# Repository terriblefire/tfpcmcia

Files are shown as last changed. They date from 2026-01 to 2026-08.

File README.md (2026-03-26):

# tfpcmcia

TerribleFire PCMCIA — a custom PCMCIA expansion card for the Amiga 1200 and Amiga 600, providing 4 MB fast RAM, an SD card interface, and 7 programmable RGB LEDs.

---

## Hardware

| Component | Part | Interface |
|---|---|---|
| Microcontroller | WCH CH32V307 (RISC-V, 144 MHz) | — |
| SPI RAM | APS6404L-3SQR, 4 MB | SPI1 @ 72 MHz |
| SD card | Standard microSD | SPI3 @ 36 MHz |
| LEDs | 7× APA102C RGB | GPIO (bit-banged) |

The card plugs into the Amiga's PCMCIA slot. The CH32V307 bridges the PCMCIA bus to an SPI RAM chip and SD card. The Amiga CPU accesses them entirely through memory-mapped reads and writes — the MCU handles all bus timing under interrupt.

---

## Memory Map

From the Amiga's perspective:

| Amiga address | Content | Notes |
|---|---|---|
| `$600000–$61FFFF` | Boot ROM (128 KB) | At power-on only; switches to SPIRAM after boot |
| `$620000–$9FFFFF` | SPIRAM (≈4 MB) | Fast RAM, available after driver init |
| `$A00000–$A001FF` | Attribute memory | PCMCIA CIS tuples (REG=1 accesses) |
| `$A20200–$A2023B` | I/O registers | Control, SPI, LED framebuffer |

The first 128 KB of SPIRAM overlaps the boot ROM window. After driver initialisation, `BOARD_CTRL` bit 0 is set, which switches that window from ROM to SPIRAM and makes the full 4 MB available as expansion memory.

---

## I/O Registers

All registers sit in PCMCIA I/O space. The Amiga's Gayle chip maps card I/O to `$A20000`; register byte offsets are relative to the card's I/O base (`0x220000`). The 68000 bus is 16 bits wide; each register occupies the upper byte of a 16-bit word (big-endian convention).

| Address | Offset | R/W | Name | Description |
|---|---|-----|---|---|
| `$A20200` | `0x200` | R/W | `SPI_DATA` | Write a byte to clock it out to the SD card; read to get the last byte clocked in |
| `$A20202` | `0x202` | W | `SPI_CS` | SD card chip select — `$00` = assert (active LOW), `$FF` = deassert |
| `$A20204` | `0x204` | R | `SPI_STATUS` | Bit 0: SD card detect (`1` = card present) |
| `$A20206` | `0x206` | R/W | `BOARD_CTRL` | Bit 0: `0` = boot ROM mapped, `1` = SPIRAM mapped; also controls LED mode |
| `$A20208` | `0x208` | R | `BOARD_ID` | Board identifier, always reads `$01` |
| `$A20220–$A2023B` | `0x220–0x23B` | W | `LED_FB` | LED framebuffer — 7 pixels × 4 bytes; see LED section |

---

## Boot Sequence

1. **CIS parsing** — Kickstart's `card.resource` reads the Card Information Structure from attribute memory (`$A00000`) and locates the `CISTPL_AMIGAXIP` (Execute-In-Place) tuple with the `AUTORUN` flag.

2. **XIP entry** — Kickstart calls `InitResident()` on the RomTag at `$600000`.

3. **Boot ROM init** — The ROM code:
   - Parses the embedded `tfpcmcia.device` (standard Amiga HUNK executable) from the ROM image
   - Allocates chip RAM, copies hunks, applies `HUNK_RELOC32` relocations
   - Calls `CacheClearU()` to flush CPU caches
   - Scans the loaded code for a RomTag and calls `InitResident()` on it

4. **Device init** — `tfpcmcia.device`:
   - Registers itself with Exec
   - Initialises the SD card via SPI (supports SDv1, SDv2, SDHC)
   - Creates an I/O task for asynchronous SD operations
   - Probes SPIRAM and, if present, adds a 1 MB block to the system free memory list (`AddMemList`, `MEMF_PUBLIC | MEMF_FAST`)
   - Scans the SD card for an RDB (Rigid Disk Block)

5. **RDB mounting** — Reads the partition table, loads filesystem handlers from LSEG blocks, creates DOS nodes via `MakeDosNode` / `AddBootNode`.

6. **DOS boot** — Calls `InitResident("dos.library")`. AmigaDOS picks the highest-priority bootable partition and continues the boot.

7. **ROM→SPIRAM switch** — After setup, the boot code copies a small trampoline onto the stack, flushes caches, jumps to the trampoline, then writes `BOARD_CTRL` bit 0 to switch the `$600000` window from ROM to SPIRAM. The full 4 MB is now available as fast RAM.

### A600 notes

On the A600 with Kickstart 3.0, the Gayle PCMCIA disable bit must be toggled in the DIAG handler to enable XIP boot. This is handled automatically by the boot ROM.

---

## SPIRAM

The 4 MB SPI RAM (APS6404L) is cached inside the CH32V307's 32 KB SRAM using a direct-mapped write-back cache:

- **512 cache lines × 64 bytes** = 32 KB cache
- **Address decomposition:** tag (7 bits) | line index (9 bits) | byte offset (6 bits)
- On a cache miss, any dirty line is evicted (written back via SPI burst) before the new line is fetched
- SPI transfers use 16-bit burst mode for maximum throughput (~9 MB/s)

From the Amiga driver's perspective, SPIRAM is transparent: ordinary memory reads and writes go through the cache without any special handling.

---

## LED System

Seven APA102C RGB LEDs are driven from two GPIO lines (clock + data) using a bit-banged serial protocol. The active LED mode is determined by `BOARD_CTRL` bit 0.

### KITT mode (bit 0 = 0, default)

Before the driver loads — and any time `BOARD_CTRL` bit 0 is clear — the firmware runs an autonomous scanner animation: a red spot bounces back and forth across all 7 LEDs with a short brightness tail, updating once per millisecond.

### Framebuffer mode (bit 0 = 1)

Once the driver sets `BOARD_CTRL` bit 0, the firmware switches to host-controlled mode. The Amiga driver paints arbitrary colours by writing to the `LED_FB` registers at `$A20220`.

#### LED framebuffer format

7 pixels, 4 bytes each (28 bytes total, `$A20220–$A2023B`). Each pixel occupies two consecutive 16-bit I/O writes:

| Write | Address offset | Upper byte [15:8] | Lower byte [7:0] |
|---|---|---|---|
| 1st | `0x220 + pixel×4` | Red | Green |
| 2nd | `0x222 + pixel×4` | Blue | Unused |

Pixel 0 is at `$A20220`, pixel 1 at `$A20224`, …, pixel 6 at `$A20238`.

---

## PCMCIA Interface (firmware)

The CH32V307 services every PCMCIA bus cycle under interrupt (`WCH-Interrupt-fast`). The interrupt handler runs entirely from RAM (`.ramtext` section) and is flattened / always-inlined to avoid register corruption in the fast-interrupt ABI.

Cycle types handled:

| Cycle | Action |
|---|---|
| Attribute memory read | Returns CIS tuple bytes (see below) |
| Common memory read, addr < 128 KB | Returns boot ROM byte pair |
| Common memory read, addr ≥ 128 KB | Returns SPIRAM data (cached) |
| Common memory write | Writes to SPIRAM (cached) |
| I/O read | Returns register value |
| I/O write | Updates register or LED framebuffer |

The Gayle chip swaps D0–D7 with D8–D15 relative to the 68000. Every value written to the data bus goes through `BUS16()` to compensate.

### CIS tuples (attribute memory)

| Tuple | Content |
|---|---|
| `CISTPL_DEVICE` (0x01) | SRAM, 250 ns, 4 MB |
| `CISTPL_VERS_1` (0x15) | Manufacturer: "TerribleFire", Product: "PCMCIA SD+RAM", Version: "1.0" |
| `CISTPL_FUNCID` (0x21) | Memory card |
| `CISTPL_AMIGAXIP` (0x91) | Execute-in-place, AUTORUN flag set |
| `CISTPL_END` (0xFF) | — |

---

## Amiga Driver (`tfpcmcia.device`)

Standard Amiga block device. Supports:

- `TD_READ64` / `TD_WRITE64` / `TD_SEEK64`
- `HD_SCSICMD`
- `NSCMD_DEVICEQUERY` / `NSCMD_TD_READ64` / `NSCMD_TD_WRITE64`

SD card geometry presented to the OS: 512-byte blocks, 16 heads, 32 sectors/track.

---

## Building

### Firmware

Open the project in MounRiver Studio (or use the provided Makefile under `firmware/`) and build for CH32V307. Flash with WCH-ISP (macOS binary included in `wchisp-macos-x64/`).

### Driver / boot ROM

```sh
cd driver
make
```

Produces `tfpcmcia.rom` — the 128 KB image that the firmware exposes as the boot ROM.

### MAME testing

The board is emulated as the `tfpcmcia` PCMCIA device:

```sh
mame a1200 -pcmcia tfpcmcia -hard2 sdcard.hdf -debug
```

To capture the driver's serial debug output:

```sh
mame a1200 -pcmcia tfpcmcia -hard2 sdcard.hdf \
  -rs232 null_modem -bitb socket.127.0.0.1:1234
# in another terminal:
nc -l 1234
```

Copy a freshly built ROM into MAME's ROM path:

```sh
cp driver/tfpcmcia.rom /path/to/mame/roms/tfpcmcia/
```

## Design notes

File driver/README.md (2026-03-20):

# TerribleFire PCMCIA Driver

Amiga device driver and boot ROM for the TerribleFire PCMCIA board — a custom PCMCIA card for the Amiga 1200 featuring a CH32V307 MCU, SD card slot, and 4MB SPIRAM.

## Overview

The board plugs into the A1200's PCMCIA slot and provides:

- **4MB SPIRAM** mapped into the PCMCIA common memory space ($600000–$9FFFFF), usable as fast RAM
- **SPI SD card interface** exposed through I/O space registers
- **128KB boot ROM** that loads and initializes the device driver at cold boot, then switches to SPIRAM mode

The CH32V307 MCU on the board handles SPI bus arbitration and SD card communication. The Amiga CPU communicates with it through memory-mapped registers in the PCMCIA I/O space.

## Memory Map

### Common Memory ($600000–$9FFFFF)

At power-on, the first 128KB ($600000–$61FFFF) contains the boot ROM. After the driver initializes, `BOARD_CTRL` bit 0 switches this region to SPIRAM, giving the full 4MB to the system.

### I/O Space Registers ($A20000+)

All registers are at even byte addresses (68000 bus convention):

| Address | Name | R/W | Description |
|---|---|-----|---|
| `$A20200`  | `SPI_DATA` | R/W | SPI data register — write a byte to clock it out, read to get the byte clocked in |
| `$A20202`  | `SPI_CS` | W | SPI chip select — `$00` = assert (active), `$FF` = deassert |
| `$A20204`  | `SPI_STATUS` | R | Status register — bit 0: SD card detect (1 = card present) |
| `$A20206`  | `BOARD_CTRL` | W | Board control — bit 0: SPIRAM mode (1 = SPIRAM, 0 = boot ROM) |
| `$A20208`  | `BOARD_ID` | R | Board identification — reads `$01` |

## Boot Sequence

1. **CIS parsing** — Kickstart's `card.resource` reads the Card Information Structure from attribute memory and finds the `CISTPL_AMIGAXIP` (Execute-In-Place) tuple
2. **XIP entry** — Kickstart calls `InitResident()` on the RomTag at `$600000`
3. **Boot ROM init** — The ROM code:
   - Parses the embedded `tfpcmcia.device` (Amiga hunk executable) from ROM
   - Allocates RAM, copies hunks, applies HUNK_RELOC32 relocations
   - Flushes the CPU caches (`CacheClearU`)
   - Scans for a RomTag in the loaded code and calls `InitResident()` on it
4. **Device init** — `tfpcmcia.device` registers itself, initializes the SD card via SPI, creates an I/O task, then scans the SD card for an RDB (Rigid Disk Block)
5. **RDB mounting** — Reads partition table, loads any filesystem handlers from LSEG blocks, creates DOS nodes via `MakeDosNode`/`AddBootNode`
6. **DOS boot** — Calls `InitResident("dos.library")` to start AmigaDOS, which picks the highest-priority bootable partition

After initialization, the boot ROM copies a small trampoline to the stack, flushes caches, jumps to it, and writes `BOARD_CTRL` to switch from ROM to SPIRAM mode. The 4MB SPIRAM is then available as expansion memory.

## MAME Testing

The board is emulated in MAME as the `tfpcmcia` PCMCIA device. To test with the A1200 emulation:

```sh
mame a1200 -pcmcia tfpcmcia -hard2 sdcard.hdf -debug
```

The MAME emulation (`tfpcmcia.cpp`) implements the full register set, SPI SD card interface, boot ROM, and SPIRAM switching. The boot ROM binary is loaded from the MAME ROM path.

To see the driver's serial debug output (`kprintf`), add a null modem on the RS-232 port and listen with netcat:

```sh
mame a1200 -pcmcia tfpcmcia -hard2 sdcard.hdf -debug \
  -rs232 null_modem -bitb socket.127.0.0.1:1234
```

In another terminal:

```sh
nc -l 1234
```

To build a new ROM and update MAME's copy:

```sh
cd driver
make
cp tfpcmcia.rom ../path/to/mame/roms/tfpcmcia/
```

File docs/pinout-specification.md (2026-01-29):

# TFPCMCIA Pin Specification
**CH32V303VCT6 PCMCIA Card - Complete Pin Assignment**

Date: 2026-01-29
Hardware Version: 1.0
Total GPIO Pins: 80 (5 ports × 16 pins)
Pins Used: 65 (81% utilization)
Pins Available: 15 (19% expansion capacity)

---

## GPIOA - SPI, Audio, Debug, Status (13/16 used)

| Pin | Signal | Direction | Function | Configuration | Notes |
|-----|---|---|---|---|---|
| PA0 | STATUS_LED | Output | Status indicator LED | Push-pull, 50MHz | Optional, active HIGH |
| PA1 | SPIRAM_CS | Output | SPI RAM chip select | Push-pull, 50MHz | Manual GPIO, active LOW |
| PA2 | **READY** | **Output** | **PCMCIA READY signal** | **Push-pull, 50MHz** | **Active HIGH when ready** |
| PA3 | - | - | **AVAILABLE** | - | - |
| PA4 | DAC_OUT1/BVD2 | Output | Audio to Amiga | Analog | 12-bit DAC, connects to PCMCIA BVD2 |
| PA5 | SPI1_SCK | Output | SPI RAM clock | Alternate function | 72 MHz max |
| PA6 | SPI1_MISO | Input | SPI RAM data in | Alternate function | Floating |
| PA7 | SPI1_MOSI | Output | SPI RAM data out | Alternate function | 72 MHz max |
| PA8 | BOOTLOADER | Input | Programming mode detect | Pull-down | Active HIGH enters programming |
| PA9 | - | - | **AVAILABLE** | - | - |
| PA10 | USART1_RX | Input | Debug UART receive | Alternate function | **RESERVED** |
| PA11 | USART1_TX | Output | Debug UART transmit | Alternate function | **RESERVED** |
| PA12 | - | - | **AVAILABLE** | - | - |
| PA13 | SWDIO | I/O | SWD debug data | Alternate function | **RESERVED** |
| PA14 | SWCLK | Input | SWD debug clock | Alternate function | **RESERVED** |
| PA15 | SD_CD | Input | SD card detect | Pull-up | Active LOW when card inserted |

**Interface Summary:**
- **SPI1 (SPI RAM):** PA1 (CS), PA5 (SCK), PA6 (MISO), PA7 (MOSI) @ 72 MHz max
- **Audio:** PA4 (DAC → BVD2)
- **Debug:** PA10-PA11 (UART), PA13-PA14 (SWD)
- **Status:** PA0 (LED), PA2 (READY), PA8 (Boot mode), PA15 (SD detect)
- **Available:** PA3, PA9, PA12

---

## GPIOB - Address, Control Signals (16/16 used) ⚠️ **FULLY ALLOCATED**

| Pin | Signal | Direction | Function | Configuration | Notes |
|-----|---|---|---|---|---|
| PB0 | A16 | Input | Address bit 16 | Floating | |
| PB1 | A17 | Input | Address bit 17 | Floating | |
| PB2 | A18 | Input | Address bit 18 | Floating | |
| PB3 | A19 | Input | Address bit 19 | Floating | |
| PB4 | A20 | Input | Address bit 20 | Floating | |
| PB5 | A21 | Input | Address bit 21 | Floating | 22-bit total (4MB) |
| PB6 | CE1/UDS | Input | Upper Data Strobe | Pull-up | **EXTI6 interrupt**, active LOW |
| PB7 | OE | Input | Memory Output Enable | Pull-up | Memory read cycle, active LOW |
| PB8 | WE | Input | Memory Write Enable | Pull-up | Memory write cycle, active LOW |
| PB9 | CE2/LDS | Input | Lower Data Strobe | Pull-up | **EXTI9 interrupt**, active LOW |
| PB10 | REG | Input | Attribute memory select | Pull-up | 0=Common, 1=Attribute |
| PB11 | IOR | Input | I/O Read strobe | Pull-up | I/O read cycle, active LOW |
| PB12 | IOW | Input | I/O Write strobe | Pull-up | I/O write cycle, active LOW |
| PB13 | RESET | Input | Card reset | Pull-up | Active LOW |
| PB14 | WAIT | Output | Wait state control | Push-pull, 50MHz | LOW=insert waits, HIGH=no wait |
| PB15 | IOIS16 | Output | 16-bit I/O indicator | Push-pull, 50MHz | Optional use |

**Interface Summary:**
- **Address High:** PB0-PB5 (A16-A21)
- **Memory Control:** PB6 (UDS), PB7 (OE), PB8 (WE), PB9 (LDS), PB10 (REG)
- **I/O Control:** PB11 (IOR), PB12 (IOW)
- **System Control:** PB13 (RESET), PB14 (WAIT), PB15 (IOIS16)
- **Interrupts:** EXTI6 (PB6/UDS), EXTI9 (PB9/LDS) → both trigger PCMCIA_Handler

**Control Signal Groups:**
1. **Memory Access:** OE (read) OR WE (write)
2. **I/O Access:** IOR (read) OR IOW (write)
3. **Byte/Word Select:** UDS+LDS (word), UDS only (upper byte), LDS only (lower byte)

---

## GPIOC - SD Card SPI (4/16 used)

| Pin | Signal | Direction | Function | Configuration | Notes |
|-----|---|---|---|---|---|
| PC0 | - | - | **AVAILABLE** | - | - |
| PC1 | - | - | **AVAILABLE** | - | - |
| PC2 | - | - | **AVAILABLE** | - | - |
| PC3 | - | - | **AVAILABLE** | - | - |
| PC4 | - | - | **AVAILABLE** | - | - |
| PC5 | - | - | **AVAILABLE** | - | - |
| PC6 | - | - | **AVAILABLE** | - | - |
| PC7 | - | - | **AVAILABLE** | - | - |
| PC8 | - | - | **AVAILABLE** | - | - |
| PC9 | SD_CS | Output | SD card chip select | Push-pull, 50MHz | Manual GPIO, active LOW |
| PC10 | SPI3_SCK | Output | SD card SPI clock | Alternate function | 36 MHz max |
| PC11 | SPI3_MISO | Input | SD card SPI data in | Alternate function | Floating |
| PC12 | SPI3_MOSI | Output | SD card SPI data out | Alternate function | 36 MHz max |
| PC13 | - | - | **AVAILABLE** | - | - |
| PC14 | - | - | **AVAILABLE** | - | - |
| PC15 | - | - | **AVAILABLE** | - | - |

**Interface Summary:**
- **SPI3 (SD Card):** PC9 (CS), PC10 (SCK), PC11 (MISO), PC12 (MOSI) @ 36 MHz max
- **Available:** PC0-PC8, PC13-PC15 (12 pins for future expansion)

---

## GPIOD - Data Bus (16/16 used) ⚠️ **FULLY ALLOCATED**

| Pin | Signal | Direction | Function | Configuration | Notes |
|-----|---|---|---|---|---|
| PD0 | D0 | I/O | Data bit 0 | Bidirectional | Start as input floating |
| PD1 | D1 | I/O | Data bit 1 | Bidirectional | Switch to output on read |
| PD2 | D2 | I/O | Data bit 2 | Bidirectional | |
| PD3 | D3 | I/O | Data bit 3 | Bidirectional | |
| PD4 | D4 | I/O | Data bit 4 | Bidirectional | |
| PD5 | D5 | I/O | Data bit 5 | Bidirectional | |
| PD6 | D6 | I/O | Data bit 6 | Bidirectional | |
| PD7 | D7 | I/O | Data bit 7 | Bidirectional | |
| PD8 | D8 | I/O | Data bit 8 | Bidirectional | |
| PD9 | D9 | I/O | Data bit 9 | Bidirectional | |
| PD10 | D10 | I/O | Data bit 10 | Bidirectional | |
| PD11 | D11 | I/O | Data bit 11 | Bidirectional | |
| PD12 | D12 | I/O | Data bit 12 | Bidirectional | |
| PD13 | D13 | I/O | Data bit 13 | Bidirectional | |
| PD14 | D14 | I/O | Data bit 14 | Bidirectional | |
| PD15 | D15 | I/O | Data bit 15 | Bidirectional | |

**Interface Summary:**
- **Data Bus:** Full 16-bit on single port for atomic operations
- **Access:** Read via `GPIOD->INDR`, write via `GPIOD->OUTDR`
- **Mode Control:** `CFGLR` (D0-D7), `CFGHR` (D8-D15)
- **Configuration Values:**
  - Input: `0x44444444` (floating input)
  - Output: `0x33333333` (push-pull, 50MHz)

---

## GPIOE - Address Bus Low (16/16 used) ⚠️ **FULLY ALLOCATED**

| Pin | Signal | Direction | Function | Configuration | Notes |
|-----|---|---|---|---|---|
| PE0 | A0 | Input | Address bit 0 | Floating | |
| PE1 | A1 | Input | Address bit 1 | Floating | |
| PE2 | A2 | Input | Address bit 2 | Floating | |
| PE3 | A3 | Input | Address bit 3 | Floating | |
| PE4 | A4 | Input | Address bit 4 | Floating | |
| PE5 | A5 | Input | Address bit 5 | Floating | |
| PE6 | A6 | Input | Address bit 6 | Floating | |
| PE7 | A7 | Input | Address bit 7 | Floating | |
| PE8 | A8 | Input | Address bit 8 | Floating | |
| PE9 | A9 | Input | Address bit 9 | Floating | |
| PE10 | A10 | Input | Address bit 10 | Floating | |
| PE11 | A11 | Input | Address bit 11 | Floating | |
| PE12 | A12 | Input | Address bit 12 | Floating | |
| PE13 | A13 | Input | Address bit 13 | Floating | |
| PE14 | A14 | Input | Address bit 14 | Floating | |
| PE15 | A15 | Input | Address bit 15 | Floating | |

**Interface Summary:**
- **Address Low:** PE0-PE15 (A0-A15)
- **Combined with GPIOB[0-5]:** 22-bit address (A0-A21) = 4MB address space
- **Address Read:** `addr = GPIOE->INDR | ((GPIOB->INDR & 0x3F) << 16)`

---

## Pin Usage Statistics

| Port | Total Pins | Used | Available | Utilization |
|---|---|---|---|---|
| GPIOA | 16 | 13 | 3 | 81% |
| GPIOB | 16 | 16 | 0 | **100%** ✓ |
| GPIOC | 16 | 4 | 12 | 25% |
| GPIOD | 16 | 16 | 0 | **100%** ✓ |
| GPIOE | 16 | 16 | 0 | **100%** ✓ |
| **Total** | **80** | **65** | **15** | **81%** |

---

## Functional Pin Grouping

### Address Bus (22 bits)
- **A0-A15:** GPIOE[0-15] (lower 16 bits)
- **A16-A21:** GPIOB[0-5] (upper 6 bits)
- **Address Space:** 0x000000 - 0x3FFFFF (4 MB)

### Data Bus (16 bits)
- **D0-D15:** GPIOD[0-15] (full 16-bit data)
- **Advantage:** Single port = atomic 16-bit read/write

### Memory Control Signals
- **CE1/UDS:** GPIOB[6] - Upper Data Strobe, EXTI6 interrupt
- **CE2/LDS:** GPIOB[9] - Lower Data Strobe, EXTI9 interrupt
- **OE:** GPIOB[7] - Memory read cycle
- **WE:** GPIOB[8] - Memory write cycle
- **REG:** GPIOB[10] - Attribute memory select

### I/O Control Signals
- **IOR:** GPIOB[11] - I/O read cycle
- **IOW:** GPIOB[12] - I/O write cycle
- **IOIS16:** GPIOB[15] - 16-bit I/O indicator

### System Control
- **RESET:** GPIOB[13] - Card reset input
- **WAIT:** GPIOB[14] - Wait state output (cycle extension)
- **READY:** GPIOA[2] - Card ready output (operational status)

### SPI1 Interface (SPI RAM @ 72 MHz)
- **CS:** GPIOA[1] (manual control)
- **SCK:** GPIOA[5]
- **MISO:** GPIOA[6]
- **MOSI:** GPIOA[7]
- **Bus:** APB2 (144 MHz ÷ 2 = 72 MHz max)

### SPI3 Interface (SD Card @ 36 MHz)
- **CS:** GPIOC[9] (manual control)
- **SCK:** GPIOC[10]
- **MISO:** GPIOC[11]
- **MOSI:** GPIOC[12]
- **Bus:** APB1 (72 MHz ÷ 2 = 36 MHz max)

### Audio Interface
- **DAC_OUT1:** GPIOA[4] - 12-bit DAC output to PCMCIA BVD2 pin

### Debug/Programming
- **UART:** GPIOA[10] (RX), GPIOA[11] (TX)
- **SWD:** GPIOA[13] (SWDIO), GPIOA[14] (SWCLK)
- **Bootloader:** GPIOA[8] - Programming mode detect

### Status Indicators
- **Status LED:** GPIOA[0] - General status indicator
- **SD Detect:** GPIOA[15] - SD card presence (LOW = inserted)
- **READY:** GPIOA[2] - Card operational status (HIGH = ready)

---

## Available Pins for Future Expansion

### GPIOA (3 pins)
- PA3
- PA9
- PA12

### GPIOC (12 pins)
- PC0, PC1, PC2, PC3, PC4, PC5, PC6, PC7, PC8
- PC13, PC14, PC15

**Total Available:** 15 pins

**Potential Future Uses:**
- Additional I/O ports
- Hardware flow control signals
- Additional status LEDs
- External interrupt inputs
- PWM outputs
- Additional SPI/I2C interfaces

---

## Pin Configuration Register Values

### Quick Reference

**Input Floating (Address/Data read):**
```c
0x44444444  // Each nibble = 0x4 (floating input)
```

**Output Push-Pull 50MHz:**
```c
0x33333333  // Each nibble = 0x3 (push-pull, 50MHz)
```

**Input Pull-Up (Control signals):**
```c
GPIO_Mode_IPU  // Use HAL functions for non-contiguous pins
```

**Analog (DAC):**
```c
GPIO_Mode_AIN  // Analog mode
```

**Alternate Function Push-Pull:**
```c
GPIO_Mode_AF_PP  // For SPI SCK/MOSI pins
```

---

## PCMCIA Connector Mapping

### Key PCMCIA Pins

| PCMCIA Pin | Signal | CH32 Pin | Direction | Notes |
|---|---|---|---|---|
| 16 | READY | PA2 | Output | Active HIGH when ready |
| 36 | CD1 | - | - | Hard-wired to GND on PCB |
| 43 | OE | PB7 | Input | Memory read enable |
| 44 | WE | PB8 | Input | Memory write enable |
| 59 | WAIT | PB14 | Output | Active LOW inserts waits |
| 60 | IOIS16 | PB15 | Output | 16-bit I/O indicator |
| 61 | REG | PB10 | Input | Attribute memory select |
| 62 | BVD2 | PA4 | Output | Audio output via DAC |
| 63 | CD2 | - | - | Hard-wired to GND on PCB |
| 7,39 | CE1/UDS | PB6 | Input | Upper data strobe |
| 24,56 | CE2/LDS | PB9 | Input | Lower data strobe |
| Various | A0-A21 | PE0-15, PB0-5 | Input | 22-bit address bus |
| Various | D0-D15 | PD0-15 | I/O | 16-bit data bus |

---

## Interrupt Configuration

### EXTI Lines

| EXTI Line | GPIO Pin | Signal | Trigger | Priority | Handler |
|---|---|---|---|---|---|
| EXTI6 | PB6 | CE1/UDS | Falling edge | 0 (highest) | PCMCIA_Handler |
| EXTI9 | PB9 | CE2/LDS | Falling edge | 0 (highest) | PCMCIA_Handler |

**Notes:**
- Both interrupts share IRQ handler: `EXTI9_6_IRQn`
- Use WCH fast interrupt mode: `SetVTFIRQ()`
- Handler clears both flags: `EXTI->INTFR = EXTI_Line6 | EXTI_Line9`
- Either UDS or LDS falling triggers the handler

---

## Timing Critical Paths

### Bus Cycle Timing (Target: <120ns)

1. **Interrupt Latency:** ~55ns (WCH-Interrupt-fast mode)
2. **Address Read:** ~14ns (2 GPIO port reads)
3. **Memory Decode:** ~20ns (if/else logic)
4. **Data Output:** ~21ns (GPIO mode switch + write)
5. **Total:** ~110ns ✓ (10ns margin)

### Critical Registers

**Direct access for speed (no HAL):**
- `GPIOE->INDR` - Address low (A0-A15)
- `GPIOB->INDR` - Address high (A16-A21) + control signals
- `GPIOD->INDR` - Data bus read
- `GPIOD->OUTDR` - Data bus write
- `GPIOD->CFGLR/CFGHR` - Data bus direction
- `EXTI->INTFR` - Interrupt flag clear

---

## Design Notes

### Address Space (Card Perspective)
```
0x000000 - 0x03FFFF: ROM (256KB, Flash-based)
0x040000 - 0x1FFFFF: SPI RAM (1.75MB, optional)
0x1F0000 - 0x1F00FF: I/O Ports (256 bytes)
0x200000 - 0x3FFFFF: Unmapped
Attribute Memory: 512 bytes (REG=1)
```

### Amiga Memory Map
```
$600000 - $63FFFF: ROM
$640000 - $7FFFFF: SPI RAM
$9F0000 - $9F00FF: I/O Ports
$A00000 - $A001FF: Attribute Memory
```

### Signal Polarity Reference

**Active LOW:**
- All PCMCIA control inputs (OE, WE, IOR, IOW, UDS, LDS, RESET)
- Chip selects (SPIRAM_CS, SD_CS)
- SD card detect (SD_CD)
- WAIT output

**Active HIGH:**
- READY output
- Status LED
- Data bus (when driven)
- IOIS16 (when asserted)

---

## Revision History

| Version | Date | Changes |
|---|---|---|
| 1.0 | 2026-01-29 | Initial pinout specification |
|  |  | - Added IOR/IOW on PB11/PB12 |
|  |  | - Added READY on PA2 |
|  |  | - Added SD_CD on PA15 |

---

**End of Pin Specification**

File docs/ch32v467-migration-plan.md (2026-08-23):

# CH32V307VCT6 + APS6404L → CH32V467VET6 Migration Plan

Date: 2026-08-15 (revised 2026-08-22)
Source: `docs/CH32V407DS0.PDF` (CH32V407/V467 Datasheet V1.2)
Status: schematic and board connectivity complete — see §10.

Goal: replace the CH32V307VCT6 **and** the external APS6404L SPI RAM with a single
CH32V467VET6 (8 MB on-chip PSRAM), keeping all existing tfpcmcia functionality,
with **every Amiga-facing pin on a 5 V-tolerant (FT) pad**.

---

## 1. What the silicon actually forces

### 1.1 Part selection

Only one variant is viable:

| Model | Pins | GPIO | PSRAM | Verdict |
|---|---|---|---|---|
| CH32V467**VET6** | LQFP100 14×14 0.5 mm | 76 | **8 MB** | ✅ the only option |
| CH32V467WEU6 | QFN68 8×8 | 54 | 8 MB | ❌ need ~63 GPIO |
| CH32V467RET6 | LQFP64 7×7 | 48 | 4 MB only | ❌ |

The LQFP100 land pattern is **identical to the current CH32V307VCT6** — the footprint
does not change, only the netlist and routing.

Other deltas vs. the V307: 200 MHz core (vs 144), 200 KB SRAM (vs 32/64 KB),
992 KB flash, and PSRAM linearly memory-mapped at **`0x8000_0000`–`0x8080_0000`**.

### 1.2 Package pinout deltas (V307VCT6 → V467VET6)

The differences are confined to pins 38–55 plus 73/74:

| Pin | CH32V307VCT6 | CH32V467VET6 |
|-----|---|---|
| 38 | PE7 | PE8 |
| 39 | PE8 | PE9 |
| 40 | PE9 | **VDDK** |
| 41 | PE10 | VSS |
| 42–45 | PE11–PE14 | **MDIRN / MDIRP / MDITN / MDITP** (Ethernet PHY) |
| 46 | PE15 | VDD |
| 47 | PB10 | VSS |
| 48 | PB11 | **VDD18** (PSRAM 1.8 V rail — `PE7` on the V407) |
| 49 | VSS | PB10 |
| 50 | VDD | PB11 |
| 51 | PB12 | **PD8** |
| 52–55 | PB13–PB15, PD8 | PB12–PB15 |
| 73 | NC | **PE10** |
| 74 | VSS | **PE11** |

⚠️ **Pins 73/74 are easy to miss.** The current board ties pad 74 to GND (it is
`VSS_2` in the STM32F103VET6 library part). On the V467 that pad is **PE11** — a
GPIO. Leaving it strapped to ground would short an output. Pad 73 goes from NC to
PE10.

**Consequence: `PE7`, `PE13`, `PE14`, `PE15` do not exist on any CH32V407/V467 package.**
Port E is only `PE0–PE6` + `PE8–PE12` = 12 pins.

> The current design puts A0–A15 on PE0–PE15 for an atomic single-port address read.
> **That is no longer possible** — and it can't be recovered by moving things around,
> because Port D (the only remaining contiguous 16-bit port) holds the data bus.
> Address reassembly in the ISR is unavoidable. See §5.

We are not using Ethernet, so pins 42–45 are left NC (no magnetics, no RJ45).

### 1.3 5 V tolerance map (CH32V467VET6)

Datasheet Table 2-1, `I/O structure` column: `FT` = 5 V tolerant, `HS` = 100 MHz
capable. Absolute max input on non-FT pins is `VDD + 0.3 V`.

**5 V tolerant (53 pins):**

| Port | FT pins | Count |
|---|---|---|
| A | PA8, PA9, PA10, PA13, PA14, PA15 | 6 |
| B | PB2, PB3, PB4, PB5, PB8–PB15 | 12 |
| C | PC6–PC12 | 7 |
| D | PD0–PD15 | **16** |
| E | PE0–PE6, PE8–PE12 | 12 |

**NOT 5 V tolerant (23 pins):** PA0–PA7, PA11, PA12 (USB1), PB0, PB1,
**PB6, PB7 (USBHS2 D−/D+)**, PC0–PC5, PC13–PC15.

This kills four placements in the current design outright:

- `CE1` on **PB6** and `OE` on **PB7** — these are the USB HS2 PHY pads on this part.
- `A16`/`A17` on **PB0/PB1**.
- `READY` on **PA2**.

---

## 2. Pin budget

Amiga-facing signals: **49**
- A0–A21 (22 in), D0–D15 (16 bidir), CE1/CE2/OE/WE/IORD/IOWR/REG/RESET (8 in),
  WAIT/READY/IOCS16 (3 out).

All 49 land on FT pads. The BVD2 audio output was the one exception; the audio stage
has since been removed from the design, so there is no longer any non-FT Amiga-facing
signal at all (see §6.4).

Available FT pins: **53**, less PD0–PD15 for the data bus = 37, less PE12 (BOOT0,
needs a pull-down and must stay low at power-up) = 36, less PA13/PA14 (SWD) = **34**.

**34 available vs 33 needed. One spare.** It fits — but only because dropping the
SPI RAM frees SPI1 (PA5/PA6/PA7, non-FT) for the SD card, which in turn releases
PC10/PC11/PC12 (FT) for the bus. That swap is what makes the whole thing close.

Everything that isn't Amiga-facing fits comfortably on the 23 non-FT pins:
SD SPI1, SD_CS, SD_CD, LED clk/data, 2 status LEDs, debug UART — 11 of 23 used.

---

## 3. Option A — pure re-map, no external glue *(recommended)*

All 33 5 V signals on FT pads. No added parts. Removes the APS6404L from the BOM.
See §7 for the full map and §7.1 for how the layout was derived.

**Pros:** no BOM additions, SWD retained, A0 retained, identical footprint, every
control-signal bitmask in `pcmcia.h` survives unchanged.
**Cons:** 1 spare FT pin (PB2); address reassembly costs ~12 instructions in the
ISR instead of 5, and the ISR needs a third GPIO read.

## 4. Option B — Option A plus slack

Two independent levers, either or both:

- **Drop A0.** It is already masked off in every firmware path
  (`RomMask = 0x1FFFE`, `SpiRamMask = 0x3FFFFE`); byte selection comes from
  UDS/LDS. Frees 1 FT pin.
- **Give up SWD** (PA13/PA14) and program via the WCH USB bootloader plus the debug
  UART. Frees 2 FT pins. ⚠️ **The USB breakout (JP1) has since been removed**, so this
  lever now costs a board change to expose PA11/PA12 again — it is no longer free.

Taking both gives **3–4 spare FT pins**, which is the difference between "fits" and
"fits with room for a future signal". Recommended if you want any expansion capacity.

## 5. Option C — external address buffers *(considered, not recommended)*

Buffering A0–A21 through 2× 74LVC16244 (5 V-input tolerant at VCC = 3.3 V) would
let address bits land on non-FT pins and free up FT pads.

**But it buys nothing structurally.** The atomic 16-bit address read cannot be
restored at any price — Port D is the data bus and Port E is truncated to 12 pins,
so no port can hold A0–A15 regardless of what the buffers allow. You would pay two
extra ICs, board area on a PCMCIA card, and ~4 ns of propagation delay for pin
freedom you don't actually need once the SD card moves to SPI1.

Skip it.

---

## 6. Orthogonal decisions (independent of pin mapping)

### 6.1 8 MB PSRAM vs a 4 MB window

The Amiga PCMCIA common-memory window (`$600000`–`$9FFFFF`) is 4 MB, and the card
only receives A0–A21. **You cannot linearly expose more than 4 MB**, so the extra
4 MB needs a decision:

- **6.1a** Map 4 MB linearly (drop-in behaviour), use the other 4 MB as an SD read
  cache / RAM disk. *Recommended* — simple, and AmigaOS gets a normal contiguous
  `AddMemList` block.
- **6.1b** Bank-switch the upper 4 MB via a `BOARD_CTRL` bit. Gives 8 MB of storage
  but banked RAM is useless as system fast RAM.

**The real win here is not capacity, it's latency** — see 6.2.

### 6.2 Firmware: delete the SPI RAM cache entirely

PSRAM is linearly memory-mapped at `0x8000_0000`, so `SPIRAM_Read16()` collapses to
a single load:

```c
*(volatile uint16_t *)(0x80000000u + (addr & 0x3FFFFEu))
```

That deletes `spiram.c` / `spiram.h`, including the 32 KB direct-mapped write-back
cache. Today a cache miss costs a 64-byte SPI burst at 72 MHz ≈ **7 µs**, doubled to
~14 µs if the evicted line is dirty — the Amiga sits in `/WAIT` for all of it.
PSRAM `tRC` is **60 ns**.

This dwarfs everything else. The ~30 ns of extra address reassembly (~12 instructions
at 200 MHz vs 5 at 144 MHz) is noise by comparison, and `/WAIT` is asserted at the top
of the handler anyway, so the cycle extends rather than failing.

### 6.3 ⚠️ PSRAM lot-code caveat — verify before ordering

Datasheet note under Table 3-42:

> Only for CH32V467 chips **with the fifth last digit of the lot number not 0**, PSRAM
> can support clocks exceeding 200 MHz, support variable and instruction access, and
> **support byte writing**.

**Byte writing matters directly**: `PCMCIA_Handler` does `SPIRAM_Write8()` on UDS-only
and LDS-only cycles. On an older lot you would need a read-modify-write (2 PSRAM
cycles, ~120 ns) instead of a single store. Confirm the lot code with the supplier, or
budget for the RMW path.

### 6.4 Audio output — removed

*Superseded.* The original design drove PCMCIA pin 62 (BVD2) from DAC1_OUT on PA4
through an MCP6001 buffer. DAC1_OUT is PA4 and DAC2_OUT is PA5; both are non-FT with
no remap, so this was the one Amiga-facing signal that could not sit on a 5 V-tolerant
pad, and it needed AC-coupling or a series clamp resistor.

**The audio stage was deleted** (IC4 + C13/C14 + R4/R5/R6). With it gone, PA4 is free
and **every Amiga-facing pin is now on an FT pad** — no coupling caps, no clamp
resistors, no compromise. PCMCIA pin 62 is left entirely unconnected.

If audio is ever wanted back, it returns as this same problem: DAC1 on PA4 (PA5 is
SPI1_SCK and belongs to the SD card), AC-coupled into the mixer.

### 6.5 Power

- **New:** VDD18 (pin 48) — 0.1 µF ∥ 2.2 µF. This is the PSRAM rail, generated
  internally from VDD by LDO_1.8V.
- **Changed:** main VDD bulk must rise from ≥4.7 µF to **≥10 µF**, and total VDD
  capacitance must be ≥ (VDDK + VDD18 capacitance).
- VDDK (pin 40) unchanged: 0.1 µF ∥ 2.2 µF.
- 8 MB of PSRAM plus a 200 MHz core is a meaningful current increase over the
  V307 + APS6404L. **Measure Icc against the PCMCIA slot budget** on both A600 and
  A1200 before committing.

### 6.6 BOOT0

BOOT0 is PE12 on this part but still lands on **pin 94**, same as the V307 — the
existing pull-down carries over unchanged. Do not use PE12 as a bus pin: an Amiga
address line driving it high at power-up would drop the card into the bootloader.

---

## 7. Recommended full pin map (Option A)

| Pin | Signal | FT | Note |
|-----|---|----|---|
| PD0–PD15 | D0–D15 | ✅ | unchanged from current design |
| PE0–PE6 | A0–A6 | ✅ | |
| PE8–PE11 | A8–A11 | ✅ | PE7 does not exist → A7 hole, filled from PB3 |
| PE12 | *BOOT0* | ✅ | pull-down, reserved |
| PB3 | A7 | ✅ | |
| PB4, PB5 | A20, A21 | ✅ | |
| PB8–PB15 | A12–A19 | ✅ | |
| PB2 | *spare* | ✅ | only free FT pin |
| PC6 | CE1 | ✅ | EXTI6 |
| PC7 | OE | ✅ | |
| PC8 | WE | ✅ | |
| PC9 | CE2 | ✅ | EXTI9 |
| PC10 | REG | ✅ | |
| PC11 | IORD | ✅ | |
| PC12 | IOWR | ✅ | |
| PA15 | RESET | ✅ | EXTI15 → `EXTI15_10`, same vector as today |
| PA8 | WAIT | ✅ | output |
| PA9 | READY | ✅ | output |
| PA10 | IOCS16 | ✅ | output |
| PA5/PA6/PA7 | SD_CLK / SD_MISO / SD_MOSI (SPI1) | ❌ | 3.3 V SD card |
| PC4 | SD_CS | ❌ | |
| PC5 | SD_CD | ❌ | moved from PA15 |
| PC0/PC1 | LED_CLK / LED_DO (APA102) | ❌ | as today |
| PB0/PB1 | LED1 / LED2 status | ❌ | |
| PB6/PB7 | debug UART (USART1 remap) | ❌ | *never* connect to the Amiga bus |
| PA13/PA14 | SWDIO / SWCLK | ✅ | retained — with USB gone, the only way in |
| PA4, PA11, PA12 | *spare* | ❌ | freed by removing the audio stage and USB |
| 42–45 | MDIRN/MDIRP/MDITN/MDITP | — | NC, Ethernet unused |

**Spare:** PB2 (FT — the only one), PA0–PA4, PA11, PA12, PC2, PC3, PC13–PC15 (non-FT).

**Programming access:** SWD on PA13/PA14 and the debug UART on PB6/PB7, both brought
out on the 6-way DEBUG header. The USB breakout jumper was removed, so the WCH USB
bootloader is no longer reachable — SWD and UART are the only routes in.

### 7.1 Why this layout — three GPIO reads and three extracts is the floor

Three GPIO reads are unavoidable. 22 address pins + 7 hot control signals = 29
inputs, but the two largest FT ports hold only 12 (PB) + 11 (PE) = 23 pins. So
control needs its own port — and PC6–PC12 is exactly 7 FT pins, a perfect fit.
That leaves **PE (11) + PB (12) = 23 pins for 22 address bits**: there is no choice
about which ports carry the address, and no arrangement gets back to two reads.

Both address ports have gaps — PE breaks at PE7 (1-bit hole), PB breaks at PB6/PB7
(2-bit hole). One shift+mask per port would leave holes in the assembled address.
PE is fully consumed, so PB's 2-bit hole cannot be filled from anywhere else:
**PB needs two extracts, PE needs one. Three is the minimum.**

The optimisation is choosing PB's first shift so that a single extract both fills
PE's hole *and* covers the 8-bit run: at `<< 4`, PB3 lands on A7 and PB8 lands on
A12.

### 7.2 ISR address reassembly

```c
/*  PE0–PE6  -> A0–A6     (in place)
 *  PE8–PE11 -> A8–A11    (in place; PE7 absent -> A7 hole)
 *  PB3      -> A7        (fills the hole, same shift as the run below)
 *  PB8–PB15 -> A12–A19
 *  PB4,PB5  -> A20,A21                                                */
#define ADDR_E_MASK   0x00000F7Fu  /* PE bits 0-6, 8-11                */
#define ADDR_B1_MASK  0x000FF080u  /* after <<4  : A7, A12-A19         */
#define ADDR_B2_MASK  0x00300000u  /* after <<16 : A20, A21 (bare lui) */

uint32_t e = GPIOE->INDR;
uint32_t b = GPIOB->INDR;
uint32_t addr = (e & ADDR_E_MASK)
              | ((b <<  4) & ADDR_B1_MASK)
              | ((b << 16) & ADDR_B2_MASK);
```

~12 instructions vs 5 today: ≈60 ns at 200 MHz against ≈35 ns at 144 MHz. The third
APB read is likely a larger share of that +25 ns than the shifts are.

### 7.3 Control masks are unchanged

Ordering the control signals on PC as above keeps every bitmask in `pcmcia.h`
byte-for-byte identical to the current design:

| Pin | Signal | Mask | Current pin |
|-----|---|---|---|
| PC6 | CE1 | `0x0040` | PB6 |
| PC7 | OE | `0x0080` | PB7 |
| PC8 | WE | `0x0100` | PB8 |
| PC9 | CE2 | `0x0200` | PB9 |
| PC10 | REG | `0x0400` | PB10 |
| PC11 | IORD | `0x0800` | PB11 |
| PC12 | IOWR | `0x1000` | PB12 |

`STROBE_MASK`, `MEM_MASK`, `IO_MASK`, `ACCESS_MASK`, `OE_MASK`, `WE_MASK`,
`REG_MASK`, `IOR_MASK`, `IOW_MASK` all keep their values. CE1/CE2 still land on
EXTI6/EXTI9 → the same `EXTI9_5` vector and the same `SetVTFIRQ()` registration.

The ISR diff reduces to: `GPIOB->INDR` → `GPIOC->INDR` for control, the new address
block, and `WAIT` moving from `GPIOB` to `GPIOA` bit 8.

`RESET_MASK` disappears — RESET is only serviced by its own EXTI handler and was
never read in the hot path.

---

## 8. Firmware work items

1. Rewrite `gpio.h` pin definitions and `gpio.c` port configuration.
2. `pcmcia.c`: new address reassembly (§7.2); control reads move from `GPIOB->INDR`
   to `GPIOC->INDR` — **mask values are unchanged** (§7.3); `WAIT` assert/deassert
   moves from `GPIOB` bit 14 to `GPIOA` bit 8.
3. EXTI: retarget lines 6 and 9 from Port B to Port C in AFIO (vector stays
   `EXTI9_5`); RESET from PB13 → PA15, i.e. EXTI13 → EXTI15, vector stays
   `EXTI15_10` — update the `EXTI->INTFR = EXTI_Line13` clear in
   `PCMCIA_ResetHandler`.
4. Delete `spiram.c` / `spiram.h`; replace with direct `0x8000_0000` accesses.
5. SD card: SPI3 (PC10–PC12) → SPI1 (PA5–PA7), CS PC9 → PC4, CD PA15 → PC5.
   See §8.1.
6. Clock tree: 144 MHz → 200 MHz; re-check flash wait states and the `DELAY_100NS` /
   `DELAY_140NS` nop counts, which are hand-tuned for 144 MHz and **will be wrong**.
7. PSRAM init: enable LDO_1.8V, configure the PSRAM controller, size/probe 8 MB.
8. Switch the SDK from `ch32v30x` to the V4xx peripheral library.
9. **LED count 7 → 8.** An eighth APA102 (LED10) was added to the chain. Update
   `led_fb[7]` and the `REG_LED_FB_BASE + 28u` window in `pcmcia.c`, and
   `KITT_NUM_LEDS` in `led.c`. The I/O framebuffer window grows to
   `$A20220–$A2023F`; the README register table needs the same change.

### 8.0 Port status (2026-08-23, rev 2 — official V4x7 SDK)

Ported to the **official WCH CH32V4x7 SDK** (`openwch/ch32v407_ch32v467`,
`EVT/EXAM/SRC`), replacing the earlier V307-SDK build: the V4x7 clock tree
(SYSPLL sources, HPRE divider, 20 MHz HSI) is materially different from the
V307 and the reference manual (`docs/CH32V407RM.PDF`, fetched from WCH) plus
the SDK's PSRAM example made the real init requirements clear. Builds clean in
the `terriblefire78/mrs` Docker image. Key facts and choices:

- **PSRAM needs explicit init** — it is NOT usable out of reset. `PSRAM_Init()`
  enables the HB clock, programs timing (TRC=0x0C = 60 ns at 200 MHz) and sets
  the 200M read/write latencies. Read latency is **fixed** (variable-latency
  read is a good-lot-only feature per DS Table 3-42); switch to
  `Read_Variable` on confirmed lots.
- **PSRAM is clocked by SYSCLK** (pre-HPRE). Custom clock config
  `SYSCLK_200MHz_HCLK_200MHz_HSI`: HSI 20 MHz × PLL 10 = 200 MHz, HPRE÷1 —
  **core AND PSRAM both at their any-lot 200 MHz maxima**. The ISR runs 39%
  faster than the proven 144 MHz V307 timing; nop delays rescaled (14/20).
- **Vector table verified**: EXTI9_5_IRQn=39, EXTI15_10_IRQn=56 — identical to
  the V307, so the EXTI binding carries over unchanged.
- **SD on SPI1 at 12.5 MHz** (PCLK2 200/16; SD spec allows 25).
- `PSRAM_Write8` is a 16-bit read-modify-write — safe on every lot (§6.3).
- RVV CSR helpers in `core_riscv.c` are compiled out (GCC 8.2 assembler
  lacks V-extension CSRs; the firmware does not use RVV).
- Linker: RAM origin 0x20000000+1 K (SDK reservation), 135 K — valid under
  both flash/RAM option-byte configs (RM Table 32-4).
- `main.c` prints a **PSRAM probe** result at boot, banner first.

Build: `docker run --rm --platform linux/amd64 -v $PWD:/host terriblefire78/mrs make -C /host/firmware`

### 8.1 SD card interface

Default-mapped **SPI1 (PA5/PA6/PA7)** is both the fastest option and the only one
available:

- SPI2 is on PB12–PB15, SPI3 on PA15/PB3–PB5 (remap PC10–PC12), and SPI1's own
  remap is PB3/PB4/PB5 — every one of those pins is taken by the Amiga bus.
- SPI1 sits on APB2. On this part **both APB buses max out at FHCLK** (Table 3-2:
  `FPCLK1`/`FPCLK2` max = `FHCLK`), unlike the V307 where APB1 was capped at
  HCLK/2. With PCLK2 = 200 MHz, SPI1 ÷4 gives **50 MHz** — exactly the SD
  high-speed ceiling, up from 36 MHz today.

**SDIO is not possible.** `SDIO_CMD` is fixed to **PD2** in all three mappings
(SDIO_RM=0, SDIOEN&ETHMACEN, SDIO_RM=1) — that is data bus D2 — and `SDIO_CK` is
fixed to PC12. There is no escape remap.

**The SPI clock is not the bottleneck.** `driver/spi.c:210` transfers a sector as
512 individual `SpiByte()` calls, each one a PCMCIA I/O cycle plus ISR entry on the
Amiga side. 36 → 50 MHz saves ~60 ns on a byte that costs the better part of a
microsecond. The real opportunity the PSRAM opens up is a **block-transfer path**:
the MCU reads a whole sector into PSRAM itself and the Amiga reads it back as
memory, instead of 512 register round-trips. Worth doing as a follow-up once the
port is functional — it does not need to block the hardware decision.

## 9. To verify before committing to a layout

- [x] Schematic rewired to the §7 map and board contactrefs synced — verified by
      `eagle/check_pinmap.py` (81/81) and a full net↔signal annotation cross-check.
- [x] VDDK, VDD18 and VDD decoupling placed (§6.5).
- [ ] Spot-check pins 38–55 and the FT column against the PDF pages directly — this
      plan's pin numbers were extracted from the PDF text layer.
- [ ] PSRAM lot code (§6.3): prefer fifth-last digit ≠ 0 (byte writes,
      variable-latency reads, >200 MHz). Optional — the firmware is lot-safe as
      built (RMW byte writes, fixed read latency).
- [x] Current draw vs the PCMCIA slot budget (1.0 A @ 5 V): CH32V467 worst case
      61 mA (DS Table 3-6 + V467 note: 39.1 mA all-peripherals @200 MHz + 22 mA
      PSRAM), ≈ current-neutral vs the V307+APS6404L it replaces. Whole-card
      realistic worst ≈ 300 mA (SD write burst + LEDs); host-commanded all-white
      LED ceiling ≈ 700 mA — all inside budget, and all dominated by loads that
      existed on the proven previous revision.
- [ ] Confirm the CH32V4xx peripheral library / toolchain support in the existing
      Docker build.
- [ ] Re-route the board (~40 signals were invalidated by the pin permutation).

## 10. Status

| Area | State |
|---|---|
| Eagle library part `CH32V467VET6` | done — reuses `QFP50P1600X1600X160-100N` |
| Schematic pin map | done — 81/81 against §7 |
| Board contactrefs | done — 95 nets ↔ 95 signals, no mismatches |
| SPI RAM (IC3) removed | done |
| Audio stage (IC4) removed | done — see §6.4 |
| USB breakout (JP1) removed | done — SWD + UART are the only programming path |
| VDDK / VDD18 / VDD decoupling | done |
| Board routing | done — verified all 81 IC1 pads have copper |
| Firmware port (§8) | done — official V4x7 SDK, 200 MHz core+PSRAM, PSRAM init implemented (§8.0) |
| 8th APA102 (LED10) added | done — `PCMCIA_NUM_LEDS 8`, I/O window now `$A20220–$A2023F` (README table still to update) |

`eagle/check_pinmap.py` re-runs the pin-map check against the live schematic at any
time; it exits non-zero on any deviation.

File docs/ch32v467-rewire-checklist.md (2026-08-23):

# CH32V467VET6 rewiring checklist

Generated from `eagle/tfpcmcia.net` against the target map in
`ch32v467-migration-plan.md` §7.

> **The part swap kept every net on its original pad.** Because the CH32V467VET6
> has a different pinout in the 38–55 and 73/74 ranges, the existing wiring is now
> attached to the wrong functions — including supply pins driven by bus signals.
> Nothing here should be routed or fabricated until this list is worked through.

## Summary

- 43 pins already correct
- **41 pins need rewiring**
- 7 pins currently wired that must be disconnected

## Pins to disconnect

| Pad | Pin | Currently | Action |
|-----|-----|---|---|
| 24 | `PA1` | `RAM_SNSS` | NC (spare) |
| 25 | `PA2` | `READY` | NC (spare) |
| 37 | `PB2-BOOT1` | `A18` | NC (spare (only free 5V-tolerant pin)) |
| 42 | `MDIRN` | `A11` | NC (Ethernet unused) |
| 43 | `MDIRP` | `A12` | NC (Ethernet unused) |
| 44 | `MDITN` | `A13` | NC (Ethernet unused) |
| 45 | `MDITP` | `A14` | NC (Ethernet unused) |

## Pins to rewire

| Pad | Pin | Currently | Target net |
|-----|-----|---|---|
| 27 | `VSS_2` | *(unconnected)* | **`GND`** |
| 28 | `VDD_2` | *(unconnected)* | **`VCC33`** |
| 30 | `PA5` | `RAM_CLK` | **`SD_CLK`** |
| 31 | `PA6` | `RAM_MISO` | **`SD_MISO`** |
| 32 | `PA7` | `RAM_MOSI` | **`SD_MOSI`** |
| 33 | `PC4` | *(unconnected)* | **`SD_SNSS`** |
| 34 | `PC5` | *(unconnected)* | **`SD_CD`** |
| 35 | `PB0` | `A16` | **`LED1`** |
| 36 | `PB1` | `A17` | **`LED2`** |
| 38 | `PE8` | `A7` | **`A8`** |
| 39 | `PE9` | `A8` | **`A9`** |
| 40 | `VDDK` | `A9` | **`VDDK`** |
| 41 | `VSS_3` | `A10` | **`GND`** |
| 46 | `VDD_MAIN` | `A15` | **`VCC33`** |
| 47 | `VSS_4` | `!REG` | **`GND`** |
| 48 | `VDD18` | `IORD` | **`VDD18`** |
| 49 | `PB10` | `GND` | **`A14`** |
| 50 | `PB11` | `VCC33` | **`A15`** |
| 51 | `PD8` | `IOWR` | **`D8`** |
| 52 | `PB12` | `RESET` | **`A16`** |
| 53 | `PB13` | `!WAIT` | **`A17`** |
| 54 | `PB14` | `WP/!IOCS16` | **`A18`** |
| 55 | `PB15` | `D8` | **`A19`** |
| 63 | `PC6` | *(unconnected)* | **`CE1`** |
| 64 | `PC7` | `LED2` | **`OE`** |
| 65 | `PC8` | `LED1` | **`!WE`** |
| 66 | `PC9` | `SD_SNSS` | **`CE2`** |
| 67 | `PA8` | *(unconnected)* | **`!WAIT`** |
| 68 | `PA9` | `USART_TX` | **`READY`** |
| 69 | `PA10` | `USART_RX` | **`WP/!IOCS16`** |
| 73 | `PE10` | *(unconnected)* | **`A10`** |
| 74 | `PE11` | `GND` | **`A11`** |
| 77 | `PA15` | `SD_CD` | **`RESET`** |
| 78 | `PC10` | `SD_CLK` | **`!REG`** |
| 79 | `PC11` | `SD_MISO` | **`IORD`** |
| 80 | `PC12` | `SD_MOSI` | **`IOWR`** |
| 89 | `PB3` | `A19` | **`A7`** |
| 92 | `PB6` | `CE1` | **`USART_TX`** |
| 93 | `PB7` | `OE` | **`USART_RX`** |
| 95 | `PB8` | `!WE` | **`A12`** |
| 96 | `PB9` | `CE2` | **`A13`** |

## Already correct

| Pad | Pin | Net |
|-----|-----|-----|
| 1 | `PE2` | `A2` |
| 2 | `PE3` | `A3` |
| 3 | `PE4` | `A4` |
| 4 | `PE5` | `A5` |
| 5 | `PE6` | `A6` |
| 6 | `VBAT` | `VCC33` |
| 10 | `VSS_1` | `GND` |
| 11 | `VDD_1` | `VCC33` |
| 14 | `NRST` | `NRST` |
| 15 | `PC0` | `LED_CLK` |
| 16 | `PC1` | `LED_DO` |
| 19 | `VSSA` | `GND` |
| 20 | `VREF-` | `GND` |
| 21 | `VREF+` | `VCC33` |
| 22 | `VDDA` | `VCC33` |
| 29 | `PA4` | `AUD_MIXED` |
| 56 | `PD9` | `D9` |
| 57 | `PD10` | `D10` |
| 58 | `PD11` | `D11` |
| 59 | `PD12` | `D12` |
| 60 | `PD13` | `D13` |
| 61 | `PD14` | `D14` |
| 62 | `PD15` | `D15` |
| 70 | `PA11` | `USB1_DM` |
| 71 | `PA12` | `USB1_DP` |
| 72 | `PA13` | `SWDIO` |
| 75 | `VDD_3` | `VCC33` |
| 76 | `PA14` | `SWCLK` |
| 81 | `PD0` | `D0` |
| 82 | `PD1` | `D1` |
| 83 | `PD2` | `D2` |
| 84 | `PD3` | `D3` |
| 85 | `PD4` | `D4` |
| 86 | `PD5` | `D5` |
| 87 | `PD6` | `D6` |
| 88 | `PD7` | `D7` |
| 90 | `PB4` | `A20` |
| 91 | `PB5` | `A21` |
| 94 | `PE12-BOOT0` | `BOOT0` |
| 97 | `PE0` | `A0` |
| 98 | `PE1` | `A1` |
| 99 | `VSS_5` | `GND` |
| 100 | `VDD_4` | `VCC33` |

## Also required (not visible in the netlist diff)

1. **Delete the APS6404L SPI RAM** (`SPI_FLASH-X25XX`) and its decoupling. The
   `RAM_SNSS` / `RAM_CLK` / `RAM_MISO` / `RAM_MOSI` nets disappear with it — the SD
   card takes over SPI1 on PA5/PA6/PA7.
2. **New `VDD18` rail** (pad 48): 0.1 uF || 2.2 uF to GND. Internally generated, do
   not drive it externally.
3. **`VDDK` becomes its own net** (pad 40): 0.1 uF || 2.2 uF to GND. It was PE9/A9
   before, so this decoupling does not exist on the board yet.
4. **Main VDD bulk** on pad 46 (`VDD_MAIN`) must be 0.1 uF || >=10 uF, and the total
   VDD capacitance must exceed VDDK + VDD18 combined.
5. **Pads 27/28 (`VSS_2`/`VDD_2`) are unconnected** — this is pre-existing, carried
   over from the STM32 footprint. All same-name power pins must be tied together.
6. **BVD2 audio on PA4 is not 5V tolerant** — AC-couple it into the mixer.
7. **Check no 5V bus signal lands on a non-FT pin**: PA0-PA7, PA11, PA12, PB0, PB1,
   PB6, PB7, PC0-PC5, PC13-PC15.

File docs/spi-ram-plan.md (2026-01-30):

# APS6404L-3SQR SPI RAM Implementation Plan

## Device Overview

**Part Number:** APS6404L-3SQR-SN (SOP-8 package)
- **Capacity:** 64Mbit (8MB)
- **Interface:** SPI/QPI (using standard SPI mode only)
- **Supply Voltage:** 2.7V to 3.6V (using 3.3V)
- **Organization:** 8M x 8 bits, byte-addressable

## Performance Specifications

### Clock Frequencies (at VDD=3.3V)
- **Linear Burst Mode:** 84MHz maximum ✓ (our target mode)
- **Wrap-32 Mode:** 109MHz maximum (not needed)
- **SPI Read (0x03):** 33MHz maximum (slow mode)

### Operating Modes
- Device powers up in **SPI mode** by default (perfect for CH32V307)
- QPI mode available but not needed for our application
- Default burst mode: **Linear Burst** (crosses page boundaries up to 84MHz)

## Hardware Design Review

### Pin Configuration (SOP-8 Package)
| Pin | Signal | Function | Connection |
|-----|---|---|---|
| 1 | /CE | Chip Select (active low) | CH32 GPIO (RAM_SNSS) |
| 2 | SO/SIO[1] | Serial Output / MISO | CH32 SPI MISO (RAM_MISO) |
| 3 | SIO[2] | Write Protect (unused in SPI) | Tie to VDD via 10k |
| 4 | VSS | Ground | GND |
| 5 | SI/SIO[0] | Serial Input / MOSI | CH32 SPI MOSI (RAM_MOSI) |
| 6 | SCLK | Serial Clock | CH32 SPI CLK (RAM_CLK) |
| 7 | SIO[3] | Hold (unused in SPI) | Tie to VDD via 10k |
| 8 | VDD | Power Supply | 3.3V |

### Critical Hardware Requirements

#### 1. Decoupling Capacitors (Section 14.3)
**REQUIRED:**
- **1µF ceramic capacitor** (low ESR) on VDD pin
- Place as close as possible to pin 8 (VDD)
- **Optional:** 0.1µF capacitor for better high-frequency response

**Schematic Status:** ✓ Confirmed - 2x 1µF capacitors present

#### 2. Unused Pin Handling
**SIO[2] (Pin 3) - Write Protect:**
- Must be tied HIGH (VDD) to disable write protection in SPI mode
- Add 10kΩ pull-up resistor to VCC33

**SIO[3] (Pin 7) - Hold:**
- Must be tied HIGH (VDD) to disable hold function in SPI mode
- Add 10kΩ pull-up resistor to VCC33

**Schematic Status:** ✓ Pull-ups present on pins 3 and 7 (confirmed)

#### 3. PCB Layout Guidelines
- Keep decoupling caps within 5mm of VDD pin
- Minimize trace lengths on SPI signals
- Match trace lengths if possible (not critical at 84MHz)
- Solid ground plane under device
- Maximum load capacitance: 15pF per signal

## Firmware Implementation

### 1. Power-Up Initialization Sequence (Section 7)

```c
// After VDD reaches stable 3.3V:
// 1. Wait 150µs minimum
delay_us(150);

// 2. Ensure CLK is LOW, CE# is HIGH before starting
// 3. Issue Software Reset sequence

// Send Reset Enable command (0x66)
spi_ram_cs_low();
spi_transfer(0x66);
spi_ram_cs_high();

// Send Reset command (0x99)
spi_ram_cs_low();
spi_transfer(0x99);
spi_ram_cs_high();

// 4. Wait tRST (50ns minimum)
// 5. Device is now in SPI standby mode and ready
```

### 2. Command Termination (Section 8.6)

**CRITICAL REQUIREMENT:**
- All read/write operations MUST be terminated by raising CE# high
- Failure to do so blocks internal refresh operations → **memory corruption**
- CE# must be raised immediately after the last data byte

**Implementation:**
```c
// For writes:
spi_ram_cs_low();
spi_transfer(cmd);
spi_transfer(addr[0]);
spi_transfer(addr[1]);
spi_transfer(addr[2]);
spi_transfer(data);
spi_ram_cs_high();  // MUST raise CE# here!

// For reads:
spi_ram_cs_low();
spi_transfer(cmd);
spi_transfer(addr[0]);
spi_transfer(addr[1]);
spi_transfer(addr[2]);
// ... wait cycles if needed
data = spi_transfer(0xFF);
spi_ram_cs_high();  // MUST raise CE# here!
```

### 3. Timing Constraints (Section 14.6)

| Parameter | Min | Max | Notes |
|---|-----|-----|---|
| Clock Period (tCLK) | 11.9ns | - | = 84MHz |
| CE# Setup (tCSP) | 2.5ns | - | Before CLK rising |
| CE# Hold (tCHD) | 3.0ns | - | After CLK rising |
| Data Setup (tSP) | 2ns | - | Before active CLK edge |
| Data Hold (tHD) | 2ns | - | After active CLK edge |
| CE# High Between Ops (tCPH) | 18ns | - | Between bursts |
| CE# Low Max (tCEM) | - | 8µs | Standard temp (-40 to 85°C) |
| CE# Low Max (tCEM) | - | 4µs | Extended temp (-40 to 105°C) |

**Key Implications:**
- Must raise CE# high for minimum 18ns between operations
- Cannot keep CE# low for more than 8µs (blocks refresh)
- For long transfers, break into smaller chunks with CE# toggling

### 4. SPI Commands

#### Fast Read (0x0B) - Recommended
- Clock up to 84MHz (linear burst)
- Requires 8 dummy cycles (wait cycles)
- Command format: `[0x0B][A23:A16][A15:A8][A7:A0][8 dummy cycles][Data...]`

```c
void spi_ram_read(uint32_t address, uint8_t *buffer, uint16_t length) {
    spi_ram_cs_low();

    spi_transfer(0x0B);  // Fast Read command
    spi_transfer((address >> 16) & 0xFF);  // A23:A16
    spi_transfer((address >> 8) & 0xFF);   // A15:A8
    spi_transfer(address & 0xFF);          // A7:A0

    // 8 dummy clock cycles
    spi_transfer(0xFF);

    // Read data
    for (uint16_t i = 0; i < length; i++) {
        buffer[i] = spi_transfer(0xFF);
    }

    spi_ram_cs_high();
}
```

#### Write (0x02)
- Clock up to 84MHz (linear burst)
- No wait cycles required
- Command format: `[0x02][A23:A16][A15:A8][A7:A0][Data...]`

```c
void spi_ram_write(uint32_t address, const uint8_t *buffer, uint16_t length) {
    spi_ram_cs_low();

    spi_transfer(0x02);  // Write command
    spi_transfer((address >> 16) & 0xFF);  // A23:A16
    spi_transfer((address >> 8) & 0xFF);   // A15:A8
    spi_transfer(address & 0xFF);          // A7:A0

    // Write data
    for (uint16_t i = 0; i < length; i++) {
        spi_transfer(buffer[i]);
    }

    spi_ram_cs_high();
}
```

#### Slow Read (0x03) - For Debugging
- Clock up to 33MHz only
- No wait cycles
- Useful for initial testing at lower speeds

### 5. Address Space (Section 8.1)
- Byte-addressable: A[22:0] (23 address bits)
- Page size: 1024 bytes (1KB)
- Linear burst can cross page boundaries at 84MHz max
- Can cross page boundary one time only per burst

### 6. Best Practices

**DO:**
- Always terminate operations with CE# high
- Wait minimum 18ns between operations
- Break long transfers into chunks (< 8µs CE# low time)
- Initialize with proper reset sequence on power-up
- Use Fast Read (0x0B) for best performance

**DON'T:**
- Don't keep CE# low for more than 8µs continuous
- Don't forget dummy cycles on Fast Read (0x0B)
- Don't exceed 84MHz in linear burst mode at 3.3V
- Don't skip the power-up initialization sequence

## Current Consumption

| Mode | Typical | Maximum | Notes |
|---|---|---|---|
| Active (Read/Write) | 5.5mA @ 133MHz | 7mA | At 84MHz will be lower |
| Standby | 100µA @ 25°C | 250µA @ 85°C | CLK in DC low state |

## Testing Plan

### Phase 1: Basic Connectivity
1. Verify SPI communication at low speed (1MHz)
2. Read Device ID (command 0x9F) if available
3. Simple write/read test at single address

### Phase 2: Speed Testing
1. Test at 10MHz
2. Test at 42MHz (half speed)
3. Test at 84MHz (full speed)
4. Verify data integrity at each speed

### Phase 3: Functional Testing
1. Sequential read/write operations
2. Random access patterns
3. Page boundary crossing
4. Long burst operations (with CE# management)
5. Temperature testing if needed

## Schematic Review Checklist

- [x] 1µF decoupling capacitor on VDD pin (as close as possible) ✓
- [x] Additional 1µF capacitor added for better stability ✓
- [x] Pull-up resistor on SIO[2] (pin 3) to VCC33 ✓
- [x] Pull-up resistor on SIO[3] (pin 7) to VCC33 ✓
- [x] SPI signals routed to CH32V307 ✓
- [x] RAM_SNSS (CS) connected to GPIO ✓
- [x] RAM_CLK connected to SPI CLK ✓
- [x] RAM_MOSI connected to SPI MOSI ✓
- [x] RAM_MISO connected to SPI MISO ✓
- [x] Ground and power properly connected ✓

## References

- APS6404L-3SQR Datasheet Rev. 2.3 (April 30, 2020)
- Located: `/Users/stephen/git/tfpcmcia/docs/APS6404L_3SQR.pdf`
- Key sections: 7 (Power-Up), 8 (Interface), 10 (SPI Operations), 14 (Electrical)

## Notes from Schematic Review

- Note in schematic states: "Unfortunately the CH32 chips don't do QUAD SPI"
  - ✓ Confirmed: Device works perfectly in standard SPI mode (default mode)
  - ✓ No QSPI required for full functionality

- Note states: "Using the footprint from a standard SPI ROM but this will work for the APS6404L"
  - ✓ Verified: Pin assignments match standard SPI ROM footprints
  - ✓ Confirmed: Pull-ups present on unused pins (SIO[2], SIO[3])
  - ✓ Confirmed: Additional 1µF decoupling capacitor added

## Status

**Hardware:** ✓ Design verified compatible with CH32V307
- All decoupling capacitors present (2x 1µF)
- Pull-ups on unused SPI pins confirmed
- All SPI signals properly routed

**Firmware:** Implementation plan complete, ready for coding
**Testing:** Ready for PCB fabrication and firmware implementation

---
Document created: 2026-01-29
Last updated: 2026-01-29

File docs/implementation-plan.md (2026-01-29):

# Amiga PCMCIA Card Firmware Implementation Plan

## Overview

Adapt the CH32V30x MSX cartridge firmware to create an Amiga PCMCIA card with:
- **22-bit address bus** (A0-A21) = 4MB address space
- **16-bit data bus** (D0-D15)
- **256KB ROM** at base address (loaded from SD card)
- **Attribute memory** for PCMCIA card information structure
- **I/O ports** for SD card control
- **Optional SPI RAM** for extended storage
- **Standard PCMCIA timing** (120ns cycles)

**Approach:** GPIO interrupt-driven (proven MSX architecture), NOT FSMC (due to address line limitations and missing driver implementation).

---

## 1. Complete Pin Assignment Summary

### Quick Reference Table

| Pin | Signal | Direction | Function | Notes |
|-----|---|---|---|---|
| **GPIOA (Debug/Audio)** |
| PA0 | STATUS_LED | Output | Status indicator LED | Optional |
| PA1 | SPIRAM_CS | Output | SPI RAM chip select | Manual GPIO control |
| PA2 | **READY** | **Output** | **Card ready signal** | **Push-pull, active HIGH when ready** |
| PA3 | - | - | Available | 1 pin free |
| PA4 | DAC_OUT1 / BVD2 | Output | Audio output to Amiga | Analog, connects to PCMCIA BVD2 |
| PA5 | SPI1_SCK | Output | SPI RAM clock | Alternate function, 72 MHz max |
| PA6 | SPI1_MISO | Input | SPI RAM data in | Alternate function |
| PA7 | SPI1_MOSI | Output | SPI RAM data out | Alternate function |
| PA8 | BOOTLOADER | Input | Programming mode detect | Pull-down |
| PA9 | - | - | Available | 1 pin free |
| PA10 | USART1_RX | Input | Debug UART receive | **RESERVED** |
| PA11 | USART1_TX | Output | Debug UART transmit | **RESERVED** |
| PA12 | - | - | Available | 1 pin free |
| PA13 | SWDIO | I/O | SWD debug data | **RESERVED** |
| PA14 | SWCLK | Input | SWD debug clock | **RESERVED** |
| PA15 | SD_CD | Input | SD card detect | Pull-up, LOW when card inserted |
| **GPIOB (Address + Control)** |
| PB0 | A16 | Input | Address bit 16 | Floating |
| PB1 | A17 | Input | Address bit 17 | Floating |
| PB2 | A18 | Input | Address bit 18 | Floating |
| PB3 | A19 | Input | Address bit 19 | Floating |
| PB4 | A20 | Input | Address bit 20 | Floating |
| PB5 | A21 | Input | Address bit 21 | Floating |
| PB6 | CE1 / UDS | Input | Upper Data Strobe | **EXTI6 interrupt**, pull-up |
| PB7 | OE | Input | Output Enable (read) | Pull-up |
| PB8 | WE | Input | Write Enable | Pull-up |
| PB9 | CE2 / LDS | Input | Lower Data Strobe | **EXTI9 interrupt**, pull-up |
| PB10 | REG | Input | Attribute space select | Pull-up |
| PB11 | IOR | Input | I/O Read strobe | Pull-up, active LOW |
| PB12 | IOW | Input | I/O Write strobe | Pull-up, active LOW |
| PB13 | RESET | Input | Card reset | Pull-up |
| PB14 | WAIT | Output | Wait state control | Push-pull, active LOW inserts wait states |
| PB15 | IOIS16 | Output | 16-bit I/O indicator | Push-pull, or spare |
| **GPIOC (SPI + Expansion)** |
| PC0-PC8 | - | - | Available | 9 pins free |
| PC9 | SD_CS | Output | SD card chip select | Push-pull, active LOW |
| PC10 | SPI3_SCK | Output | SD card SPI clock | Alternate function |
| PC11 | SPI3_MISO | Input | SD card SPI data in | Floating |
| PC12 | SPI3_MOSI | Output | SD card SPI data out | Alternate function |
| PC13-PC15 | - | - | Available | 3 pins free |
| **GPIOD (Data Bus)** |
| PD0 | D0 | I/O | Data bit 0 | Bidirectional |
| PD1 | D1 | I/O | Data bit 1 | Bidirectional |
| PD2 | D2 | I/O | Data bit 2 | Bidirectional |
| PD3 | D3 | I/O | Data bit 3 | Bidirectional |
| PD4 | D4 | I/O | Data bit 4 | Bidirectional |
| PD5 | D5 | I/O | Data bit 5 | Bidirectional |
| PD6 | D6 | I/O | Data bit 6 | Bidirectional |
| PD7 | D7 | I/O | Data bit 7 | Bidirectional |
| PD8 | D8 | I/O | Data bit 8 | Bidirectional |
| PD9 | D9 | I/O | Data bit 9 | Bidirectional |
| PD10 | D10 | I/O | Data bit 10 | Bidirectional |
| PD11 | D11 | I/O | Data bit 11 | Bidirectional |
| PD12 | D12 | I/O | Data bit 12 | Bidirectional |
| PD13 | D13 | I/O | Data bit 13 | Bidirectional |
| PD14 | D14 | I/O | Data bit 14 | Bidirectional |
| PD15 | D15 | I/O | Data bit 15 | Bidirectional |
| **GPIOE (Address Bus)** |
| PE0 | A0 | Input | Address bit 0 | Floating |
| PE1 | A1 | Input | Address bit 1 | Floating |
| PE2 | A2 | Input | Address bit 2 | Floating |
| PE3 | A3 | Input | Address bit 3 | Floating |
| PE4 | A4 | Input | Address bit 4 | Floating |
| PE5 | A5 | Input | Address bit 5 | Floating |
| PE6 | A6 | Input | Address bit 6 | Floating |
| PE7 | A7 | Input | Address bit 7 | Floating |
| PE8 | A8 | Input | Address bit 8 | Floating |
| PE9 | A9 | Input | Address bit 9 | Floating |
| PE10 | A10 | Input | Address bit 10 | Floating |
| PE11 | A11 | Input | Address bit 11 | Floating |
| PE12 | A12 | Input | Address bit 12 | Floating |
| PE13 | A13 | Input | Address bit 13 | Floating |
| PE14 | A14 | Input | Address bit 14 | Floating |
| PE15 | A15 | Input | Address bit 15 | Floating |

### Pin Usage Statistics

| Port | Total | Used | Function Groups | Available |
|---|---|---|---|---|
| GPIOA | 16 | 12 | SPI1(4), DAC(1), UART(2), SWD(2), Boot(1), SD_CD(1), READY(1) | 4 pins |
| GPIOB | 16 | 16 | Address A16-A21(6), Control(10) | 0 pins |
| GPIOC | 16 | 4 | SPI3(4) | 12 pins |
| GPIOD | 16 | 16 | Data D0-D15(16) | 0 pins |
| GPIOE | 16 | 16 | Address A0-A15(16) | 0 pins |
| **Total** | **80** | **64** | | **16** |

**Utilization:** 80% (64/80 pins used)

---

## 2. Detailed Pin Allocation by Function

### Data Bus (16 bits) - GPIOD
**All on single port for atomic 16-bit operations:**
- **GPIOD[0-15]**: D0-D15 (full 16-bit data bus)
  - **Advantage:** Single port = atomic read/write via `GPIOD->INDR` / `GPIOD->OUTDR`
  - **Mode switching:** Both `CFGLR` (D0-D7) and `CFGHR` (D8-D15) for direction control

### Address Bus (22 bits) - GPIOE + GPIOB
**Lower 16 bits on GPIOE, upper 6 bits on GPIOB:**
- **GPIOE[0-15]**: A0-A15 (lower address bits)
- **GPIOB[0-5]**: A16-A21 (upper address bits)
  - **Total:** 22 address lines = 4MB address space (0x000000 - 0x3FFFFF)
  - **Reading:** `addr = GPIOE->INDR | ((GPIOB->INDR & 0x3F) << 16)`

### PCMCIA Control Signals - GPIOB[6-15]
**All control signals grouped on upper GPIOB:**
- **PB6**: CE1/UDS (Upper Data Strobe) - **interrupt trigger** (EXTI6), active low
- **PB7**: OE (Output Enable) - memory read cycle, active low
- **PB8**: WE (Write Enable) - memory write cycle, active low
- **PB9**: CE2/LDS (Lower Data Strobe) - **interrupt trigger** (EXTI9), active low
- **PB10**: REG (Register Select) - 0=Common memory, 1=Attribute memory
- **PB11**: IOR (I/O Read) - I/O read cycle, active low
- **PB12**: IOW (I/O Write) - I/O write cycle, active low
- **PB13**: RESET (Reset) - input, active low
- **PB14**: WAIT - **output**, low=insert wait states, high=no wait
- **PB15**: IOIS16 (16-bit I/O indicator) - **output**, or spare

**Memory vs I/O Access:**
- **Memory access**: OE (read) or WE (write) active
- **I/O access**: IOR (read) or IOW (write) active
- These are mutually exclusive - Gayle asserts either memory OR I/O strobes, not both

**Byte/Word Access (via CE1/CE2):**
- 16-bit access: Both UDS (CE1) and LDS (CE2) asserted
- Upper byte only: UDS asserted, LDS inactive
- Lower byte only: LDS asserted, UDS inactive

### SD Card Interface - SPI3 on GPIOC
**Using hardware SPI3 peripheral (APB1 bus):**
- **PC9**: SD_CS (Chip Select, manual GPIO control)
- **PC10**: SPI3_SCK (SPI Clock)
- **PC11**: SPI3_MISO (Master In Slave Out)
- **PC12**: SPI3_MOSI (Master Out Slave In)
  - **SPI Speed:** 36 MHz max (APB1 @ 72MHz / 2 prescaler)
  - **SPI Mode:** Mode 0 (CPOL=0, CPHA=0)
  - **Throughput:** ~4.5 MB/s theoretical (sufficient for SD cards)

### SPI RAM Interface - SPI1 on GPIOA
**Using hardware SPI1 peripheral (APB2 bus) for maximum speed:**
- **PA1**: SPIRAM_CS (Chip Select, manual GPIO control)
- **PA5**: SPI1_SCK (SPI Clock)
- **PA6**: SPI1_MISO (Master In Slave Out)
- **PA7**: SPI1_MOSI (Master Out Slave In)
  - **SPI Speed:** 72 MHz max (APB2 @ 144MHz / 2 prescaler)
  - **SPI Mode:** Mode 0 (CPOL=0, CPHA=0)
  - **Throughput:** ~9 MB/s theoretical (2x faster than SPI3)

**IMPORTANT:** CH32V30x does NOT support QSPI (Quad SPI):
- Only standard SPI available (1-bit MOSI + 1-bit MISO)
- SPI RAM must be standard SPI, not QSPI
- QSPI flash chips can be used in SPI compatibility mode only
- Max speed: ~36-72 MHz in standard SPI mode

### Audio Output & SPI RAM - GPIOA
- **PA1**: SPIRAM_CS (SPI RAM chip select) - manual GPIO control
- **PA4**: DAC_OUT1 (analog audio output, connects to BVD2 pin on PCMCIA connector)
  - **Purpose:** Send analog audio to Amiga via Battery Voltage Detect pin
  - **DAC:** 12-bit, driven by TIM4/DMA for audio samples
- **PA5-PA7**: SPI1 interface (SCK, MISO, MOSI) for SPI RAM @ 72 MHz max

### Debug/Programming/Status - GPIOA
- **PA10**: USART1_RX (debug UART receive) - **RESERVED**
- **PA11**: USART1_TX (debug UART transmit) - **RESERVED**
- **PA13**: SWDIO (SWD debug data) - **RESERVED**
- **PA14**: SWCLK (SWD debug clock) - **RESERVED**
- **PA0**: Status LED (optional, active high)
- **PA2**: READY output (push-pull, active HIGH when card ready)
- **PA8**: Programming/bootloader mode detect (input with pull-down)
- **PA15**: SD card detect (input with pull-up, LOW when card inserted)

### Reserved/Available Pins
- **GPIOA[3, 9, 12]**: 3 pins available
- **GPIOC[0-8, 13-15]**: 12 pins available
- Total available: ~15 pins for future expansion

### Pin Usage Summary
| Port | Used | Function | Available |
|---|---|---|---|
| GPIOA | 13 | SPI1 (4), DAC (1), UART(2), SWD(2), Boot(1), LED(1), SD_CD(1), READY(1) | 3 pins |
| GPIOB | 16 | Address A16-A21 (6), Control (10: UDS, OE, WE, LDS, REG, IOR, IOW, RESET, WAIT, IOIS16) | 0 pins |
| GPIOC | 4 | SPI3 (4) | 12 pins |
| GPIOD | 16 | Data D0-D15 (16) | 0 pins |
| GPIOE | 16 | Address A0-A15 (16) | 0 pins |
| **Total** | **65** | | **15** |

**Total Pins Used:** 65 pins (81% utilization of 80 GPIO pins on CH32V303VCT6)

---

## 2. Memory Architecture

### Address Space Map

**From Card's Perspective (A0-A21):**
```
0x000000 - 0x03FFFF: ROM (256KB from SD card buffer in Flash)
0x040000 - 0x1FFFFF: SPI RAM (1.75MB, optional)
0x1F0000 - 0x1F00FF: I/O Ports (SD card control registers)
0x200000 - 0x3FFFFF: Unmapped (returns 0xFFFF)
Attribute Memory: Separate space selected via REG signal (512 bytes)
```

**From Amiga's Perspective (how Amiga accesses the card):**
```
$600000 - $63FFFF: ROM (card address 0x000000 - 0x03FFFF)
$640000 - $7FFFFF: SPI RAM (card address 0x040000 - 0x1FFFFF)
$9F0000 - $9F00FF: I/O Ports (card address 0x1F0000 - 0x1F00FF)
$A00000 - $A001FF: Attribute Memory (REG=1, 512 bytes)
```

**Note:** The card hardware only sees addresses A0-A21 starting from 0x000000. The Amiga's Gayle chip maps these to the $600000-$9FFFFF range. The card doesn't need to know about this offset.

### ROM Buffer Strategy
**Use Flash-based ROM buffer** (not RAM):
- Program ROM into Flash at `__cart_section_start` (0x08008000)
- Load from SD card during initialization or programming mode
- 256KB Flash available for cartridge section
- Fast access (0 wait states at 144MHz)
- Preserves 32KB SRAM for stack/heap/variables

### Attribute Memory
- 512-byte static array containing PCMCIA CIS (Card Information Structure)
- Includes card identification, voltage, timing specifications
- Standard PCMCIA tuples for memory card type

---

## 3. Interrupt Handler Architecture

### Trigger: CE1/UDS or CE2/LDS Falling Edge
- Configure **EXTI6** on GPIOB[6] (CE1/UDS - Upper Data Strobe)
- Configure **EXTI9** on GPIOB[9] (CE2/LDS - Lower Data Strobe)
- **Both interrupts trigger the same handler** for byte-level or word-level access
- Falling edge = card selected by Amiga (byte or word access)
- Highest priority (0) for minimal latency
- Use `WCH-Interrupt-fast` attribute

**Why dual interrupts?**
- 16-bit word access: Both UDS and LDS assert (either can trigger handler)
- Upper byte access: Only UDS asserts
- Lower byte access: Only LDS asserts
- Handler must check which strobe(s) are active to determine access width

### Pin Bit Masks (for quick reference)
```c
#define UDS_MASK    0x0040  // PB6  - bit 6 (CE1/UDS - Upper Data Strobe)
#define OE_MASK     0x0080  // PB7  - bit 7 (Memory Read)
#define WE_MASK     0x0100  // PB8  - bit 8 (Memory Write)
#define LDS_MASK    0x0200  // PB9  - bit 9 (CE2/LDS - Lower Data Strobe)
#define REG_MASK    0x0400  // PB10 - bit 10 (Attribute Memory Select)
#define IOR_MASK    0x0800  // PB11 - bit 11 (I/O Read)
#define IOW_MASK    0x1000  // PB12 - bit 12 (I/O Write)
#define RESET_MASK  0x2000  // PB13 - bit 13
#define WAIT_MASK   0x4000  // PB14 - bit 14
#define IOIS16_MASK 0x8000  // PB15 - bit 15
#define ADDR_HI_MASK 0x003F // PB[0-5] - bits 0-5 (A16-A21)
```

### Handler Flow (Optimized)
```c
void PCMCIA_Handler(void) __attribute__((interrupt("WCH-Interrupt-fast")));

void PCMCIA_Handler(void) {
    // Clear both interrupt flags immediately
    EXTI->INTFR = EXTI_Line6 | EXTI_Line9;

    // Read 22-bit address (early)
    uint32_t addr_low = GPIOE->INDR;              // A0-A15
    uint32_t addr_high = GPIOB->INDR & 0x3F;      // A16-A21 (bits 0-5)
    uint32_t address = addr_low | (addr_high << 16);

    // Read control signals and potential write data
    uint16_t control = GPIOB->INDR;
    uint8_t reg = (control >> 10) & 0x01;         // REG signal (PB10)
    uint16_t write_data = GPIOD->INDR;

    // Wait while either UDS or LDS asserted
    while (((GPIOB->INDR & 0x0040) == 0) || ((GPIOB->INDR & 0x0200) == 0)) {
        control = GPIOB->INDR;  // Re-read control signals

        // MEMORY READ CYCLE: OE asserted (PB7 = bit 7 = 0x0080)
        if ((control & 0x0080) == 0) {
            uint16_t data;

            if (reg) {
                // Attribute memory access
                data = attribute_memory[address & 0x1FF];
            } else if (address < 0x40000) {
                // ROM region (Flash-based)
                data = rom_buffer[address >> 1];
            } else {
                // Unmapped or SPI RAM
                data = 0xFFFF;
            }

            // Drive data bus
            GPIOD->OUTDR = data;
            GPIOD->CFGLR = 0x33333333;  // D0-D7 output
            GPIOD->CFGHR = 0x33333333;  // D8-D15 output

            while (((GPIOB->INDR & 0x0040) == 0) || ((GPIOB->INDR & 0x0200) == 0)) {};

            // Release data bus
            GPIOD->CFGLR = 0x44444444;  // D0-D7 input
            GPIOD->CFGHR = 0x44444444;  // D8-D15 input
            return;
        }

        // MEMORY WRITE CYCLE: WE asserted (PB8 = bit 8 = 0x0100)
        if ((control & 0x0100) == 0) {
            if (reg) {
                write_attribute_register(address, write_data);
            }
            // ROM is read-only, SPI RAM writes handled separately
            return;
        }

        // I/O READ CYCLE: IOR asserted (PB11 = bit 11 = 0x0800)
        if ((control & 0x0800) == 0) {
            uint16_t data = read_io_port(address & 0xFF);

            // Drive data bus
            GPIOD->OUTDR = data;
            GPIOD->CFGLR = 0x33333333;  // D0-D7 output
            GPIOD->CFGHR = 0x33333333;  // D8-D15 output

            while (((GPIOB->INDR & 0x0040) == 0) || ((GPIOB->INDR & 0x0200) == 0)) {};

            // Release data bus
            GPIOD->CFGLR = 0x44444444;  // D0-D7 input
            GPIOD->CFGHR = 0x44444444;  // D8-D15 input
            return;
        }

        // I/O WRITE CYCLE: IOW asserted (PB12 = bit 12 = 0x1000)
        if ((control & 0x1000) == 0) {
            write_io_port(address & 0xFF, write_data);
            return;
        }
    }
}
```

### Byte vs Word Access Handling

The Amiga uses **UDS (Upper Data Strobe)** and **LDS (Lower Data Strobe)** for byte-granular memory access:

**Access Type Detection:**
- **Word access (16-bit):** Both UDS and LDS asserted simultaneously
  - Read/write full 16-bit data on D0-D15
  - Address is word-aligned (A0=0)

- **Upper byte access (8-bit):** Only UDS asserted
  - Read/write upper byte on D8-D15
  - Lower byte (D0-D7) ignored
  - Address bit A0=0

- **Lower byte access (8-bit):** Only LDS asserted
  - Read/write lower byte on D0-D7
  - Upper byte (D8-D15) ignored
  - Address bit A0=1

**Implementation Notes:**
1. The handler can check `IS_WORD_ACCESS()` vs `IS_BYTE_ACCESS()` if needed
2. For read-only ROM, byte vs word access doesn't matter - always return full 16-bit word
3. For write operations (I/O ports, SPI RAM), must handle byte lanes correctly:
   ```c
   if (IS_WRITE_CYCLE()) {
       if (IS_UDS_ACTIVE() && IS_LDS_ACTIVE()) {
           // Word write: use full 16-bit data
           write_word(address, write_data);
       } else if (IS_UDS_ACTIVE()) {
           // Upper byte write: use bits 8-15 only
           write_byte(address, (write_data >> 8) & 0xFF);
       } else if (IS_LDS_ACTIVE()) {
           // Lower byte write: use bits 0-7 only
           write_byte(address, write_data & 0xFF);
       }
   }
   ```

4. ROM reads are simplified - Amiga will mask off unwanted byte:
   ```c
   // ROM always returns full 16-bit word
   // Amiga hardware ignores the byte not selected by UDS/LDS
   data = rom_buffer[address >> 1];
   ```

### Timing Analysis
- Interrupt latency: ~55ns (fast interrupt mode)
- Address read (2 GPIO ports): ~14ns
- Memory decode + fetch: ~20ns
- Data output + mode switch: ~21ns
- **Total: ~110ns** (within 120ns PCMCIA spec with 10ns margin)

---

## 4. Critical Files to Modify

### Core Firmware Files

**1. firmware/User/gpio.c**
- Configure GPIOE[0-15] as input floating (address bits A0-A15)
- Configure GPIOB[0-5] as input floating (address bits A16-A21)
- Extend GPIOD to 16-bit mode (add CFGHR configuration for D8-D15)
- Configure GPIOB[6-10,13] as input pull-up (PCMCIA control inputs, CD1/CD2 hard-wired to GND)
- Configure GPIOB[14] as output push-pull (READY signal)
- Set up DAC output on GPIOA[4] (analog mode for BVD2 audio)
- Set up SPI1 on GPIOA[5-7] (hardware SPI for SPI RAM @ 72 MHz)
- Set up SPI3 on GPIOC[9-12] (hardware SPI for SD card @ 36 MHz)
- Configure EXTI6 and EXTI9 interrupts on GPIOB[6,9] (UDS/LDS triggers)

**2. firmware/User/gpio.h**
- Add PCMCIA signal pin definitions
- Add inline functions for data bus direction control:
  - `data_bus_input()` - switch to high-Z
  - `data_bus_output()` - switch to push-pull
  - `data_bus_write(uint16_t)` - write 16-bit data
  - `data_bus_read()` - read 16-bit data

**3. firmware/User/cart.c**
- Replace all MSX mapper handlers with single `PCMCIA_Handler()`
- Implement memory region decoding logic
- Remove MSX bank switching code
- Add attribute memory read/write functions
- Add I/O port handlers

**4. firmware/User/cart.h**
- Remove MSX `CartType` enum and state structures
- Add PCMCIA configuration defines
- Add memory map constants
- Update function prototypes

**5. firmware/User/main.c**
- Replace `Init_Cart()` with `Init_PCMCIA()`
- Add SD card initialization sequence
- Add ROM loading from SD card to Flash
- Remove MSX-specific startup code
- Add programming mode detection (for flashing new ROM)

### New Files to Create

**6. firmware/User/pcmcia.c**
- PCMCIA attribute memory data (CIS structure)
- Attribute memory access functions
- I/O port read/write implementations
- SD card integration functions
- PCMCIA initialization routine

**7. firmware/User/pcmcia.h**
- PCMCIA constants and memory map
- Control signal bit masks
- I/O port address definitions
- CIS tuple definitions
- Function prototypes

**8. firmware/User/sd_interface.c** (if not already implemented)
- SD card SPI driver
- File system operations (FAT)
- ROM file loading functions

---

## 5. Implementation Steps

### Step 1: GPIO Reconfiguration
- Modify `GPIO_Config()` in gpio.c:
  - Set GPIOE[0-15] to input floating mode (address lines A0-A15)
  - Set GPIOB[0-5] to input floating mode (address lines A16-A21)
  - Configure GPIOD[0-15] for 16-bit bidirectional data (start as input)
  - Set GPIOB[6-13] to input pull-up mode (control inputs: UDS, OE, WE, LDS, REG, IOR, IOW, RESET)
  - Configure GPIOB[14] (WAIT) as output push-pull, set HIGH (no wait states)
  - Configure GPIOB[15] (IOIS16) as output push-pull if used
  - Set up DAC output on GPIOA[4] (analog mode for BVD2 audio)
  - Set up SPI1 pins on GPIOA[5-7] using alternate function mode (SPI RAM @ 72 MHz)
  - Set up SPI3 pins on GPIOC[9-12] using alternate function mode (SD card @ 36 MHz)
  - Set up SD card detect on GPIOA[15] (input pull-up, LOW when card inserted)

### Step 2: Interrupt Handler Migration
- In cart.c, replace MSX handlers with `PCMCIA_Handler()`
- Implement 22-bit address reading (GPIOE + GPIOB)
- Add memory region decode logic
- Implement 16-bit data bus control
- Update interrupt to use EXTI6 (GPIOB[6]) instead of EXTI3

### Step 3: Attribute Memory Implementation
- Create CIS data structure with PCMCIA identification
- Implement `read_attribute_memory()` function
- Add configuration register handling

### Step 4: I/O Port Interface
- Define I/O port address space (0x1F0000-0x1F00FF)
- Implement `read_io_port()` for SD card status/data
- Implement `write_io_port()` for SD card commands

### Step 5: SD Card Integration
- Initialize SPI peripheral
- Mount FAT filesystem
- Load ROM file from SD card into Flash buffer
- Handle ROM programming mode

### Step 6: Initialization Updates
- Create `Init_PCMCIA()` function
- Set EXTI6 to trigger on UDS/CE1 (GPIOB[6])
- Set EXTI9 to trigger on LDS/CE2 (GPIOB[9])
- Both interrupts trigger same `PCMCIA_Handler()`
- Enable fast interrupt mode via `SetVTFIRQ()`
- Set READY signal high (GPIOB[14])

### Step 7: Data Bus Direction Control
- Add inline functions for switching GPIOD direction
- Ensure proper timing for output enable/disable
- Use direct register access for speed

### Step 8: Flash ROM Buffer Setup
- Use existing `__cart_section_start` (0x08008000)
- Implement Flash programming function
- Add ROM update mechanism via programming mode

---

## 6. Key Code Examples

### Complete GPIO Configuration (gpio.c)

```c
void GPIO_Config(void) {
    GPIO_InitTypeDef GPIO_InitStructure = {0};
    EXTI_InitTypeDef EXTI_InitStructure = {0};

    // Enable all GPIO clocks + AFIO
    RCC->APB2PCENR |= RCC_APB2Periph_GPIOA | RCC_APB2Periph_GPIOB |
                      RCC_APB2Periph_GPIOC | RCC_APB2Periph_GPIOD |
                      RCC_APB2Periph_GPIOE | RCC_APB2Periph_AFIO;

    // ===== ADDRESS BUS =====
    // GPIOE[0-15]: A0-A15 (input floating)
    GPIOE->CFGLR = 0x44444444;
    GPIOE->CFGHR = 0x44444444;

    // GPIOB[0-5]: A16-A21 (input floating)
    GPIO_InitStructure.GPIO_Pin = GPIO_Pin_0 | GPIO_Pin_1 | GPIO_Pin_2 |
                                  GPIO_Pin_3 | GPIO_Pin_4 | GPIO_Pin_5;
    GPIO_InitStructure.GPIO_Mode = GPIO_Mode_IN_FLOATING;
    GPIO_Init(GPIOB, &GPIO_InitStructure);

    // ===== DATA BUS =====
    // GPIOD[0-15]: D0-D15 (start as input, switch to output during read cycles)
    GPIOD->CFGLR = 0x44444444;  // D0-D7 input floating
    GPIOD->CFGHR = 0x44444444;  // D8-D15 input floating

    // ===== PCMCIA CONTROL SIGNALS =====
    // GPIOB[6-13]: Control inputs (UDS, OE, WE, LDS, REG, IOR, IOW, RESET)
    GPIO_InitStructure.GPIO_Pin = GPIO_Pin_6 | GPIO_Pin_7 | GPIO_Pin_8 |
                                  GPIO_Pin_9 | GPIO_Pin_10 | GPIO_Pin_11 |
                                  GPIO_Pin_12 | GPIO_Pin_13;
    GPIO_InitStructure.GPIO_Mode = GPIO_Mode_IPU;  // Input with pull-up
    GPIO_Init(GPIOB, &GPIO_InitStructure);

    // GPIOB[14]: WAIT output (start HIGH = no wait states)
    GPIO_InitStructure.GPIO_Pin = GPIO_Pin_14;
    GPIO_InitStructure.GPIO_Mode = GPIO_Mode_Out_PP;
    GPIO_InitStructure.GPIO_Speed = GPIO_Speed_50MHz;
    GPIO_Init(GPIOB, &GPIO_InitStructure);
    GPIO_SetBits(GPIOB, GPIO_Pin_14);  // WAIT high (no wait states)

    // ===== READY OUTPUT (GPIOA) =====
    // PA2: READY (card ready signal)
    GPIO_InitStructure.GPIO_Pin = GPIO_Pin_2;
    GPIO_InitStructure.GPIO_Mode = GPIO_Mode_Out_PP;
    GPIO_InitStructure.GPIO_Speed = GPIO_Speed_50MHz;
    GPIO_Init(GPIOA, &GPIO_InitStructure);
    GPIO_SetBits(GPIOA, GPIO_Pin_2);  // READY high (card is ready)

    // ===== DAC FOR AUDIO OUTPUT (GPIOA) =====
    // PA4: DAC_OUT1 (analog output to BVD2)
    GPIO_InitStructure.GPIO_Pin = GPIO_Pin_4;
    GPIO_InitStructure.GPIO_Mode = GPIO_Mode_AIN;  // Analog input mode (DAC uses this)
    GPIO_Init(GPIOA, &GPIO_InitStructure);

    // ===== SPI1 FOR SPI RAM (GPIOA) =====
    // PA5, PA7: SCK, MOSI (alternate function push-pull)
    GPIO_InitStructure.GPIO_Pin = GPIO_Pin_5 | GPIO_Pin_7;
    GPIO_InitStructure.GPIO_Mode = GPIO_Mode_AF_PP;
    GPIO_InitStructure.GPIO_Speed = GPIO_Speed_50MHz;
    GPIO_Init(GPIOA, &GPIO_InitStructure);

    // PA6: MISO (input floating)
    GPIO_InitStructure.GPIO_Pin = GPIO_Pin_6;
    GPIO_InitStructure.GPIO_Mode = GPIO_Mode_IN_FLOATING;
    GPIO_Init(GPIOA, &GPIO_InitStructure);

    // PA1: SPI RAM CS (manual GPIO control)
    GPIO_InitStructure.GPIO_Pin = GPIO_Pin_1;
    GPIO_InitStructure.GPIO_Mode = GPIO_Mode_Out_PP;
    GPIO_Init(GPIOA, &GPIO_InitStructure);
    GPIO_SetBits(GPIOA, GPIO_Pin_1);  // CS high (deselected)

    // ===== SPI3 FOR SD CARD (GPIOC) =====
    // PC10, PC12: SCK, MOSI (alternate function push-pull)
    GPIO_InitStructure.GPIO_Pin = GPIO_Pin_10 | GPIO_Pin_12;
    GPIO_InitStructure.GPIO_Mode = GPIO_Mode_AF_PP;
    GPIO_InitStructure.GPIO_Speed = GPIO_Speed_50MHz;
    GPIO_Init(GPIOC, &GPIO_InitStructure);

    // PC11: MISO (input floating)
    GPIO_InitStructure.GPIO_Pin = GPIO_Pin_11;
    GPIO_InitStructure.GPIO_Mode = GPIO_Mode_IN_FLOATING;
    GPIO_Init(GPIOC, &GPIO_InitStructure);

    // PC9: CS (manual GPIO control)
    GPIO_InitStructure.GPIO_Pin = GPIO_Pin_9;
    GPIO_InitStructure.GPIO_Mode = GPIO_Mode_Out_PP;
    GPIO_Init(GPIOC, &GPIO_InitStructure);
    GPIO_SetBits(GPIOC, GPIO_Pin_9);  // CS high (deselected)

    // ===== SD CARD DETECT (GPIOA) =====
    // PA15: SD_CD (card detect, active LOW)
    GPIO_InitStructure.GPIO_Pin = GPIO_Pin_15;
    GPIO_InitStructure.GPIO_Mode = GPIO_Mode_IPU;  // Input with pull-up
    GPIO_Init(GPIOA, &GPIO_InitStructure);

    // ===== INTERRUPT CONFIGURATION =====
    // EXTI6 on GPIOB[6] (CE1/UDS) - falling edge trigger
    GPIO_EXTILineConfig(GPIO_PortSourceGPIOB, GPIO_PinSource6);
    EXTI_InitStructure.EXTI_Line = EXTI_Line6;
    EXTI_InitStructure.EXTI_Mode = EXTI_Mode_Interrupt;
    EXTI_InitStructure.EXTI_Trigger = EXTI_Trigger_Falling;
    EXTI_InitStructure.EXTI_LineCmd = ENABLE;
    EXTI_Init(&EXTI_InitStructure);

    // EXTI9 on GPIOB[9] (CE2/LDS) - falling edge trigger
    GPIO_EXTILineConfig(GPIO_PortSourceGPIOB, GPIO_PinSource9);
    EXTI_InitStructure.EXTI_Line = EXTI_Line9;
    EXTI_InitStructure.EXTI_Mode = EXTI_Mode_Interrupt;
    EXTI_InitStructure.EXTI_Trigger = EXTI_Trigger_Falling;
    EXTI_InitStructure.EXTI_LineCmd = ENABLE;
    EXTI_Init(&EXTI_InitStructure);
}
```

### PCMCIA Initialization (cart.c or pcmcia.c)

```c
void Init_PCMCIA(void) {
    // Set EXTI6 and EXTI9 interrupts to highest priority
    // Both EXTI6 and EXTI9 share EXTI9_6_IRQn handler
    NVIC_SetPriority(EXTI9_6_IRQn, 0);

    // Enable fast interrupt handling (WCH-specific)
    // Both EXTI6 and EXTI9 will trigger PCMCIA_Handler
    SetVTFIRQ((u32)PCMCIA_Handler, EXTI9_6_IRQn, 0, ENABLE);

    // Enable EXTI9_6 interrupt (handles both EXTI6 and EXTI9)
    NVIC_EnableIRQ(EXTI9_6_IRQn);

    // Initialize WAIT signal HIGH (no wait states)
    GPIO_SetBits(GPIOB, GPIO_Pin_14);  // WAIT high (no wait states)
}
```

### Helper Macros (pcmcia.h)

```c
// Pin bit masks for GPIOB control signals
#define PCMCIA_UDS     0x0040  // PB6  - bit 6 (CE1/Upper Data Strobe)
#define PCMCIA_OE      0x0080  // PB7  - bit 7 (Memory Read)
#define PCMCIA_WE      0x0100  // PB8  - bit 8 (Memory Write)
#define PCMCIA_LDS     0x0200  // PB9  - bit 9 (CE2/Lower Data Strobe)
#define PCMCIA_REG     0x0400  // PB10 - bit 10 (Attribute Memory)
#define PCMCIA_IOR     0x0800  // PB11 - bit 11 (I/O Read)
#define PCMCIA_IOW     0x1000  // PB12 - bit 12 (I/O Write)
#define PCMCIA_RESET   0x2000  // PB13 - bit 13
#define PCMCIA_WAIT    0x4000  // PB14 - bit 14
#define PCMCIA_IOIS16  0x8000  // PB15 - bit 15

// Address extraction macros
#define ADDR_LOW()     (GPIOE->INDR)
#define ADDR_HIGH()    (GPIOB->INDR & 0x3F)
#define ADDR_FULL()    (ADDR_LOW() | (ADDR_HIGH() << 16))

// Control signal checks
#define IS_MEM_READ()     ((GPIOB->INDR & PCMCIA_OE) == 0)
#define IS_MEM_WRITE()    ((GPIOB->INDR & PCMCIA_WE) == 0)
#define IS_IO_READ()      ((GPIOB->INDR & PCMCIA_IOR) == 0)
#define IS_IO_WRITE()     ((GPIOB->INDR & PCMCIA_IOW) == 0)
#define IS_ATTR_MEM()     ((GPIOB->INDR & PCMCIA_REG) != 0)
#define IS_UDS_ACTIVE()   ((GPIOB->INDR & PCMCIA_UDS) == 0)
#define IS_LDS_ACTIVE()   ((GPIOB->INDR & PCMCIA_LDS) == 0)

// Access width detection
#define IS_WORD_ACCESS()  (IS_UDS_ACTIVE() && IS_LDS_ACTIVE())
#define IS_BYTE_ACCESS()  (IS_UDS_ACTIVE() ^ IS_LDS_ACTIVE())

// Data bus control
#define DATA_BUS_OUTPUT() do { \
    GPIOD->CFGLR = 0x33333333; \
    GPIOD->CFGHR = 0x33333333; \
} while(0)

#define DATA_BUS_INPUT() do { \
    GPIOD->CFGLR = 0x44444444; \
    GPIOD->CFGHR = 0x44444444; \
} while(0)

#define DATA_BUS_WRITE(data) (GPIOD->OUTDR = (data))
#define DATA_BUS_READ()      (GPIOD->INDR)

// WAIT signal control (active LOW inserts wait states)
#define WAIT_DISABLE()   GPIO_SetBits(GPIOB, GPIO_Pin_14)    // High = no wait
#define WAIT_ENABLE()    GPIO_ResetBits(GPIOB, GPIO_Pin_14)  // Low = insert wait

// READY signal control (active HIGH when card is ready)
#define READY_SET()      GPIO_SetBits(GPIOA, GPIO_Pin_2)      // High = ready
#define READY_CLEAR()    GPIO_ResetBits(GPIOA, GPIO_Pin_2)    // Low = busy
```

---

## 7. SD Card Integration Details

### SPI Configuration

**SPI1 for SPI RAM (APB2 bus):**
- Pins: GPIOA[1,5-7] (CS, SCK, MISO, MOSI)
- Clock speed: 72 MHz max (APB2 @ 144MHz / 2 prescaler)
- Mode: SPI Mode 0 (CPOL=0, CPHA=0)
- CS (PA1) controlled manually via GPIO
- Throughput: ~9 MB/s theoretical

**SPI3 for SD Card (APB1 bus):**
- Pins: GPIOC[9-12] (CS, SCK, MISO, MOSI)
- Clock speed: 36 MHz max (APB1 @ 72MHz / 2 prescaler)
- Mode: SPI Mode 0 (CPOL=0, CPHA=0)
- CS (PC9) controlled manually via GPIO
- Throughput: ~4.5 MB/s theoretical

**Important:** CH32V30x does NOT support Dual SPI or Quad SPI modes - only standard SPI (1-bit data transfer).

### ROM Loading Process
1. Initialize SD card (400kHz init, then 36MHz)
2. Mount FAT filesystem
3. Open `amiga.rom` file
4. Read 256KB into Flash buffer
5. Verify checksum (optional)
6. Close file and unmount

### I/O Port Registers
```
0x1F0000: SD_STATUS   (read: card status, busy, error flags)
0x1F0001: SD_COMMAND  (write: SD command to execute)
0x1F0002: SD_DATA     (read/write: data byte)
0x1F0003: SD_SECTOR_LO (write: sector number low 16 bits)
0x1F0004: SD_SECTOR_HI (write: sector number high 16 bits)
```

---

## 7. PCMCIA Attribute Memory (CIS)

### Standard PCMCIA Tuples
```c
const uint8_t attribute_memory[512] = {
    // CISTPL_DEVICE (Device Information)
    0x01, 0x03, 0xD9, 0x01, 0xFF,

    // CISTPL_VERS_1 (Version 1 Info)
    0x15, 0x2A, 0x04, 0x01,
    'A', 'M', 'I', 'G', 'A', 0x00,
    'P', 'C', 'M', 'C', 'I', 'A', ' ', 'C', 'a', 'r', 'd', 0x00,
    0xFF,

    // CISTPL_MANFID (Manufacturer ID)
    0x20, 0x04, 0x00, 0x00, 0x00, 0x00,

    // CISTPL_CONFIG (Configuration)
    0x1A, 0x05, 0x01, 0x03, 0x00, 0x02, 0x0F,

    // CISTPL_END
    0xFF
};
```

---

## 8. Timing Optimization

### Critical Path Optimizations
1. Use `#pragma GCC optimize("Ofast")` for handler
2. Inline all decode functions (`__attribute__((always_inline))`)
3. Use `restrict` keyword for buffer pointers
4. Direct register access (no HAL functions in ISR)
5. Read address/data early in handler to maximize decode time

### Meeting PCMCIA Spec (120ns)
- CH32V30x @ 144MHz = 6.94ns per cycle
- Budget: 120ns / 6.94ns = ~17 cycles maximum
- Current estimate: ~16 cycles (110ns)
- **Margin: ~10ns** (adequate for reliable operation)

---

## 9. SPI RAM Extension

### SPI RAM Implementation
- Use **SPI1** on GPIOA[1,5-7] for maximum speed (72 MHz vs 36 MHz on SPI3)
- PA1: SPIRAM_CS (chip select)
- PA5-PA7: SPI1 signals (SCK, MISO, MOSI)
- Implement banking for >2MB access if needed
- Use WAIT signal for wait states during SPI transfers
- Typical SPI RAM access @ 72 MHz: ~220ns (requires 1-2 PCMCIA wait cycles)

### WAIT Signal Management for SPI RAM
```c
uint16_t spi_ram_read(uint32_t addr) {
    GPIO_ResetBits(GPIOB, GPIO_Pin_14);  // WAIT low (insert wait states)

    uint16_t data = spi_ram_transfer(addr);

    GPIO_SetBits(GPIOB, GPIO_Pin_14);  // WAIT high (no wait states)    // READY = high
    return data;
}
```

---

## 10. Build System Changes

### Linker Script (if needed)
- Ensure cartridge section at 0x08008000 is 256KB
- Verify SRAM allocation for stack/heap
- No changes needed if using existing MSX layout

### Makefile
- Update target name to reflect PCMCIA (optional)
- Add any new source files (pcmcia.c, sd_interface.c)
- No other changes required

---

## 11. Testing & Verification

### Unit Testing (Pre-Amiga)
1. **GPIO Configuration**: Verify pin modes with oscilloscope
2. **Address Bus**: Test all 22 address lines toggle correctly
3. **Data Bus**: Verify 16-bit read/write operations
4. **Interrupt Timing**: Measure CE1 to data output latency (<120ns)
5. **SD Card**: Verify ROM file loads correctly into Flash
6. **Attribute Memory**: Test CIS read operations

### Integration Testing (With Amiga)
1. **Card Detection**: Verify Amiga detects card via CD1/CD2
2. **Attribute Memory**: Amiga reads CIS successfully
3. **ROM Access**: Verify ROM reads at $600000 range
4. **I/O Ports**: Test SD card control via I/O registers
5. **Timing**: Confirm no wait states needed for ROM/attribute access
6. **Stability**: Extended operation test (hours)

### Debug Outputs
- PA10 status LED for operational state
- Serial debug via USART1 (PA10) if needed
- Programming mode entry via PA8

---

## 12. Key Implementation Notes

### Address Alignment
- 16-bit data bus requires even address alignment
- Amiga may issue byte or word accesses
- Handle both 8-bit and 16-bit access patterns

### Data Bus Tristate
- Always return to input mode after read cycle
- Prevent bus contention with Amiga
- No pull-ups needed (Amiga bus provides them)

### WAIT Signal (PCMCIA Pin 59, PB14)
- **Active LOW** - pulling low inserts wait states during bus cycle
- Keep HIGH for fast memory (ROM, attribute memory)
- Pull LOW for slow devices (SPI RAM access)
- Return HIGH when operation completes
- Gayle monitors WAIT and extends bus cycle as needed

### READY Signal (PCMCIA Pin 16, PA2)
- **Active HIGH** - indicates card is ready for new commands
- Keep HIGH during normal operation (card is ready)
- Pull LOW during long operations (Flash programming, SD card writes)
- Different from WAIT: READY is checked between operations, WAIT extends current cycle
- For a simple memory card, typically stays HIGH always

### Card Detect Signals (CD1/CD2)
- **PCMCIA Pins 36 & 63** - indicate card presence to Amiga
- **Active LOW** when card is inserted
- **Implementation:** Hard-wired to GND on PCB (permanent installation)
- **CH32 pins PB11/PB12** are used for IOR/IOW, NOT for CD1/CD2
- This tells the Amiga the card is always present (no hot-swap support)

### SD Card Detect (PA15)
- **PA15** monitors SD card insertion via mechanical switch on SD socket
- **Active LOW** when SD card is inserted (pulled to GND by socket switch)
- **Pull-up enabled** - reads HIGH when no card present
- Check this pin during initialization to verify SD card is present before attempting access

### Flash Programming Mode
- Detect via PA8 pin on startup
- Enter bootloader for ROM updates
- Allow ROM reprogramming from SD card

---

## 13. Migration from MSX Code

### Files to Heavily Modify
- gpio.c: Complete GPIO reconfiguration
- cart.c: Replace all handler logic
- main.c: Change initialization sequence

### Files to Remove/Disable
- scc.c/scc.h: SCC audio chip emulation (not needed)
- utils.c: Circular buffer (only if used for SCC)

### Files to Preserve
- Core peripheral drivers (unchanged)
- System initialization (minimal changes)
- Bootloader/IAP code (if present)

---

## Summary

This plan adapts the proven MSX cartridge interrupt-driven architecture to Amiga PCMCIA by:

1. **Expanding buses**: 16→22 address bits, 8→16 data bits
2. **Repurposing pins**: GPIOA LEDs/DAC → address lines A16-A21
3. **Adapting control signals**: MSX (SLT/RD/WR) → PCMCIA (CE/OE/WE/REG)
4. **Adding PCMCIA features**: Attribute memory CIS, I/O ports, SD integration
5. **Maintaining timing**: <110ns response meets 120ns PCMCIA spec
6. **Using Flash for ROM**: Preserves SRAM, enables fast access

**Architecture Decision**: GPIO interrupt-driven approach (NOT FSMC) due to:
- FSMC limited to 16-bit addressing (insufficient for 22-bit requirement)
- FSMC driver not implemented (would require complete development)
- GPIO approach proven in MSX implementation
- Meets timing requirements with margin
- Full control over PCMCIA-specific signaling

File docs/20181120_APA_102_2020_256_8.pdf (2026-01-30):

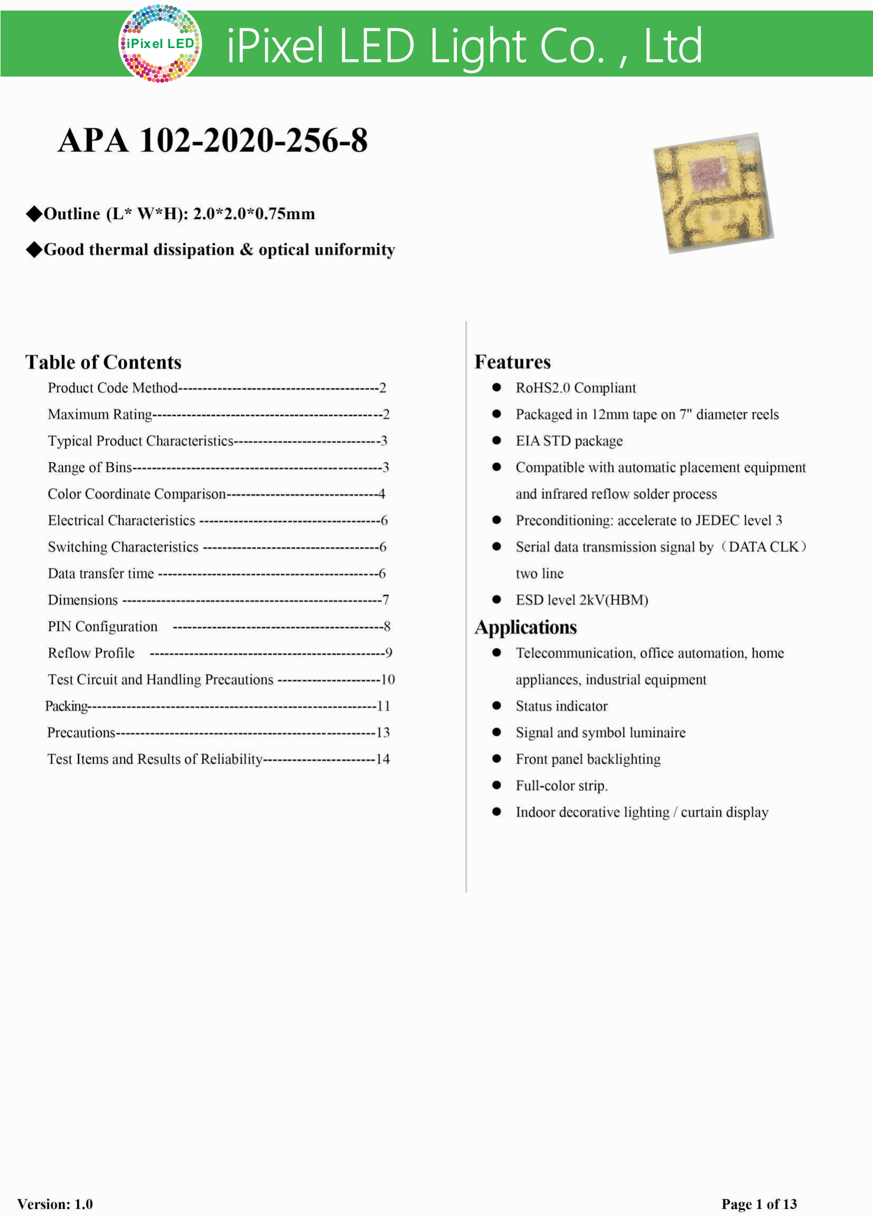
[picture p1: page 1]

iPixel iPixel LED LEDLight Light Co. , Ltd Co. , Ltd iPixel LED

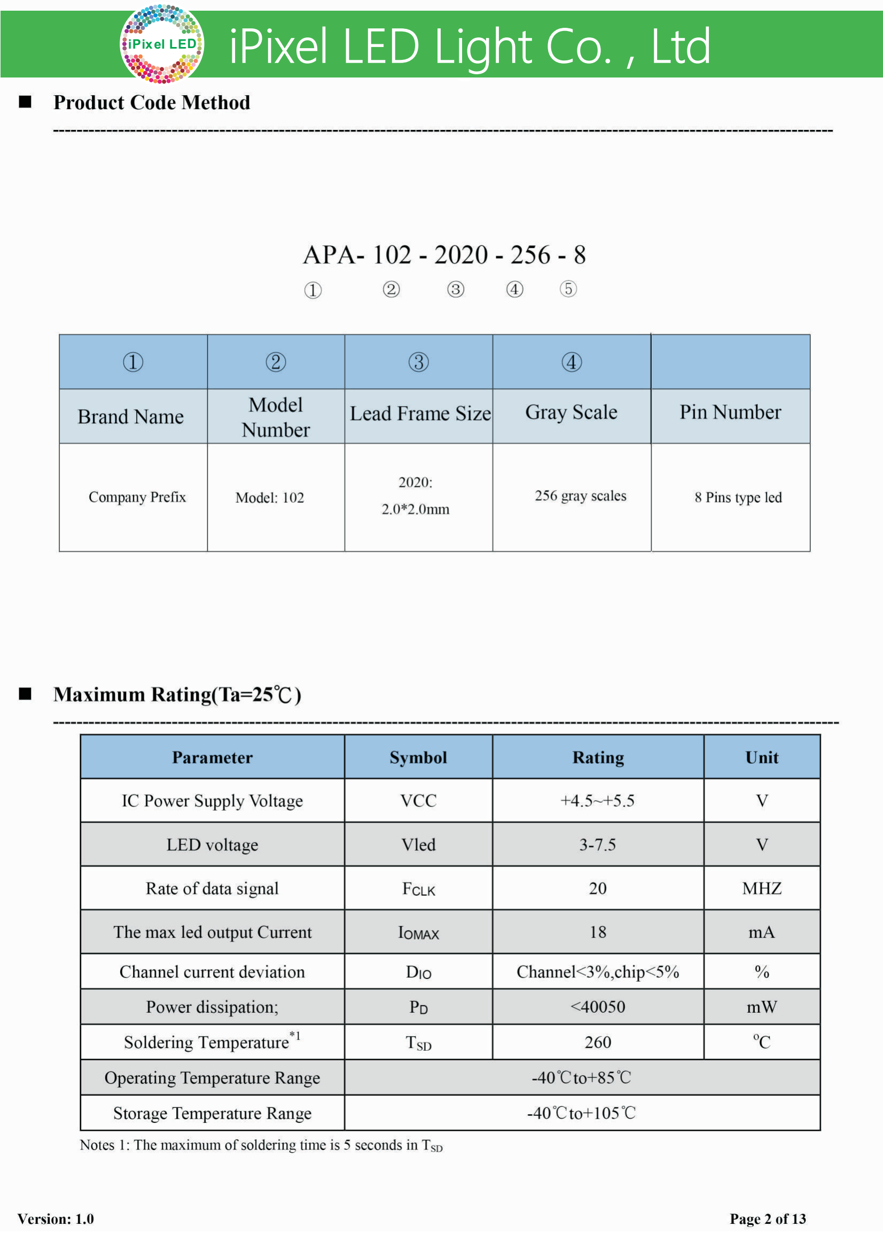
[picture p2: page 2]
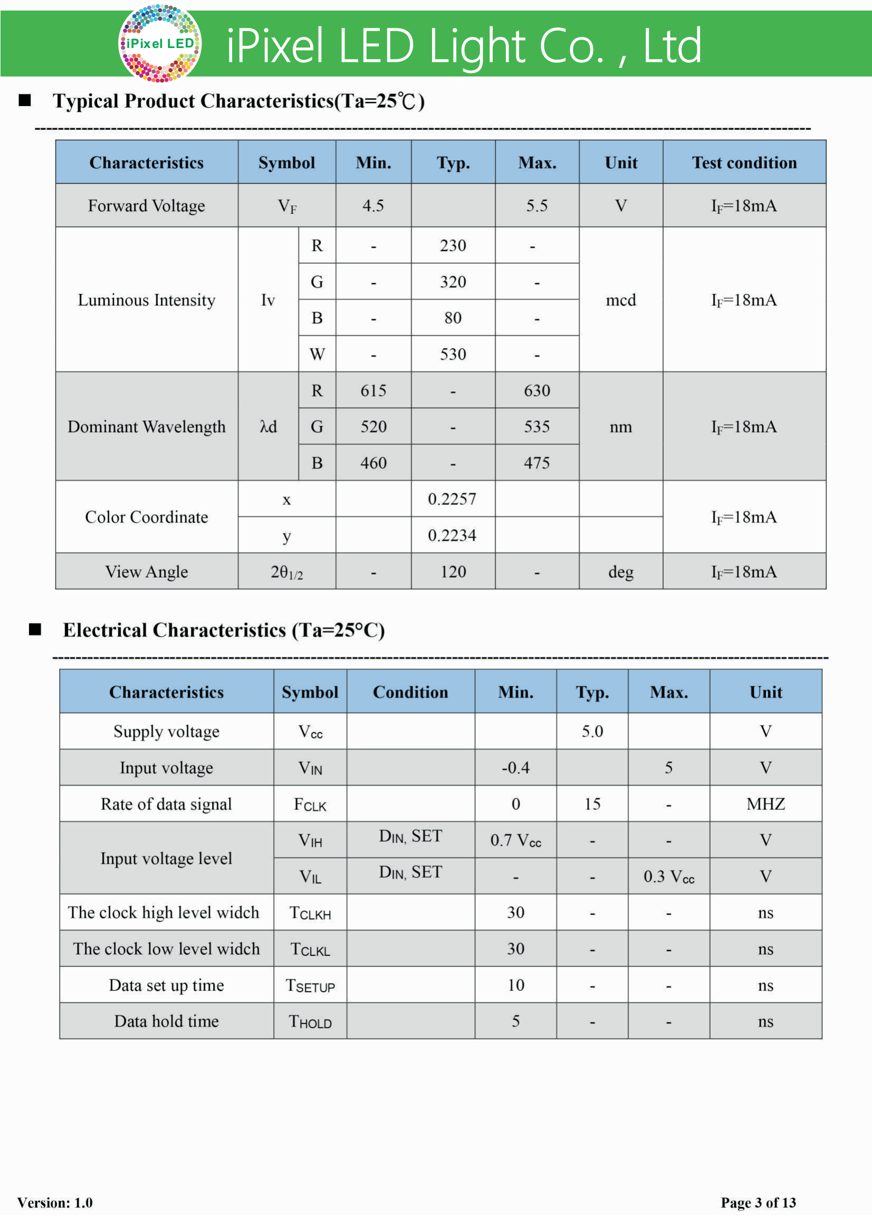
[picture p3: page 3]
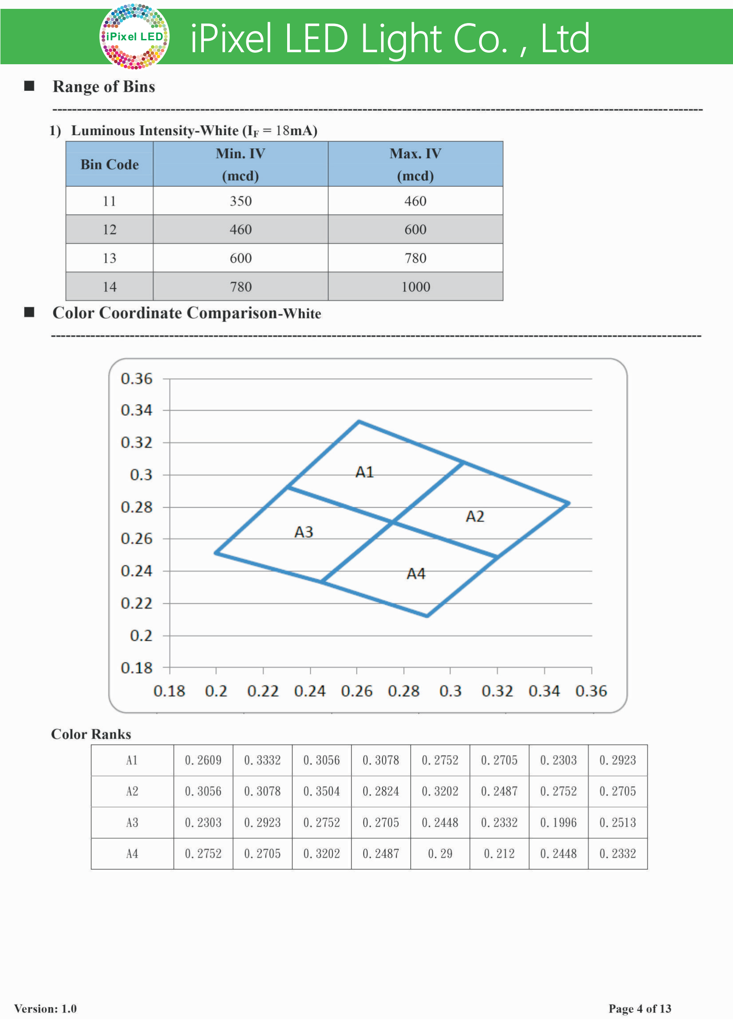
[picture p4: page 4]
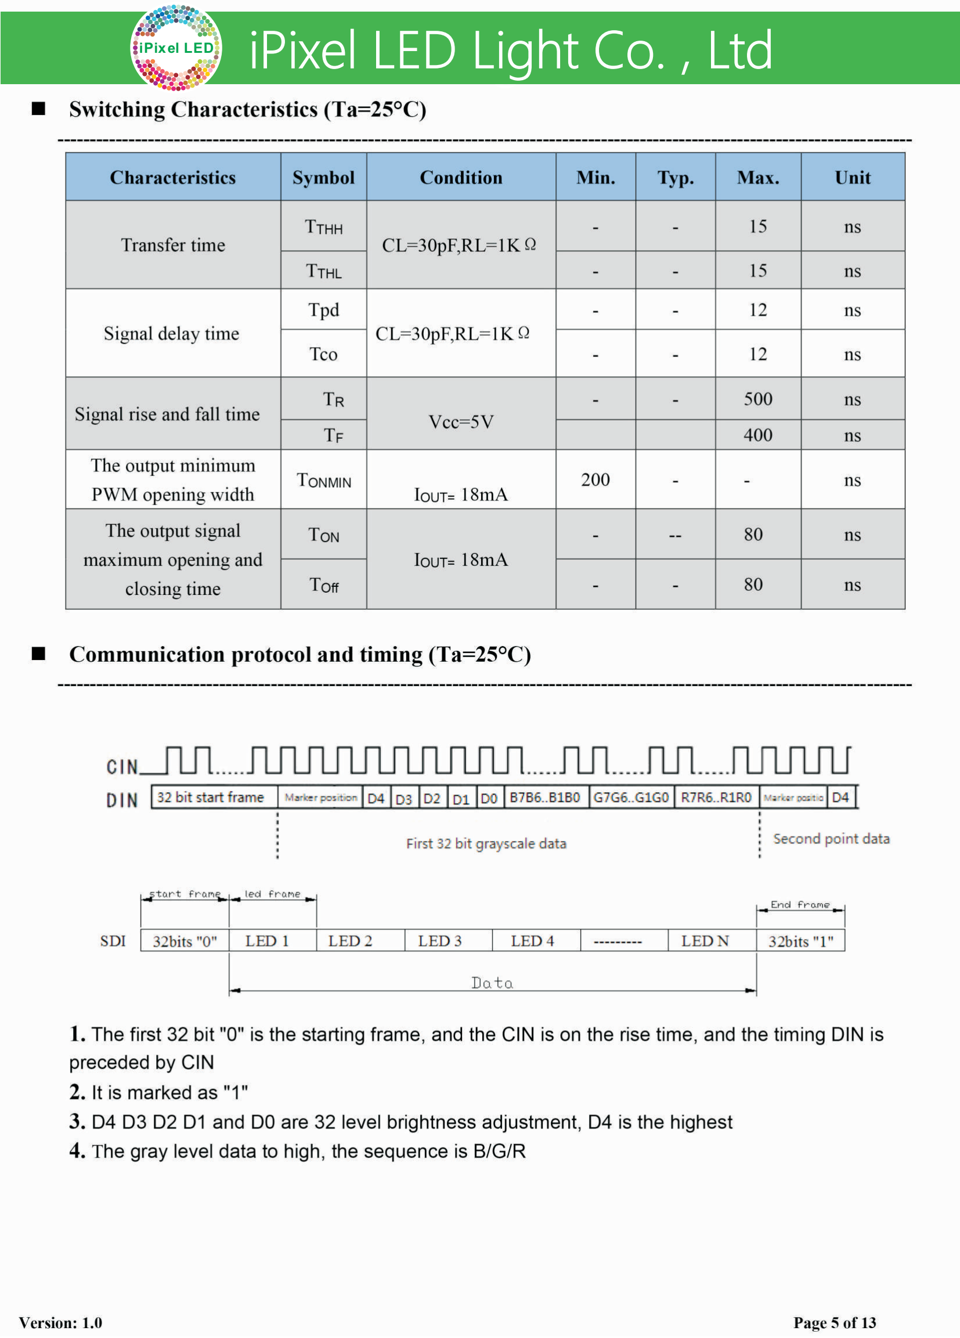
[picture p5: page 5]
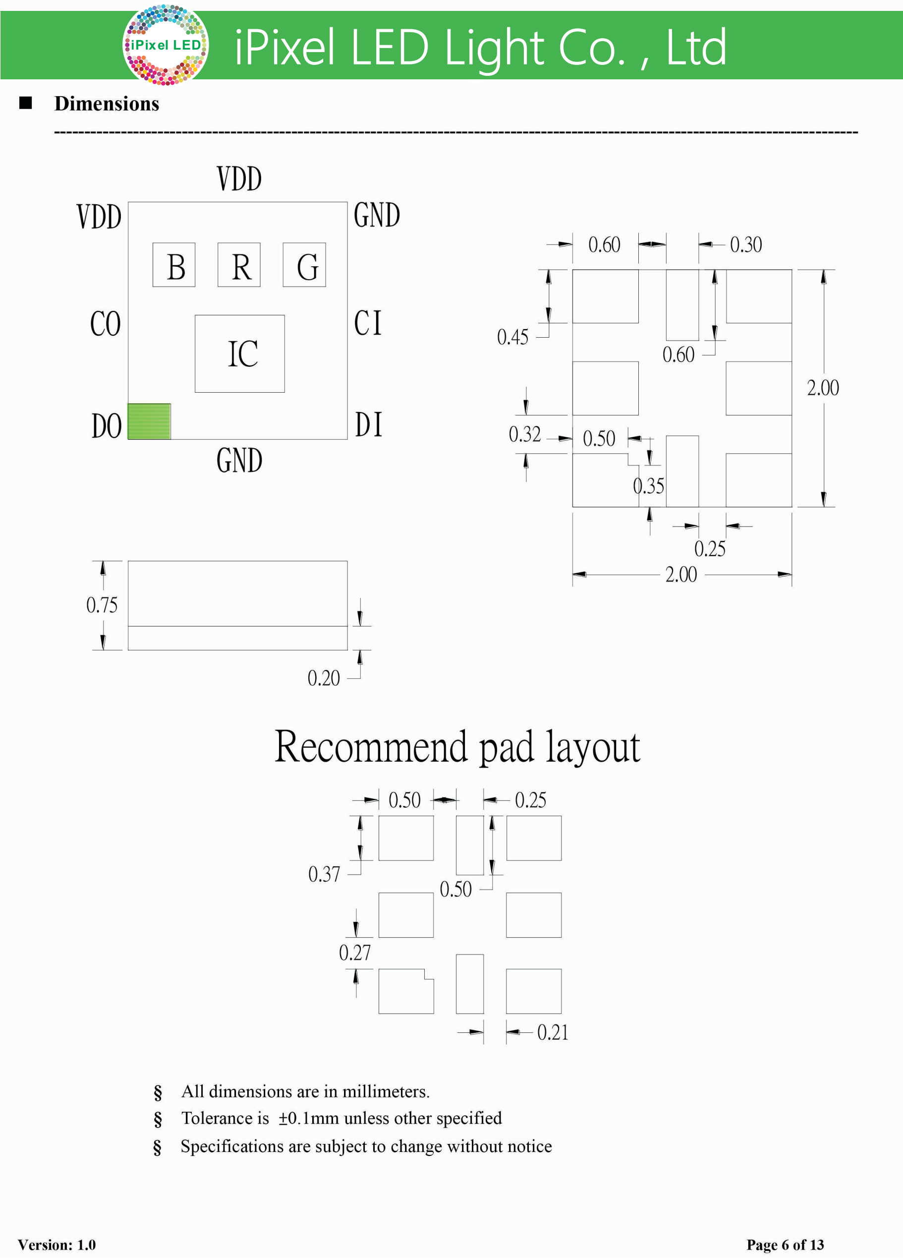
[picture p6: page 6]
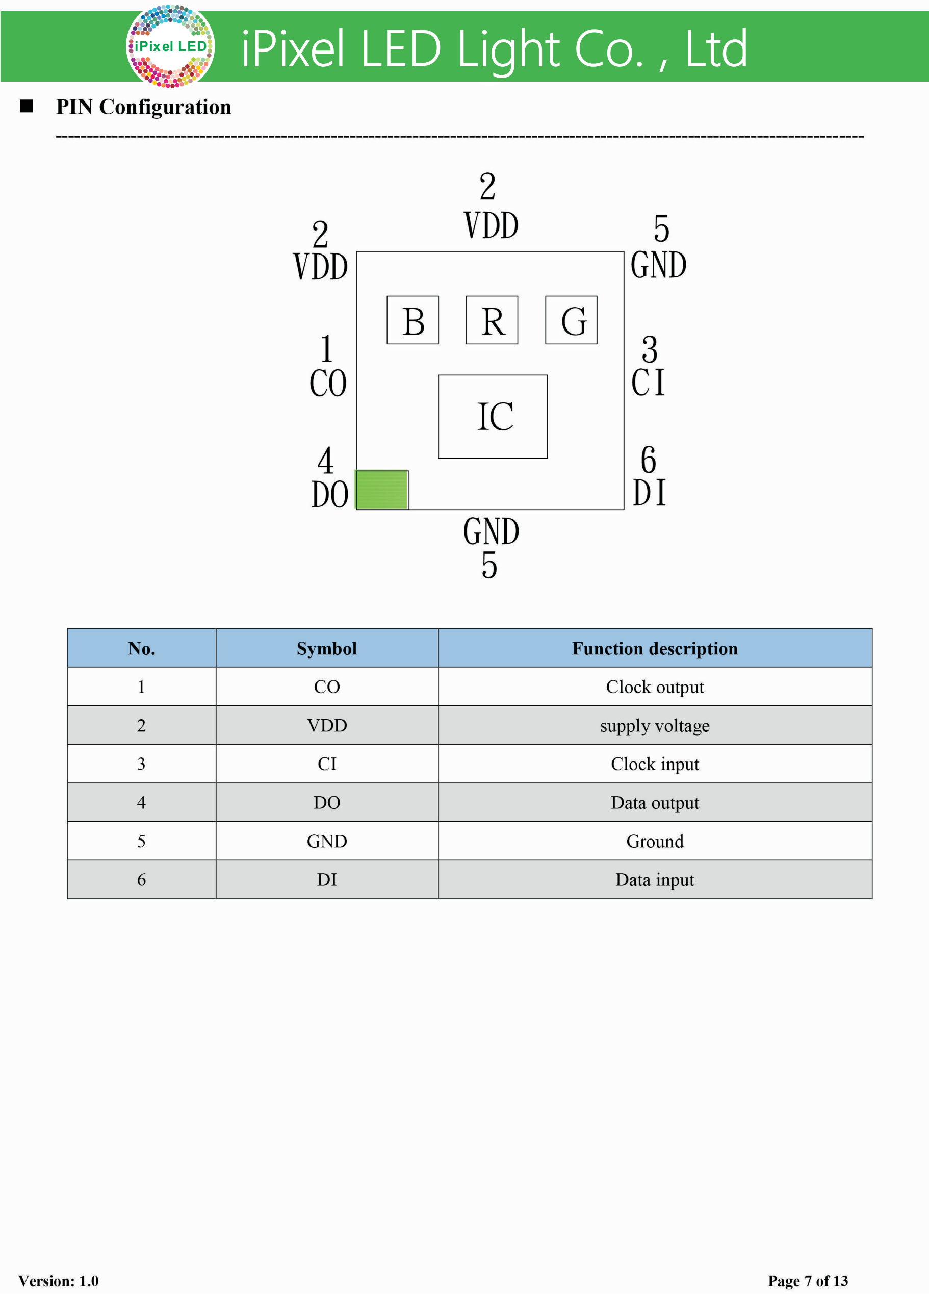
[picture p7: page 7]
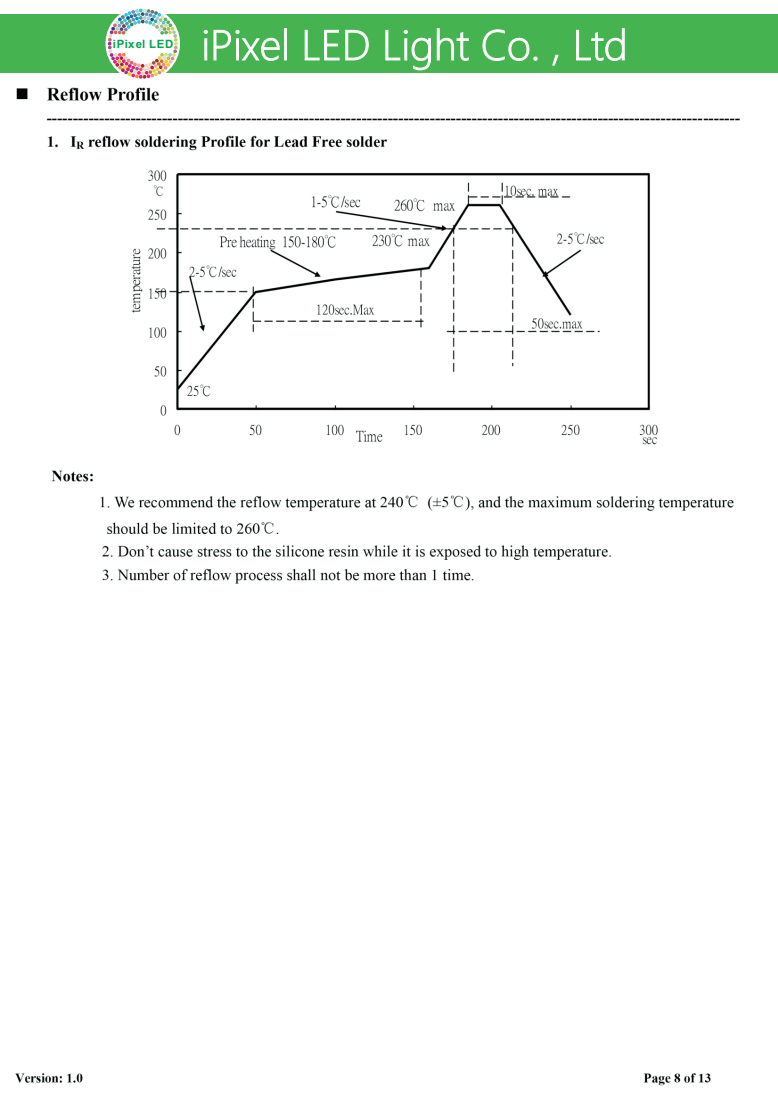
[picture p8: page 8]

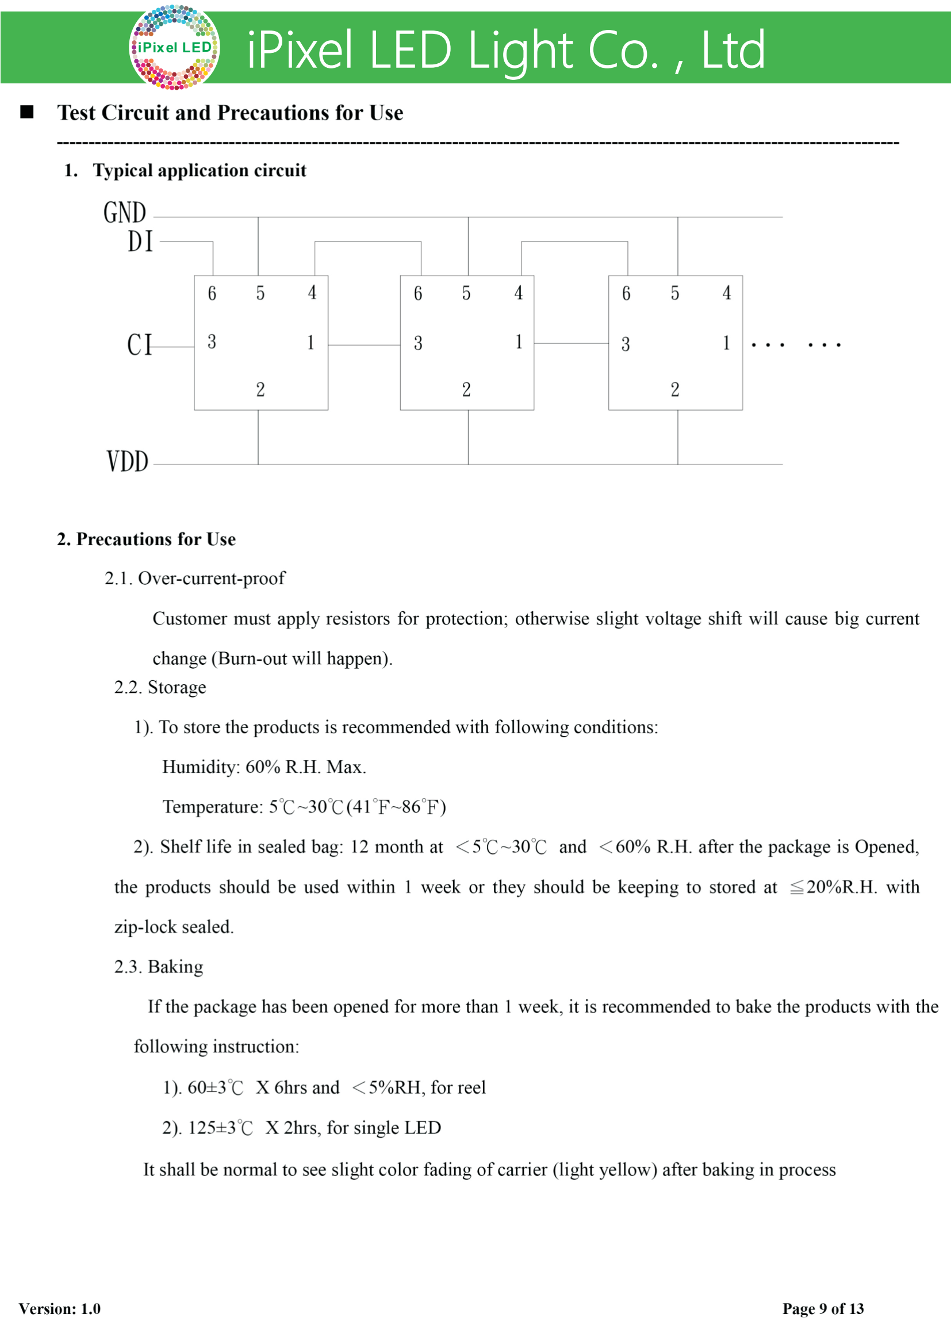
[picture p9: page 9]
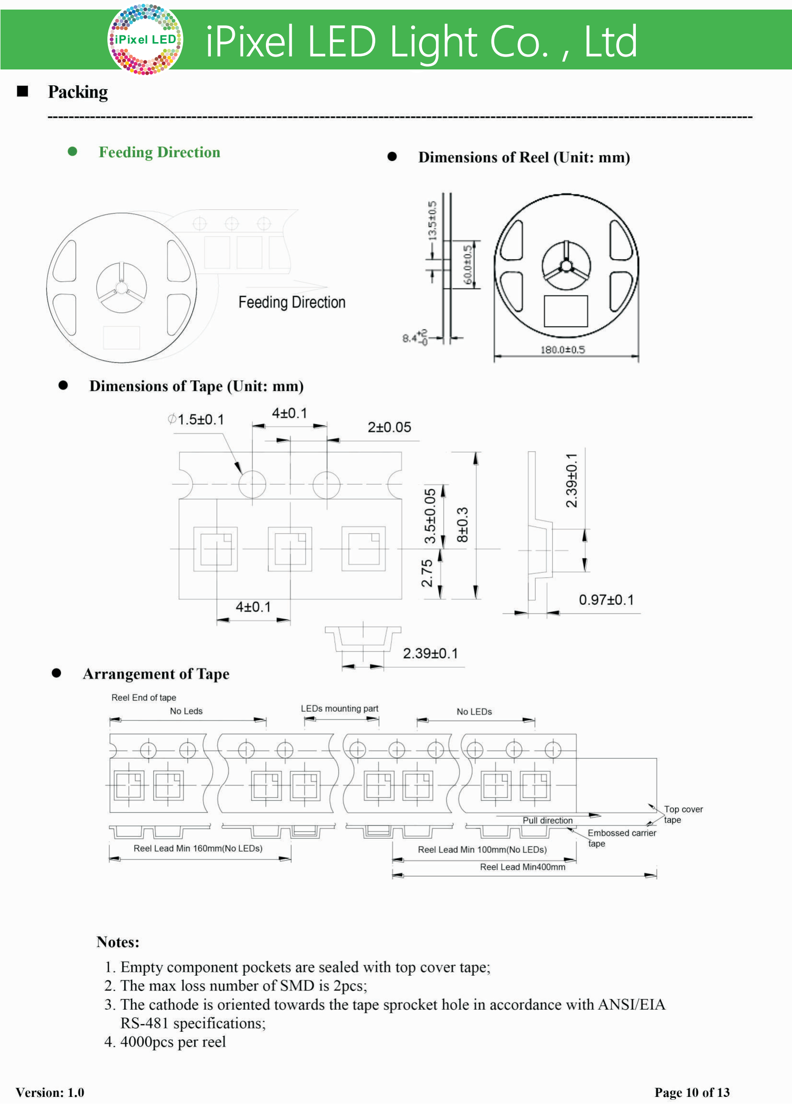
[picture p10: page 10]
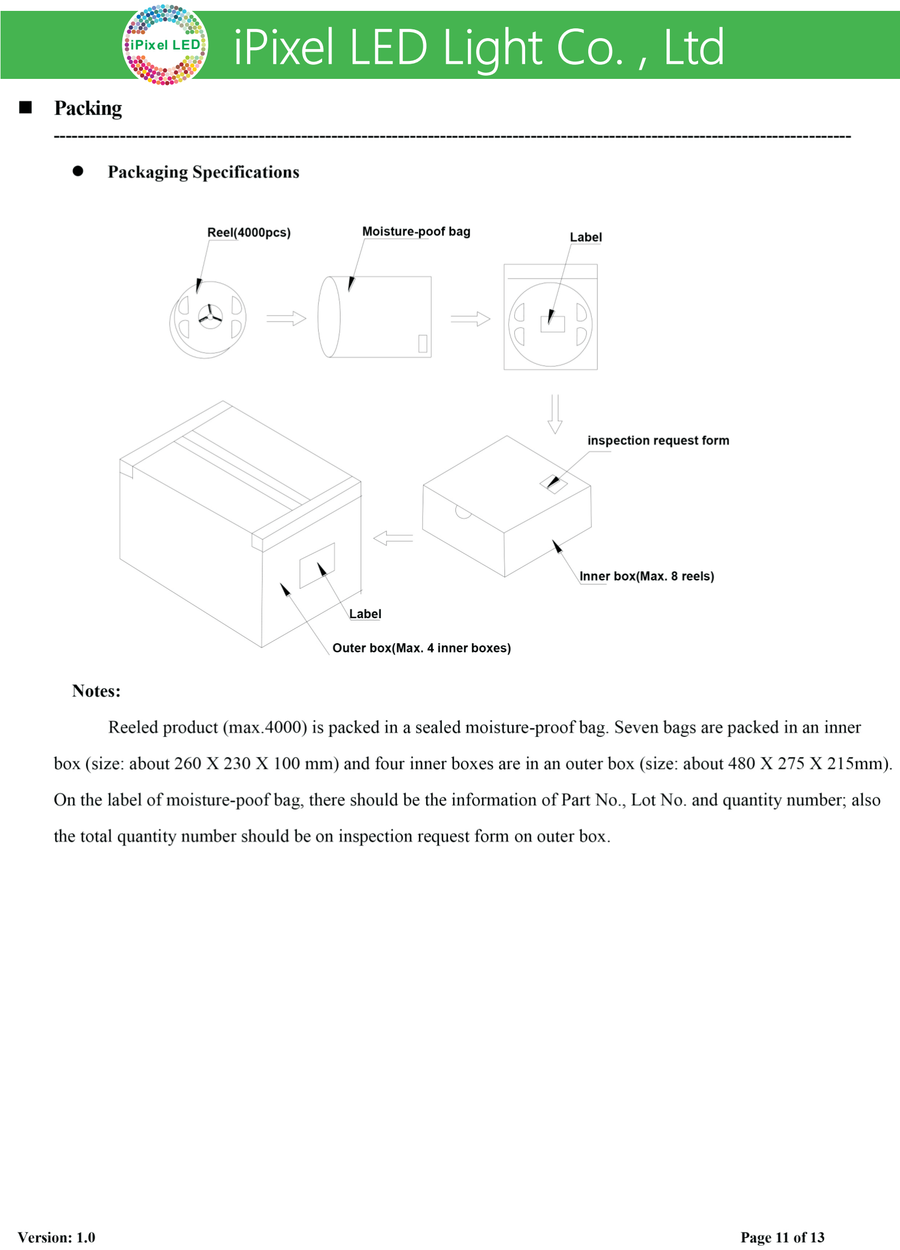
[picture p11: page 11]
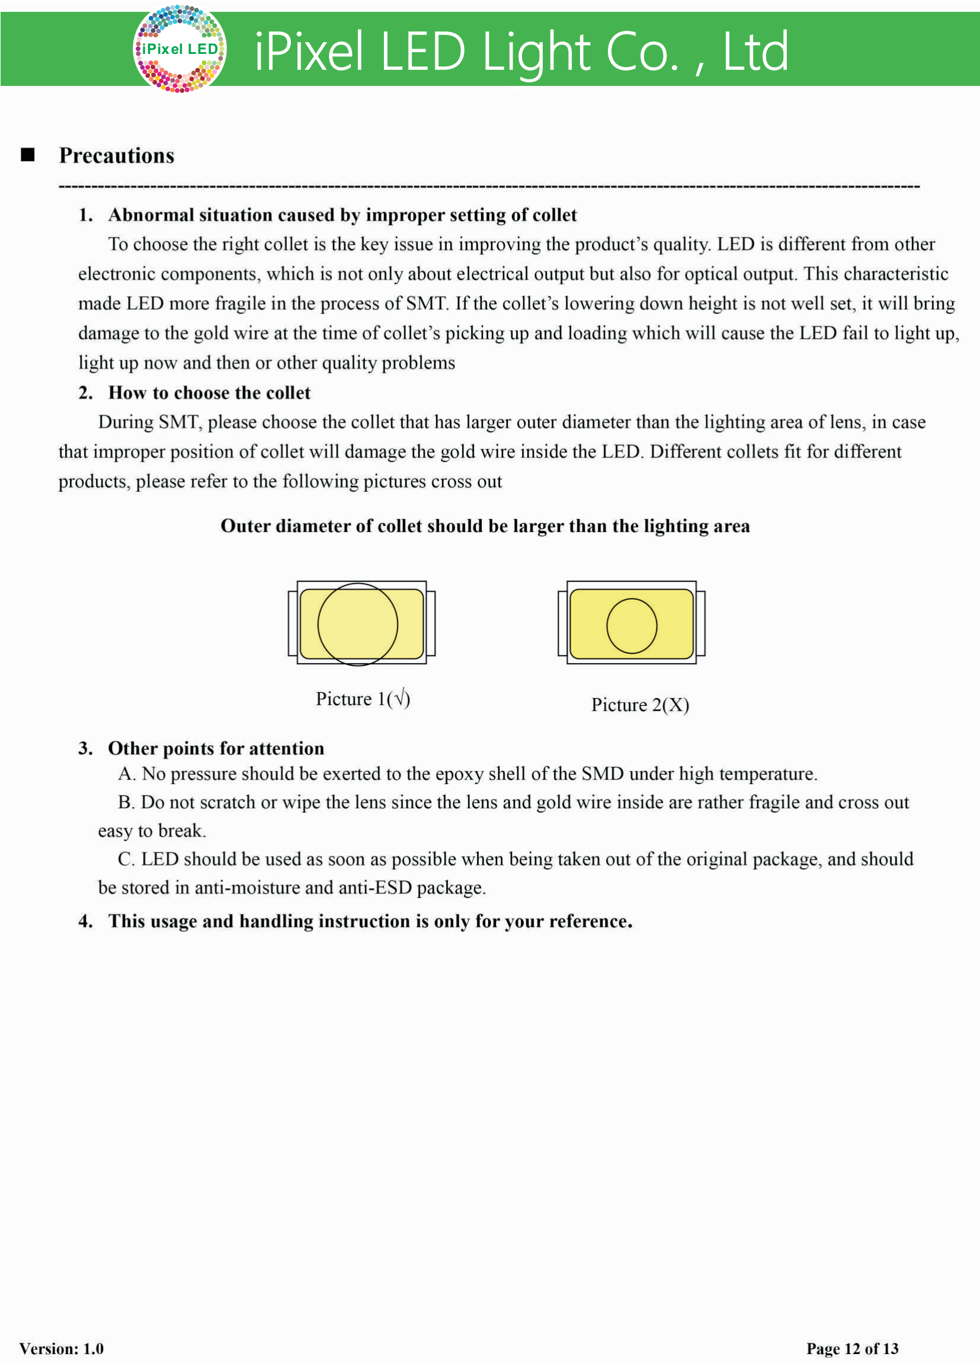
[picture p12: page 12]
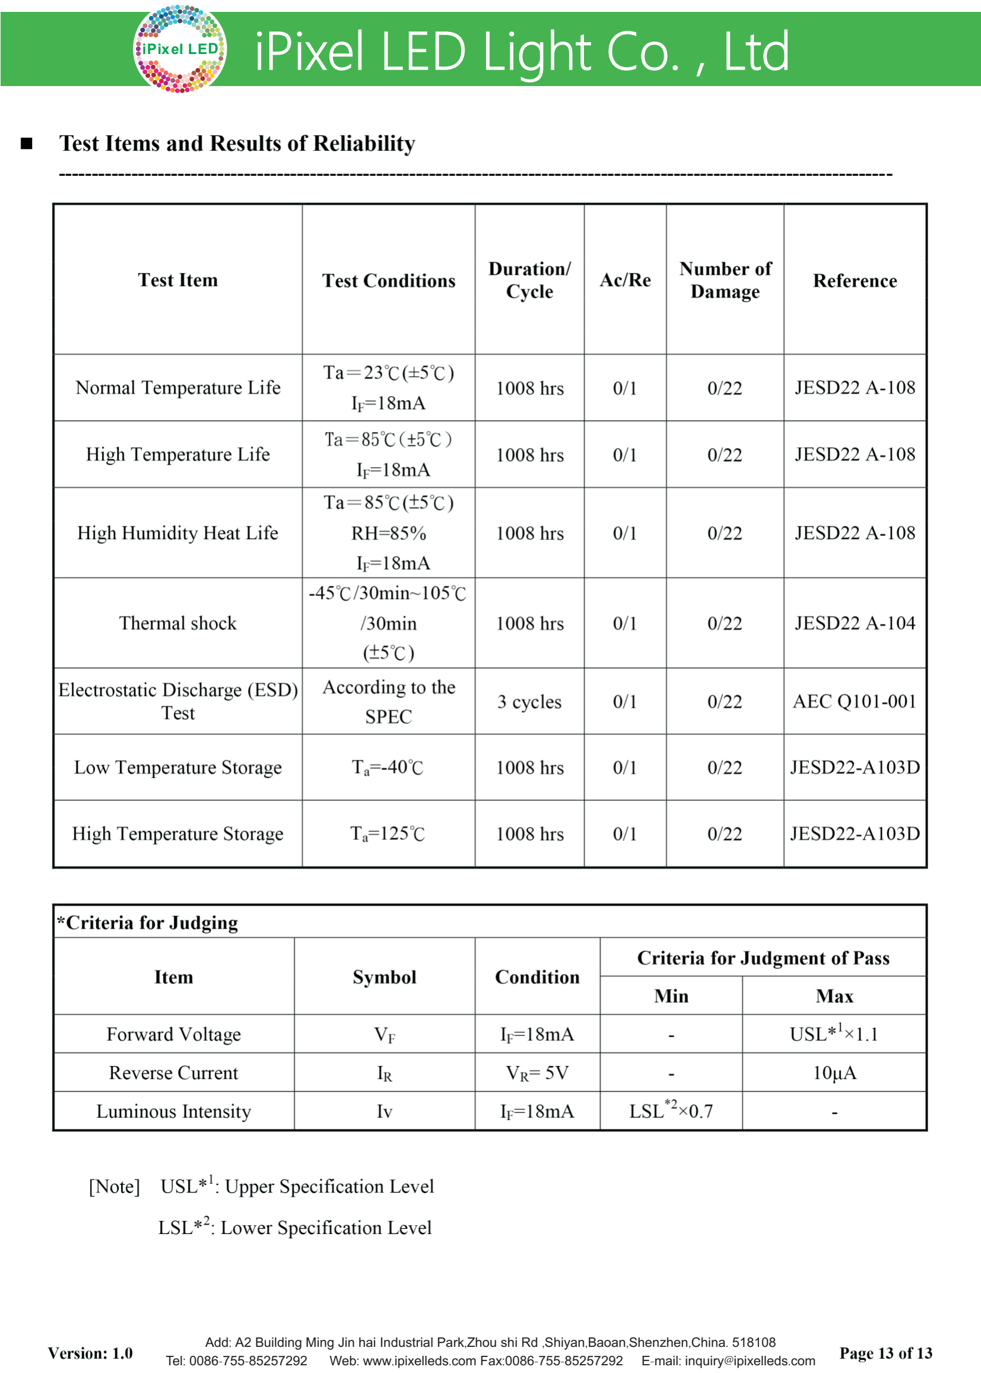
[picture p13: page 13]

Add: A2 Building Ming Jin hai Industrial Park,Zhou shi Rd ,Shiyan,Baoan,Shenzhen,China. 518108
Tel: 0086-755-85257292 | Web: www.ipixelleds.com Fax:0086-755-85257292 | E-mail: inquiry@ipixelleds.com

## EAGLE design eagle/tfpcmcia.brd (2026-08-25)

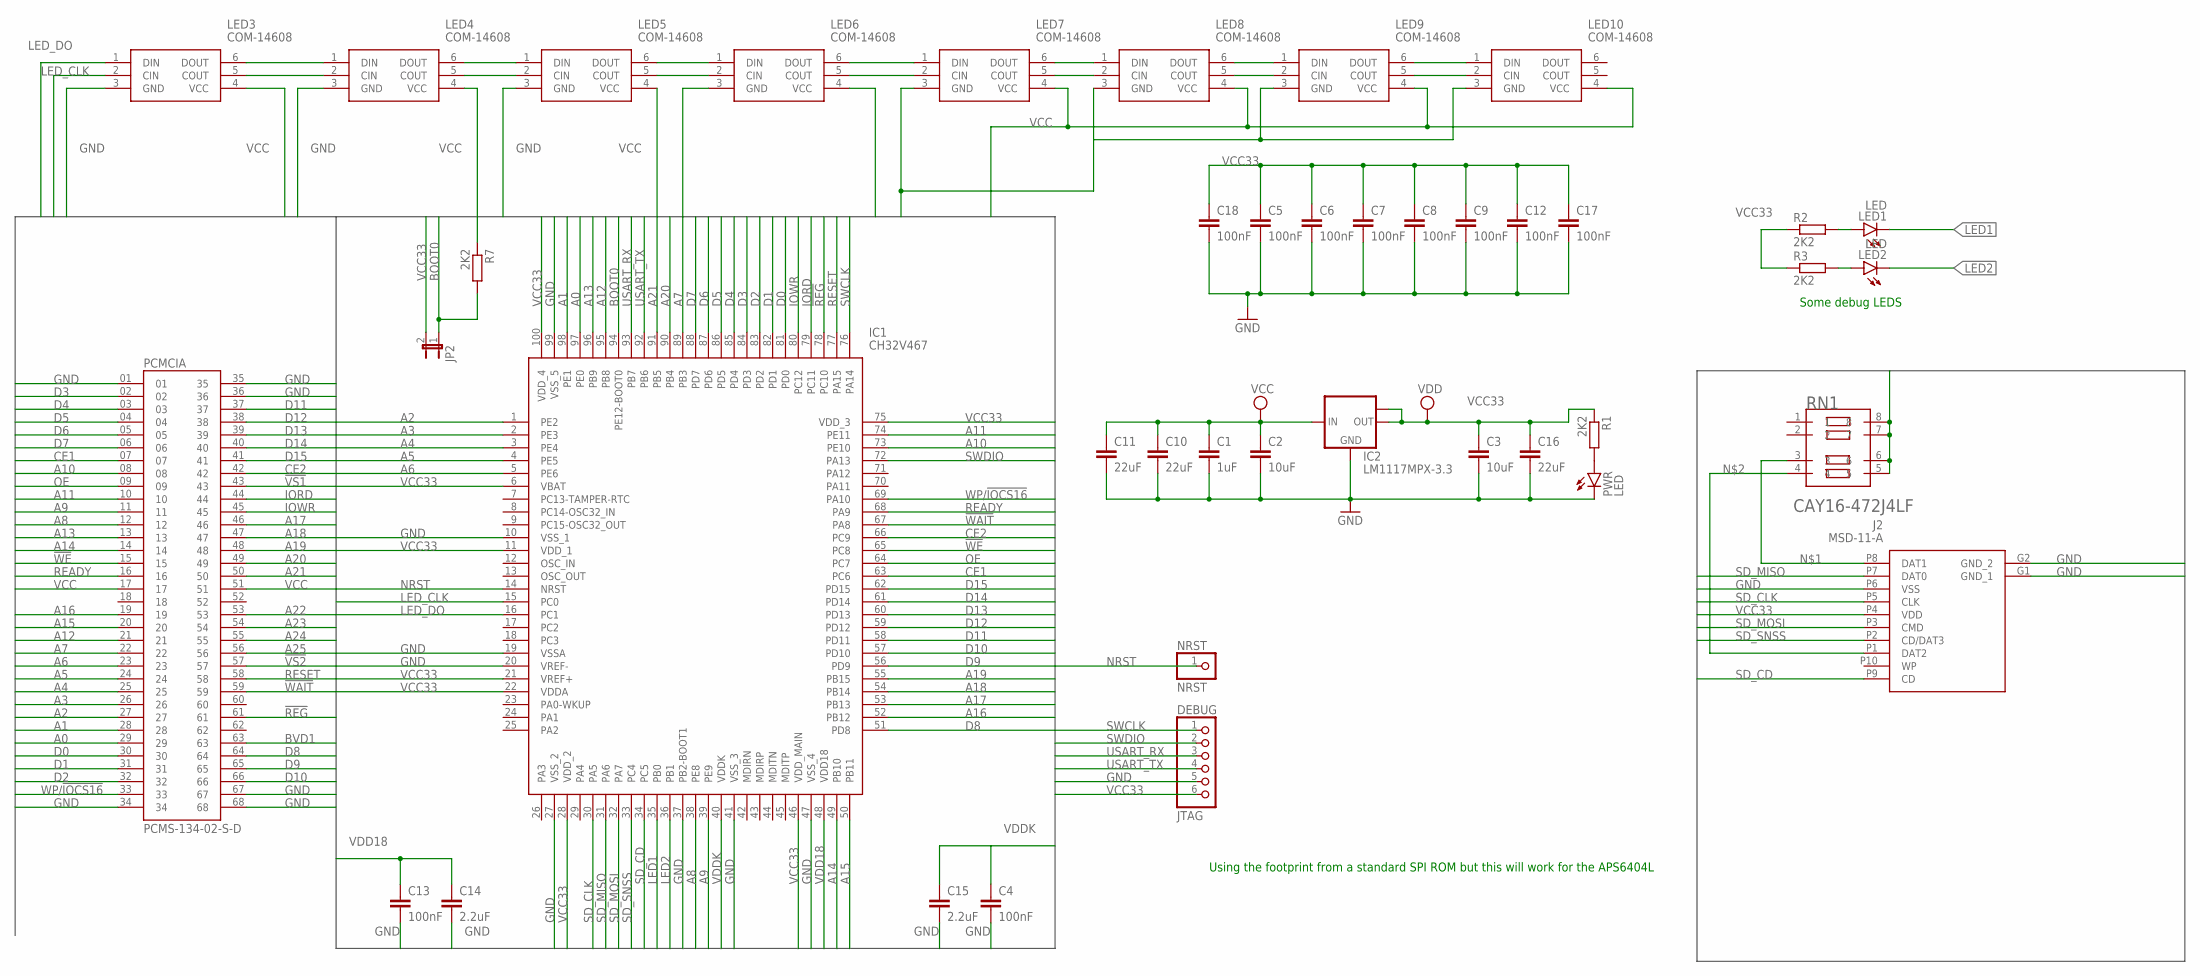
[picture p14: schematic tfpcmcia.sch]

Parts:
C1: 1uF; C1206
C2: 10uF; C0603
C3: 10uF; C1206
C4, C5, C6, C7, C8, C9, C12, C13, C17, C18: 100nF; C0603
C10, C11, C16: 22uF; C1206
C14, C15: 2.2uF; C0603
DEBUG: JTAG; 1X06_ROUND
IC1: CH32V467; QFP50P1600X1600X160-100N
IC2: LM1117MPX-3.3; SOT223
J2: MSD-11-A; MSD11A
JP2: JUMPER-2PTH; 1X02
LED1, LED2: LED; SML0805
LED3, LED4, LED5, LED6, LED7, LED8, LED9, LED10: COM-14608; SON75P200X200X100-6N
NRST: NRST; 1X01
PCMCIA: PCMS-134-02-S-D; SAMTEC_PCMS-134-02-S-D
PWR: LED; SML0805
R1, R2, R3, R7: 2K2; R0603
RN1: CAY16-472J4LF; RESCAXE80P320X160-8N

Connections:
!REG: IC1.78 (PC10), PCMCIA.61
!VS1: PCMCIA.43
!VS2: PCMCIA.57
!WAIT: IC1.67 (PA8), PCMCIA.59
!WE: IC1.65 (PC8), PCMCIA.15
A0: IC1.97 (PE0), PCMCIA.29
A1: IC1.98 (PE1), PCMCIA.28
A2: IC1.1 (PE2), PCMCIA.27
A3: IC1.2 (PE3), PCMCIA.26
A4: IC1.3 (PE4), PCMCIA.25
A5: IC1.4 (PE5), PCMCIA.24
A6: IC1.5 (PE6), PCMCIA.23
A7: IC1.89 (PB3), PCMCIA.22
A8: IC1.38 (PE8), PCMCIA.12
A9: IC1.39 (PE9), PCMCIA.11
A10: IC1.73 (PE10), PCMCIA.08
A11: IC1.74 (PE11), PCMCIA.10
A12: IC1.95 (PB8), PCMCIA.21
A13: IC1.96 (PB9), PCMCIA.13
A14: IC1.49 (PB10), PCMCIA.14
A15: IC1.50 (PB11), PCMCIA.20
A16: IC1.52 (PB12), PCMCIA.19
A17: IC1.53 (PB13), PCMCIA.46
A18: IC1.54 (PB14), PCMCIA.47
A19: IC1.55 (PB15), PCMCIA.48
A20: IC1.90 (PB4), PCMCIA.49
A21: IC1.91 (PB5), PCMCIA.50
A22: PCMCIA.53
A23: PCMCIA.54
A24: PCMCIA.55
A25: PCMCIA.56
BOOT0: IC1.94 (PE12-BOOT0), JP2.1, R7.2
BVD1: PCMCIA.63
CE1: IC1.63 (PC6), PCMCIA.07
CE2: IC1.66 (PC9), PCMCIA.42
D0: IC1.81 (PD0), PCMCIA.30
D1: IC1.82 (PD1), PCMCIA.31
D2: IC1.83 (PD2), PCMCIA.32
D3: IC1.84 (PD3), PCMCIA.02
D4: IC1.85 (PD4), PCMCIA.03
D5: IC1.86 (PD5), PCMCIA.04
D6: IC1.87 (PD6), PCMCIA.05
D7: IC1.88 (PD7), PCMCIA.06
D8: IC1.51 (PD8), PCMCIA.64
D9: IC1.56 (PD9), PCMCIA.65
D10: IC1.57 (PD10), PCMCIA.66
D11: IC1.58 (PD11), PCMCIA.37
D12: IC1.59 (PD12), PCMCIA.38
D13: IC1.60 (PD13), PCMCIA.39
D14: IC1.61 (PD14), PCMCIA.40
D15: IC1.62 (PD15), PCMCIA.41
GND: C1.2, C2.2, C3.2, C4.2, C5.2, C6.2, C7.2, C8.2, C9.2, C10.2, C11.2, C12.2, C13.2, C14.2, C15.2, C16.2, C17.2, C18.2, DEBUG.5, IC1.10 (VSS_1), IC1.19 (VSSA), IC1.20 (VREF-), IC1.27 (VSS_2), IC1.37 (PB2-BOOT1), IC1.41 (VSS_3), IC1.47 (VSS_4), IC1.99 (VSS_5), IC2.1 (GND), J2.G1 (GND_1), J2.G2 (GND_2), J2.P6 (VSS), LED3.3 (GND), LED4.3 (GND), LED5.3 (GND), LED6.3 (GND), LED7.3 (GND), LED8.3 (GND), LED9.3 (GND), LED10.3 (GND), PCMCIA.01, PCMCIA.34, PCMCIA.35, PCMCIA.36, PCMCIA.67, PCMCIA.68, PWR.C, R7.1
IORD: IC1.79 (PC11), PCMCIA.44
IOWR: IC1.80 (PC12), PCMCIA.45
LED1: IC1.35 (PB0), LED1.C
LED2: IC1.36 (PB1), LED2.C
LED_CLK: IC1.15 (PC0), LED3.2 (CIN)
LED_DO: IC1.16 (PC1), LED3.1 (DIN)
unnamed: J2.P8 (DAT1), RN1.3
unnamed: J2.P1 (DAT2), RN1.4
unnamed: LED9.5 (COUT), LED10.2 (CIN)
unnamed: LED9.6 (DOUT), LED10.1 (DIN)
unnamed: LED1.A, R2.2
unnamed: LED2.A, R3.2
unnamed: LED4.5 (COUT), LED5.2 (CIN)
unnamed: LED4.6 (DOUT), LED5.1 (DIN)
unnamed: LED5.6 (DOUT), LED6.1 (DIN)
unnamed: LED5.5 (COUT), LED6.2 (CIN)
unnamed: LED3.5 (COUT), LED4.2 (CIN)
unnamed: LED3.6 (DOUT), LED4.1 (DIN)
unnamed: LED6.5 (COUT), LED7.2 (CIN)
unnamed: PWR.A, R1.2
unnamed: LED6.6 (DOUT), LED7.1 (DIN)
unnamed: LED7.6 (DOUT), LED8.1 (DIN)
unnamed: LED7.5 (COUT), LED8.2 (CIN)
unnamed: LED8.5 (COUT), LED9.2 (CIN)
unnamed: LED8.6 (DOUT), LED9.1 (DIN)
NRST: IC1.14 (NRST), NRST.1
OE: IC1.64 (PC7), PCMCIA.09
READY: IC1.68 (PA9), PCMCIA.16
RESET: IC1.77 (PA15), PCMCIA.58
SD_CD: IC1.34 (PC5), J2.P9 (CD)
SD_CLK: IC1.30 (PA5), J2.P5 (CLK)
SD_MISO: IC1.31 (PA6), J2.P7 (DAT0)
SD_MOSI: IC1.32 (PA7), J2.P3 (CMD)
SD_SNSS: IC1.33 (PC4), J2.P2 (CD/DAT3)
SWCLK: DEBUG.1, IC1.76 (PA14)
SWDIO: DEBUG.2, IC1.72 (PA13)
USART_RX: DEBUG.3, IC1.93 (PB7)
USART_TX: DEBUG.4, IC1.92 (PB6)
VCC: C1.1, C2.1, C10.1, C11.1, IC2.3 (IN), LED3.4 (VCC), LED4.4 (VCC), LED5.4 (VCC), LED6.4 (VCC), LED7.4 (VCC), LED8.4 (VCC), LED9.4 (VCC), LED10.4 (VCC), PCMCIA.17, PCMCIA.51
VCC33: C3.1, C5.1, C6.1, C7.1, C8.1, C9.1, C12.1, C16.1, C17.1, C18.1, DEBUG.6, IC1.6 (VBAT), IC1.11 (VDD_1), IC1.21 (VREF+), IC1.22 (VDDA), IC1.28 (VDD_2), IC1.46 (VDD_MAIN), IC1.75 (VDD_3), IC1.100 (VDD_4), IC2.2 (OUT), IC2.TAB (OUT1), J2.P4 (VDD), JP2.2, R1.1, R2.1, R3.1, RN1.5, RN1.6, RN1.7, RN1.8
VDD18: C13.1, C14.1, IC1.48 (VDD18)
VDDK: C4.1, C15.1, IC1.40 (VDDK)
WP/!IOCS16: IC1.69 (PA10), PCMCIA.33

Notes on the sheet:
Using the footprint from a standard SPI ROM but this will work for the APS6404L
Some debug LEDS

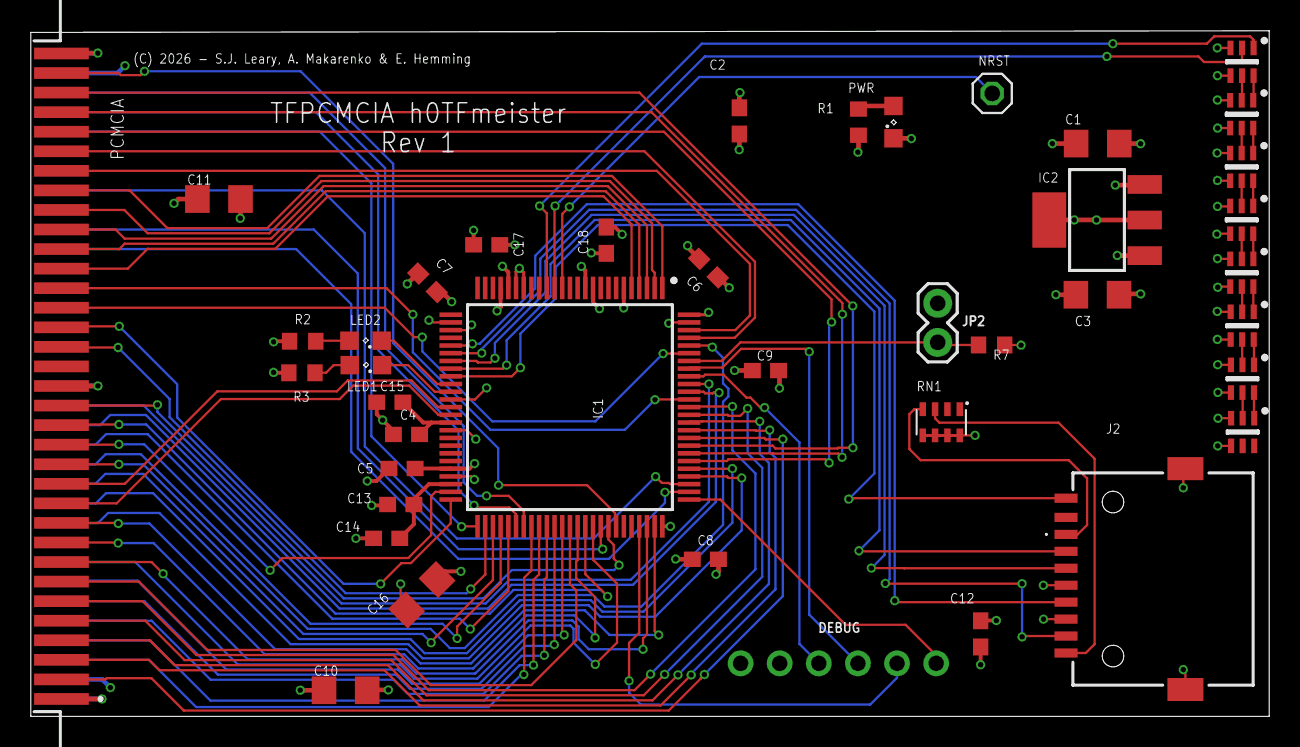
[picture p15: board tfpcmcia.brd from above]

Board: 4 copper layers, 80.4 x 44.5 mm, 41 parts (0 on the bottom side), 88 nets.

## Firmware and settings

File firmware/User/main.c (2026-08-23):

#include "debug.h"
#include "gpio.h"
#include "led.h"
#include "pcmcia.h"
#include "psram.h"


int main(void) {

    SystemCoreClockUpdate();
    Delay_Init();
    GPIO_Config();
    USART1_Init(115200);
    PCMCIA_Init();

    printf("tfpcmcia v0.4 (CH32V467) ready\r\n");

    /* Probe printed AFTER the banner: if the 0x8000_0000 window is not
     * accessible out of reset this access hangs or faults, and the last
     * UART line tells us exactly where. */
    PSRAM_Init();
    printf("PSRAM probe: ");
    printf(PSRAM_Probe() ? "OK\r\n" : "FAILED\r\n");

    LED2_GPIO_Port->OUTDR ^= LED2_Pin;

    uint16_t frame = 0;
    uint16_t last_ctrl = 0xFFFF;
    while (1)
    {
        uint16_t ctrl = PCMCIA_BoardCtrl() & 0x03;
        if (ctrl != last_ctrl) {
            frame = 0;
            last_ctrl = ctrl;
        }
        switch (ctrl) {
            case 0:  APA102_GreenRamp(frame); break;
            case 1:  APA102_Kitt(frame);      break;
            case 2:  APA102_AmberBlink(frame); break;
            case 3:  APA102_FB(led_fb);       break;
            default: break;
        }
        frame++;
        Delay_Ms(1);
    }

    //PCMCIA_PollLoop();
}

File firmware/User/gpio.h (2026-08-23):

#ifndef __GPIO_H
#define __GPIO_H

#include "debug.h"

/* CH32V467VET6 pin map — docs/ch32v467-migration-plan.md §7.
 * Every Amiga-facing signal sits on a 5V-tolerant (FT) pad.
 * PE7/PE13/PE14/PE15 are not bonded out on this package. */

void GPIO_Config(void);

/* Control outputs - Port A */
#define WAIT_GPIO_Port           GPIOA
#define WAIT_Pin                 GPIO_Pin_8   /* active LOW: LOW inserts waits */
#define READY_GPIO_Port          GPIOA
#define READY_Pin                GPIO_Pin_9   /* active HIGH */
#define IOCS16_GPIO_Port         GPIOA
#define IOCS16_Pin               GPIO_Pin_10  /* LOW = 16-bit port */
#define RESET_GPIO_Port          GPIOA
#define RESET_Pin                GPIO_Pin_15  /* input, EXTI15 */

/* SD card - SPI1 default mapping (freed by dropping the external SPI RAM) */
#define SD_CLK_GPIO_Port         GPIOA
#define SD_CLK_Pin               GPIO_Pin_5
#define SD_MISO_GPIO_Port        GPIOA
#define SD_MISO_Pin              GPIO_Pin_6
#define SD_MOSI_GPIO_Port        GPIOA
#define SD_MOSI_Pin              GPIO_Pin_7
#define SD_SNSS_GPIO_Port        GPIOC
#define SD_SNSS_Pin              GPIO_Pin_4
#define SD_CD_GPIO_Port          GPIOC
#define SD_CD_Pin                GPIO_Pin_5   /* LOW = card inserted */

/* Debug - SWD on PA13/PA14 (default), USART1 remapped to PB6/PB7 */
#define SWDIO_GPIO_Port          GPIOA
#define SWDIO_Pin                GPIO_Pin_13
#define SWCLK_GPIO_Port          GPIOA
#define SWCLK_Pin                GPIO_Pin_14
#define USART_TX_GPIO_Port       GPIOB
#define USART_TX_Pin             GPIO_Pin_6
#define USART_RX_GPIO_Port       GPIOB
#define USART_RX_Pin             GPIO_Pin_7

/* Status LEDs + APA102 chain */
#define LED1_GPIO_Port           GPIOB
#define LED1_Pin                 GPIO_Pin_0
#define LED2_GPIO_Port           GPIOB
#define LED2_Pin                 GPIO_Pin_1
#define LED_CLK_GPIO_Port        GPIOC
#define LED_CLK_Pin              GPIO_Pin_0
#define LED_DO_GPIO_Port         GPIOC
#define LED_DO_Pin               GPIO_Pin_1

/* PB2 is BOOT1, strapped to GND on the board. Never drive it. */

/* PCMCIA control inputs - Port C (PC6..PC12, all FT).
 * Bit positions match the old PB6..PB12 layout, so every mask in
 * pcmcia.h keeps its value. */
#define CE1_GPIO_Port            GPIOC
#define CE1_Pin                  GPIO_Pin_6   /* EXTI6 */
#define OE_GPIO_Port             GPIOC
#define OE_Pin                   GPIO_Pin_7
#define WE_GPIO_Port             GPIOC
#define WE_Pin                   GPIO_Pin_8
#define CE2_GPIO_Port            GPIOC
#define CE2_Pin                  GPIO_Pin_9   /* EXTI9 */
#define REG_GPIO_Port            GPIOC
#define REG_Pin                  GPIO_Pin_10
#define IORD_GPIO_Port           GPIOC
#define IORD_Pin                 GPIO_Pin_11
#define IOWR_GPIO_Port           GPIOC
#define IOWR_Pin                 GPIO_Pin_12

/* Address bus (22 bits, split - PE7 does not exist on this package):
 *   A0-A6   PE0-PE6
 *   A7      PB3
 *   A8-A11  PE8-PE11
 *   A12-A19 PB8-PB15
 *   A20,A21 PB4,PB5
 * Reassembly macros live in pcmcia.h. */

/* Data bus D0-D15 on GPIOD - unchanged from the CH32V307 design */

#endif /* __GPIO_H */

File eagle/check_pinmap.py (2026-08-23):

#!/usr/bin/env python3
"""Check IC1 wiring in tfpcmcia.sch against the CH32V467VET6 target pin map.

Target map is docs/ch32v467-migration-plan.md section 7.
Reads the schematic directly, so no netlist regeneration is needed.

    .venv/bin/python check_pinmap.py [tfpcmcia.sch]

Exit status is 0 only when every pin matches.
"""
import sys
from pathlib import Path
from lxml import etree

HERE = Path(__file__).resolve().parent
SCH = Path(sys.argv[1]) if len(sys.argv) > 1 else HERE / "tfpcmcia.sch"
LBR = HERE / "SamacSys_Parts.lbr"
PART = "IC1"

# --- target: pin name -> net name ----------------------------------------
TARGET = {}
for i in range(16):
    TARGET[f"PD{i}"] = f"D{i}"
for i in range(7):
    TARGET[f"PE{i}"] = f"A{i}"                       # PE0-PE6  -> A0-A6
TARGET["PB3"] = "A7"                                 # fills the PE7 gap
for i in range(4):
    TARGET[f"PE{8+i}"] = f"A{8+i}"                   # PE8-PE11 -> A8-A11
for i in range(8):
    TARGET[f"PB{8+i}"] = f"A{12+i}"                  # PB8-PB15 -> A12-A19
TARGET["PB4"], TARGET["PB5"] = "A20", "A21"
TARGET.update({                                      # control in
    "PC6": "CE1", "PC7": "OE", "PC8": "!WE", "PC9": "CE2",
    "PC10": "!REG", "PC11": "IORD", "PC12": "IOWR", "PA15": "RESET",
})
TARGET.update({                                      # control out
    "PA8": "!WAIT", "PA9": "READY", "PA10": "WP/!IOCS16",
})
TARGET.update({                                      # peripherals
    "PA5": "SD_CLK", "PA6": "SD_MISO", "PA7": "SD_MOSI",
    "PC4": "SD_SNSS", "PC5": "SD_CD",
    "PC0": "LED_CLK", "PC1": "LED_DO",
    "PB0": "LED1", "PB1": "LED2",
    "PB6": "USART_TX", "PB7": "USART_RX",
    "PA13": "SWDIO", "PA14": "SWCLK",
    "PE12-BOOT0": "BOOT0", "NRST": "NRST",
})
for p in ("VSS_1", "VSS_2", "VSS_3", "VSS_4", "VSS_5", "VSSA", "VREF-"):
    TARGET[p] = "GND"
# BOOT1 must be strapped low: with BOOT0 high (JP2 fitted for ISP) a floating
# BOOT1 leaves the boot source indeterminate. Datasheet Note 5 also asks for a
# pull-down to avoid extra current in low-power modes.
TARGET["PB2-BOOT1"] = "GND"
for p in ("VDD_1", "VDD_2", "VDD_3", "VDD_4", "VDD_MAIN", "VDDA", "VREF+", "VBAT"):
    TARGET[p] = "VCC33"
TARGET["VDDK"] = "VDDK"      # own rail, 0.1uF || 2.2uF to GND
TARGET["VDD18"] = "VDD18"    # own rail, 0.1uF || 2.2uF to GND

# pins that must be left unconnected
NC = {
    "MDIRN": "Ethernet unused", "MDIRP": "Ethernet unused",
    "MDITN": "Ethernet unused", "MDITP": "Ethernet unused",

    "PA0-WKUP": "spare", "PA1": "spare", "PA2": "spare", "PA3": "spare",
    # audio output stage (IC4/C13/C14) removed - BVD2 no longer driven
    "PA4": "spare (audio stage removed)",
    # USB breakout jumper JP1 removed - programming is SWD + UART only
    "PA11": "spare (USB removed)", "PA12": "spare (USB removed)",
    "PC2": "spare", "PC3": "spare",
    "PC13-TAMPER-RTC": "unused", "PC14-OSC32_IN": "unused",
    "PC15-OSC32_OUT": "unused",
    "OSC_IN": "unused (internal RC)", "OSC_OUT": "unused (internal RC)",
}

# non-5V-tolerant pins: nothing on the Amiga bus may land here
NON_FT = ({f"PA{i}" for i in range(8)} | {"PA0-WKUP", "PA11", "PA12"}
          | {"PB0", "PB1", "PB6", "PB7"} | {f"PC{i}" for i in range(6)}
          | {"PC13-TAMPER-RTC", "PC14-OSC32_IN", "PC15-OSC32_OUT"})
AMIGA = ({f"A{i}" for i in range(22)} | {f"D{i}" for i in range(16)}
         | {"CE1", "CE2", "OE", "!WE", "!REG", "IORD", "IOWR", "RESET",
            "!WAIT", "READY", "WP/!IOCS16"})


def main():
    root = etree.parse(str(SCH)).getroot()
    lbr = etree.parse(str(LBR)).getroot()
    pad = {c.get("pin"): int(c.get("pad")) for c in
           lbr.find(".//deviceset[@name='CH32V467VET6']").findall(".//connect")}

    actual = {}
    for net in root.findall(".//net"):
        for seg in net.findall("segment"):
            for pr in seg.findall("pinref"):
                if pr.get("part") == PART:
                    actual.setdefault(pr.get("pin"), []).append(net.get("name"))

    wrong, missing, extra, dupe = [], [], [], []
    for pin, want in sorted(TARGET.items(), key=lambda kv: pad.get(kv[0], 0)):
        got = actual.get(pin)
        if got is None:
            missing.append((pad.get(pin), pin, want))
        elif len(got) > 1:
            dupe.append((pad.get(pin), pin, got))
        elif got[0] != want:
            wrong.append((pad.get(pin), pin, got[0], want))
    for pin, why in sorted(NC.items(), key=lambda kv: pad.get(kv[0], 0)):
        if pin in actual:
            extra.append((pad.get(pin), pin, actual[pin][0], why))

    unsafe = [(pad.get(p), p, n[0]) for p, n in actual.items()
              if p in NON_FT and n[0] in AMIGA]

    ok = len(TARGET) - len(wrong) - len(missing) - len(dupe)
    print(f"IC1 / CH32V467VET6 pin map: {ok}/{len(TARGET)} correct\n")

    def show(title, rows, fmt):
        if rows:
            print(f"{title} ({len(rows)})")
            for r in rows:
                print("   " + fmt(r))
            print()

    show("UNSAFE - Amiga bus signal on a non-5V-tolerant pin", unsafe,
         lambda r: f"pad {r[0]:>3}  {r[1]:<16} {r[2]}")
    show("WRONG NET", wrong,
         lambda r: f"pad {r[0]:>3}  {r[1]:<16} {r[2]:<14} -> should be {r[3]}")
    show("NOT CONNECTED", missing,
         lambda r: f"pad {r[0]:>3}  {r[1]:<16} needs {r[2]}")
    show("SHOULD BE UNCONNECTED", extra,
         lambda r: f"pad {r[0]:>3}  {r[1]:<16} on {r[2]:<14} ({r[3]})")
    show("PIN ON MULTIPLE NETS", dupe,
         lambda r: f"pad {r[0]:>3}  {r[1]:<16} {r[2]}")

    bad = bool(wrong or missing or extra or dupe or unsafe)
    print("FAIL" if bad else "PASS - pin map matches the target")
    return 1 if bad else 0


if __name__ == "__main__":
    sys.exit(main())

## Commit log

2026-01-29 Finished routing, unchecked schematic
    [tfpcmcia.brd, tfpcmcia.sch]
2026-01-29 updated the audio section
    [tfpcmcia.brd, tfpcmcia.sch]
2026-01-29 fixed BOOT0
    [tfpcmcia.brd, tfpcmcia.sch]
2026-01-29 Updated READY signal and updated pinout specs
    [tfpcmcia.brd, tfpcmcia.sch]
2026-01-30 added blinkenlights and gathered notes on spi ram usage
    [tfpcmcia.brd, tfpcmcia.sch]
2026-01-30 tightened DRC
    [tfpcmcia.brd]
2026-03-08 Add tfpcmcia.device driver and boot ROM sources
2026-03-12 add initial firmware: CH32V307 PCMCIA bus emulation returning BEEF/BABE
    - Dockerised build using local MRS toolchain (riscv-none-embed-gcc)
    - EXTI9_5 VTF interrupt handler drives data bus on UDS/LDS assertion
    - Common memory returns 0xBEEF, attribute memory returns 0xBABE
    - BUS16() macro compensates for Gayle byte-lane swap on A600/A1200
    - UART debug on PA9 at 115200, heartbeat LED on PC8
    - Top-level Makefile delegates build/clean to Docker container
    - DiagROM helper scripts in scripts/
    - Updated .gitignore for firmware build artefacts and MRS installer
    [tfpcmcia.brd, tfpcmcia.sch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]
2026-03-12 untrack eagle generated outputs, update gitignore
    BOM CSVs, CPL, netlist, Eagle scripts, gerber zip and folder are all
    produced by the eagle/Makefile and should not be in version control.
    [gerber_job.gbrjob, tfpcmcia_Legend_Bot.GBO, tfpcmcia_Legend_Top.GTO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]
2026-03-12 refactor PCMCIA handler: address decode + typed dispatch functions
    - Decode full 22-bit address (GPIOE A0-A15, GPIOB[0:5] A16-A21)
    - Dispatch to PCMCIA_Memory_Read/Write and PCMCIA_Reg_Read/Write
    - Write stubs NOP; reads return BEEF (common) and address echo (attribute)
    - Mark all dispatch functions always_inline — required because WCH-Interrupt-fast
    does not save caller-saved registers, so any real call produces garbage
2026-03-13 Board updates for revision 1
    [tfpcmcia.brd, tfpcmcia.sch]
2026-03-15 Driver read code wokring and attributes implemented
2026-03-19 Fix SD card SPI init and PCMCIA handler for real hardware
    Driver:
    - Move SPI registers to IO space (0xA20200)
    - Fix SdReadSector/SdWriteSector addressing: use block address
    directly for SDHC (was incorrectly shifting lba << 9)
    - Add 8 dummy clocks after every CS deassert to allow SD card
    to release MISO before next command
    Firmware:
    - Switch PCMCIA_Handler to polled loop in main() — interrupt
    path removed pending timing investigation
    - Add separate PCMCIA_IO_Read / PCMCIA_IO_Write dispatch for
    IO space (addr >= 0x220200); OE/IOR/IOW handled distinctly
    - Latch SPI RX byte into sd_rx_byte on write, return it on read —
    fixes double-transfer bug where each SpiByte() was doing two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
    [gpio.c, main.c, pcmcia.c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]
2026-03-19 Pass card type to SdReadSector/SdWriteSector as parameter
    Removes static sd_type from spi.c and passes cardType explicitly,
    allowing correct address calculation (block vs byte) based on card type
    at each call site via db->db_CardType.
    [spi.c]
2026-03-19 Toggle CS between ACMD41 retries, increase SDv2 retry count
    SD spec requires CS to be deasserted between commands in SPI mode.
    Add CS toggle before each CMD55/ACMD41 pair in both SDv2 and SDv1
    init loops. Increase SDv2 retry count to 100000 to cover the card's
    1-second initialisation window.
2026-03-19 Drive LED2 from SD card chip select
    LED2 mirrors the SD CS line: on when CS is asserted (low), off when
    CS is deasserted (high).
2026-03-19 Adapt SD driver from FPGAArcade card.c
    Rewrite spi.c based on the FPGAArcade Replay card.c (MPL 2.0):
    - 3-attempt init with 100ms delay between retries
    - 1-second ACMD41 timeout loop (~10000 iterations)
    - MMC support via CMD1
    - CMD16 block length set for non-SDHC cards
    - CMD13 post-read/write status check
    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
2026-03-21 Add SPIRAM AddMemList, pipelined SPI read/write, and PCMCIA refactor
    - Probe APS6404L at 0x620000 and add 3.875MB to AmigaOS as MEMF_PUBLIC|MEMF_FAST at priority -20
    - Rewrite SPIRAM_Read16/Write16 with pipelined SPI (RXNE/TXE interleaved) and add SPIRAM_Write8
    - Place PCMCIA_Handler and PCMCIA_PollLoop in .ramtext for faster execution
    - Expand ROM window to 128KB (0x20000), fix word-align mask
    - Refactor PCMCIA_Handler: early exit on idle strobe, fast OE path for attr/reg reads, add WE write path for SPIRAM
    - Rename Init_PCMCIA -> PCMCIA_Init, extract poll loop to PCMCIA_PollLoop
    [deviceheader.c, main.c, pcmcia.c]
2026-03-21 increased spiram speed to 36Mhz and switched to 16 bit words for word accesses
2026-03-22 Add PcmciaConstants struct for RISC-V GP-relative optimisation
    Replace large immediate constants in PCMCIA_Handler and helpers with
    fields from a PcmciaConstants struct (K) placed in .sdata, allowing the
    compiler to reach each value with a single GP-relative lw instead of
    a lui+addi pair. Switch to poll-loop mode (VTF IRQ disabled), -Ofast,
    and ilp32 ABI.
    [main.c, pcmcia.c]
2026-03-22 Add write-back SPIRAM cache and limit OS memory to 1MB
    - spiram.h: replace single-word SPI functions with a 512-line x 64-byte
    direct-mapped write-back cache (32KB total in SRAM). Writes go to the
    cache only; SPIRAM is written on dirty-line eviction. SPIRAM_ReadBurst
    and SPIRAM_WriteBurst handle 64-byte cache line fills and flushes in
    pipelined 16-bit SPI mode. WriteBurst drains all N+2 RX words to avoid
    leaving stale data in the SPI FIFO between transactions.
    - driver/deviceheader.c: limit AddMemList to 1MB (0x100000 bytes) from
    0x620000, with priority 0.
    [deviceheader.c]
2026-03-23 Add dual DIAG+XIP CIS boot flow with BOARD_CTRL switching
2026-03-26 reverted XIP on A600
    [pcmcia.c]
2026-03-26 Add LED mode switching and document full functionality
    - firmware: add APA102 framebuffer mode (7 RGB pixels via IO writes at
    $A20220); KITT animation is default, switches to host-controlled FB
    when BOARD_CTRL bit 0 is set by the driver
    - firmware: expose PCMCIA_BoardCtrl() getter and led_fb[] array
    - README: complete rewrite covering hardware, memory map, all I/O
    registers, boot sequence, SPIRAM cache, LED modes, PCMCIA interface,
    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
2026-03-27 Add green ramp LED mode, PB13 reset interrupt, and fix BOARD_CTRL writes
    - LED: add APA102_GreenRamp (4s linear ramp to full green, holds)
    - LED: expand dispatch to 4-mode switch on full BOARD_CTRL value (0=ramp, 1=KITT, 2=nop, 3=FB)
    - LED: reset frame counter on mode change; frame increments every tick
    - Firmware: wire EXTI13 (PB13/RESET falling edge) to PCMCIA_ResetHandler at NVIC priority 0x40
    - Firmware: PCMCIA_ResetHandler clears board_ctrl and deasserts SD CS on card reset
    - Driver: fix BOARD_CTRL register address (A00206 -> A20206); write 0 on init, remove spurious write in trampoline
    - Firmware: add led.c to Makefile; remove erroneous board_ctrl=0 from SPI_CS write path
    [deviceheader.c, gpio.c, led.c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]
2026-03-27 Remove non-tfpcmcia BootNodes from MountList before starting DOS
2026-03-28 more A600 fixes. its very sulky. probably wont work in the morning
    [deviceheader.c, led.c, main.c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]
2026-03-28 another minor a600 fix
    [pcmcia.c]
2026-03-28 fixed iow on A600. added amber blinkenlights effect
    [led.c, main.c]
2026-04-04 Fix the cache writeback issue
    [spi.c]
2026-08-22 CH32V467 upgrade
    [tfpcmcia.brd, tfpcmcia.sch]
2026-08-22 final updates
    [tfpcmcia.brd, tfpcmcia.sch]
2026-08-23 Port firmware to CH32V467 on the official WCH CH32V4x7 SDK
    Completes the CH32V307+APS6404L -> CH32V467VET6 migration on the software
    side. The board (committed in 8249761..8d88e73) is unchanged here.
    SDK: replace the ch32v30x peripheral library, system file and startup
    with the CH32V4x7 SDK from openwch/ch32v407_ch32v467. The V4x7 clock tree
    (SYSPLL, HPRE, 20 MHz HSI) and PSRAM controller are not V307-compatible,
    so the earlier V307-SDK build could not have brought the PSRAM up.
    Clock: custom SYSCLK_200MHz_HCLK_200MHz_HSI (HSI x10, HPRE/1). PSRAM is
    clocked by SYSCLK, so this runs core and PSRAM both at their any-lot
    200 MHz maxima; the PCMCIA ISR runs ~39% faster than the proven 144 MHz
    V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
2026-08-25 fixing the isolation width@ ~
    [tfpcmcia.brd]
2026-08-25 adding checks for the gerbers2
2026-10-11 Fix CH32V467 boot: stay in machine mode, build for rv32imac
    The SDK startup set mstatus=0x688, which mret's into user mode (MPP=0).
    With no PMP entries configured the V467 core then takes an instruction
    access fault fetching main (mcause=1, mepc=main) and never runs. Use
    0x1E88 so main runs in machine mode with vector + interrupts enabled.
    The V467 core has no FPU (misa has no F bit), so build with
    -march=rv32imac instead of rv32imafc to keep the compiler from ever
    emitting FP instructions.
    Verified on hardware: boots to "tfpcmcia v0.4 (CH32V467) ready" and
    "PSRAM probe: OK" on USART1.
2026-10-11 Fix PSRAM fixed-latency setup clobbering the read latency code
    SetRdLatency's Read_Fixed branch rewrote MR0 with only the LT bit
    (Read_Fixed<<5), resetting the read-latency code to 0 (66 MHz) while the
    controller kept the 200 MHz latency. Every PSRAM read then returned the
    next 16-bit beat (read at A gave the data stored at A+2), so the Amiga
    crashed with an address error (8000 0003) as soon as a task was
    allocated in card RAM.
    Keep the latency code when setting LT. Verified with a debugger pattern
    test (384 mismatches -> 0, byte RMW correct) and on an A1200: boot ROM,
    Simon demo and tfpcmcia.device run, 1 MB card RAM is added and used
    without crashing.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
2026-10-11 Add PCMCIA cycle counters and optional bus trace (make TRACE=1)
    The handler now counts each outcome (glitch, attribute read, timeout,
    memory read/write, I/O read/write, reset) in pcmcia_stats[], readable
    over the debugger. The increment happens after /WAIT is released, so
    bus timing is unchanged and the handler stays call-free.
    With TRACE=1 the first 128 cycles after each Amiga reset are recorded
    (address, cycle kind, control lines, value driven on the data bus) and
    printed on USART1 together with a once-a-second counter summary. This
    is what located the PSRAM read-latency bug. Off by default; run
    "make clean" when switching TRACE, as objects do not depend on it.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
2026-10-11 Add all card RAM, PSRAM VDD18 boost, and RAM diagnostics
    Driver (tfpcmcia.device):
    - Add the whole common-memory window above the boot ROM as fast RAM,
    $620000-$9FFFFF (3968 KB), instead of a fixed 1 MB at $640000.
    - SPIRAM_MEMTEST: optional boot-time test of all card RAM (move.l and
    word read-back, byte-lane RMW); RAM is not added if it fails.
    - SPIRAM_ADD: build with 0 to leave the card RAM out (no fast RAM).
    - GAYLE_DIAG: dump Gayle card status/IRQ registers and the task at
    $7312 plus Exec's LastAlert, for chasing boot-time Gurus.
    MEMTEST and GAYLE_DIAG default off.
    Boot ROM: vasm -DTESTKIT builds a diagnostic ROM that adds the card RAM
    and runs Amiga Test Kit (driver/testkit.bin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

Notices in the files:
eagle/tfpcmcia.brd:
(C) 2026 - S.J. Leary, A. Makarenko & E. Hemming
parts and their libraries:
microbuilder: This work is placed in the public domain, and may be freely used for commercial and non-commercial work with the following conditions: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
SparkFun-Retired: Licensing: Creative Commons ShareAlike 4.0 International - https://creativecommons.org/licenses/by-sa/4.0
